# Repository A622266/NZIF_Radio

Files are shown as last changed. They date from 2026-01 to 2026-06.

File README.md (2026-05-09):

# NZIF Radio

Near-zero-IF radio architecture built around an 8-phase harmonic rejection polyphase mixer and audio-rate ADC/DAC signal processing.

This board is the NZIF core: it converts differential RF into low-frequency quadrature baseband, then digitizes and processes the result with audio-rate converters and a SigmaDSP. The RF front-end board handles the PA, T/R switch, a band-switched quasi-elliptic LPF bank shared between TX and RX, a directional coupler for SWR and power measurement at the antenna port, and two receive-path high-pass filters that together form a band-specific preselector. The receive and transmit mixer/baseband cores are on this board.

## Design goals

- Suppress the 3rd, 5th, and 7th LO harmonics with an 8-phase harmonic rejection mixer, reducing reliance on RF bandpass filters on this board.
- Use polyphase mixing and phase-domain harmonic suppression to minimize analog RF selectivity requirements.
- Avoid a conventional high-IF architecture: the design is near-zero-IF, using 192 kHz ADC/DAC sampling with a digital NCO offset to stay away from DC and 1/f noise.
- Keep the Rx and Tx front end compact and fully differential, while placing the PA and post-PA filters on a separate board.
- Preserve differential signal flow from the RF mixer through the driver amps and into the audio-rate converters.
- Share a quasi-elliptic post-PA LPF bank between TX and RX on the RF front-end board: on transmit it suppresses PA harmonics for regulatory compliance; on receive the same bank acts as a band-specific preselector with deep notch traps at adjacent-band interference sources.
- Place a directional coupler at the antenna interface (after the LPF bank) for accurate forward/reflected power and SWR measurement at the clean fundamental; use a calibration tap to inject a spectrally clean reference tone into the receive path for I/Q calibration.
- Apply strategically placed high-pass filters in the receive chain: a fixed ~1.6 MHz filter to block AM broadcast on all bands, and a switched ~9 MHz filter to suppress lower-band interference on 30m and above.

## Architecture overview

### Core concept

The NZIF board uses an 8-phase commutating mixer topology on receive and transmit. In the receive path, differential RF (`RF+`, `RF-`) is sampled by eight phase-shifted switch networks, producing eight baseband phase taps. Opposite phases are then recombined into four differential channels for ADC conversion:

- `BB_0` / `BB_180` → `P0_IN+` / `P0_IN-`
- `BB_45` / `BB_225` → `P45_IN+` / `P45_IN-`
- `BB_90` / `BB_270` → `P90_IN+` / `P90_IN-`
- `BB_135` / `BB_315` → `P135_IN+` / `P135_IN-`

The eight-phase approach provides phase-domain cancellation of odd-order LO harmonics (3rd, 5th, 7th) and reduces the need for RF bandpass filtering on this board.

### Near-zero-IF operation

This is not a classic zero-IF design:

- ADC and DAC converters run at 192 kHz.
- The ADAU1467 DSP uses a digital NCO to shift the effective center frequency away from DC.
- That offset avoids LO leakage and 1/f noise while preserving complex I/Q demodulation.

Because the converters are audio-rate, the RF conversion chain moves entirely into the phase-domain mixer and the digital domain — there is no IF filter bank.

## How the receive signal flows

```
Antenna → Directional coupler (~0.2 dB through) → ZWAS LPF bank (band-switched preselector)
    → T/R switch → HP-1 (~1.6 MHz, fixed) → HP-2 (~9 MHz, switched 30m+)
    → SMA (J101) → 1:1 balun → RF+ / RF-
    → SN74CBT3125C quad switch arrays (×4)
        controlled by phase_0, phase_45, … phase_315
        ├─ BB_0    → ADA4625-2 unity-gain buffer
        ├─ BB_45   → ADA4625-2 unity-gain buffer
        ├─ BB_90   → ADA4625-2 unity-gain buffer
        ├─ BB_135  → ADA4625-2 unity-gain buffer
        ├─ BB_180  → ADA4625-2 unity-gain buffer
        ├─ BB_225  → ADA4625-2 unity-gain buffer
        ├─ BB_270  → ADA4625-2 unity-gain buffer
        └─ BB_315  → ADA4625-2 unity-gain buffer
    → top sheet pairs opposite phases into differential channels:
        BB_0/BB_180   → P0_IN+/P0_IN-
        BB_45/BB_225  → P45_IN+/P45_IN-
        BB_90/BB_270  → P90_IN+/P90_IN-
        BB_135/BB_315 → P135_IN+/P135_IN-
    → ADA4945-1 fully differential amplifiers (×4)
        → P0_FDA+/P0_FDA-, P45_FDA+/P45_FDA-,
          P90_FDA+/P90_FDA-, P135_FDA+/P135_FDA-
    → ADAU1979 4-channel 24-bit ADC (192 kHz)
    → ADAU1467 SigmaDSP: I/Q correction, NCO offset, filter, demodulate
    → ADAU1361 audio codec → headphone/speaker
```

## How the transmit signal flows

```
Mic → ADAU1361 ADC → ADAU1467 DSP (Weaver SSB / CW shaping)
    → ADAU1962A 12-ch DAC (I/Q baseband, 192 kHz)
    → SN74CBTLV3125 switch arrays
        driven by same phase_0 … phase_315 clock lines
    → 8-phase RF reconstruction → RF output
    → RF front-end board: pre-driver → PA → T/R switch
    → ZWAS quasi-elliptic LPF bank (7 filters, harmonic rejection)
    → Directional coupler → antenna
        ├─ Fwd port → detector → Pi Pico ADC (forward power / SWR)
        ├─ Rev port → detector → Pi Pico ADC (reflected power / SWR)
        └─ Tap → HMC1118 → RX path (I/Q calibration reference)
```

## What is on this board

### `nzif/rx_mixer.kicad_sch`

Implements the receive 8-phase polyphase mixer.

- Four **SN74CBT3125CPW** quad bus-switch ICs commutate the differential RF input (`RF+`/`RF-`) onto eight phase-tagged baseband nodes. Two switch ICs handle the `RF+` half of the differential signal; two handle `RF-`. The eight phase-control lines (`phase_0`, `phase_45`, … `phase_315`) are driven from the clock tree.
- Each baseband node is buffered by one section of an **ADA4625-2** unity-gain op-amp. The ADA4625-2 is a dual JFET-input op-amp (3.3 nV/√Hz input noise, rail-to-rail output) that isolates the high-impedance switch nodes from the downstream differential signal chain and prevents charge injection from disturbing adjacent phase taps.

### `nzif/rx_driver_amps.kicad_sch`

Converts the eight single-ended phase outputs into four differential channels for the ADC.

- Four **ADA4945-1** fully differential amplifiers condition the signals. Each ADA4945-1 takes a pair of opposite-phase single-ended inputs and produces a differential output directly suitable for the ADAU1979 differential input. Gain is set by the Rf/Rg resistor network on each channel.
- Outputs: `P0_FDA+/P0_FDA-`, `P45_FDA+/P45_FDA-`, `P90_FDA+/P90_FDA-`, `P135_FDA+/P135_FDA-`.

### `nzif/adcs.kicad_sch`

- Contains the **ADAU1979** 4-channel 24-bit audio ADC.
- Digitizes the four differential baseband pairs at 192 kHz.
- The ADAU1979 is chosen for its 4.5 Vrms differential input range, which provides headroom against strong-signal transients before any AGC correction occurs.

### `nzif/dacs.kicad_sch`

- Contains the **ADAU1962A** 12-channel 24-bit audio DAC.
- Generates the analog transmit I/Q channels for the TX mixer at 192 kHz.
- The 12-channel output provides multiple differential pairs for the TX baseband; the same I2S/TDM protocol used by the ADAU1979 connects directly to the ADAU1467.

### `nzif/tx_mixer.kicad_sch`

- Implements the transmit 8-phase RF reconstruction mixer.
- Uses **SN74CBTLV3125** bus-switch arrays (the 3.3 V-rated LV variant, matched to DAC output levels) to commutate the I/Q baseband onto the 8-phase RF reconstruction network.
- Uses the same `phase_0` … `phase_315` control lines as the receive mixer.

### `nzif/dsp.kicad_sch`

- Contains the **ADAU1467** SigmaDSP (dual-core, 294 MHz).
- Programmed via SigmaStudio (graphical block-diagram, no traditional firmware).
- Receive functions: I/Q DC offset correction, gain and phase trim, NCO fine-tuning (±96 kHz), digital FIR/IIR selectivity filtering, AGC, SSB/CW/AM demodulation (Weaver method).
- Transmit functions: Weaver SSB encoding, CW keying-envelope shaping, TX I/Q baseband generation.
- The Pi Pico writes calibration coefficients and NCO frequency words to ADAU1467 parameter RAM over I2C.

### `nzif/clock_tree.kicad_sch`

Generates the LO and the eight phase-control signals for both the Rx and Tx mixers.

- **AD9523-1** clock generator provides both the RF LO and the system audio MCLK from a single on-chip VCO. The VCO-path outputs drive the phase distribution logic; a separate reference-path output provides a stable fixed MCLK to all audio ICs, completely independent of LO tuning.
- **CTS_535_TCXO** provides the precision reference clock for the AD9523-1 PLL.
- **SN74AUC16374** (16-bit D flip-flop, 2.5V supply) is wired as two independent 8-stage ring counters — one for Rx and one for Tx, using the IC's two independent 8-bit banks. Each counter is a shift-register loop: D2=Q1, D3=Q2, …, D8=Q7, with Q8 (8-phase) or Q4 (4-phase) fed back to D1. A single '1' circulating through the active stages produces the non-overlapping phase pulses that drive the mixer switches.
- **SN74AUC08** quad AND gates (one IC per counter, 2.5V supply) gate the D5–D8 shift connections. When `PHASE_SEL_8` is high, all 8 stages circulate normally (8-phase mode). When `PHASE_SEL_8` is low, D5–D8 are forced to zero, quenching stages 5–8 so only a 4-stage ring (Q1–Q4) remains active (4-phase mode).
- **SN74CBTLV3253** dual 4:1 analog mux (2.5V supply, U705=Rx, U706=Tx) selects both the D1 data input and the counter clock on each band change and during initialisation. The Pico drives S0/S1 (`RX_UC_ADDR0/1`, `TX_UC_ADDR0/1`) to choose one of four modes:

  | S1:S0 | D1 source | Clock source | Purpose |
  |-------|-----------|--------------|---------|
  | 0,0 | GND | `init_clock` (Pico GPIO) | Clear — flush 0s through all stages |
  | 0,1 | 2.5V | `init_clock` | Seed — inject one '1' into D1 |
  | 1,0 | Q4 (`counter_feedback_4`) | `high_speed_clock` (AD9523-1) | 4-phase run (6m band) |
  | 1,1 | Q8 (`counter_feedback_8`) | `high_speed_clock` | 8-phase run (160m–10m) |

- **SN74LVC8T245** dual-supply level translators (U704=Rx, U707=Tx, VCC_A=2.5V, VCC_B=3.3V) convert the 2.5V ring counter Q outputs to the 3.3V levels required by the mixer bus switches, producing `rx_phase_0`…`rx_phase_315` and `tx_phase_0`…`tx_phase_315`.
- **`PHASE_SEL_8`** (Pico GPIO at 3.3V) is divided to ~2.5V by R1226 (10 kΩ series) and R1227 (33 kΩ to GND) before reaching the AUC08 AND gate inputs, keeping the signal within the AUC08 absolute-maximum input of VCC+0.5V = 3.0V at its 2.5V supply.

### `nzif/microcontroller.kicad_sch`

- Contains a **Raspberry Pi Pico** (RP2040, dual-core Arm Cortex-M0+, 133 MHz, 264 kB SRAM, 2 MB flash).
- Controls frequency tuning (programs the AD9523-1 via SPI), manages band changes, runs the I/Q calibration routine, handles front-panel input (rotary encoder, buttons, display), and presents a Hamlib-compatible UART CAT port for logging software.

### `nzif/audio_subsystem.kicad_sch`

- Contains the **ADAU1361** stereo audio codec.
- On receive: DAC output drives headphone/speaker with demodulated audio from the ADAU1467.
- On transmit: ADC input digitizes the microphone and feeds the ADAU1467 DSP.

### `nzif/power_ldos.kicad_sch`

- **LT3045** ultra-low-noise positive LDO (2 μVrms) for precision analog and RF rails.
- **LT3094** ultra-low-noise negative LDO for the bipolar op-amp supply rails.
- LDO choice is driven by the ADC noise floor and LO phase noise — both track supply noise on the precision analog rails.

### `nzif/power_switching_reg.kicad_sch`

- **LT8330** boost converter and **ADP2302/ADP2303** switching regulators for digital rails.

## RF front-end board

The RF front-end board sits between the antenna and the NZIF core and contains all antenna-interface, preselector, PA, and power-measurement functions. It implements the same front-end architecture used in a companion HF superheterodyne transceiver — both designs share this topology at the antenna interface.

### T/R switch

Fast RF switch routing the antenna between receive and transmit paths. Low insertion loss (< 0.3 dB); fast enough for break-in CW operation.

### HP-1 (~1.6 MHz, fixed, receive path only)

Always-in high-pass filter immediately after the T/R switch in the receive path. Blocks AM broadcast (0.535–1.705 MHz), which otherwise passes even through the widest ZWAS LPF (LPF-1 at 2.5 MHz cutoff). Not in the TX path.

### HP-2 (~9 MHz, switched, receive path only)

Pi Pico activates this filter on 30m and above. Rejects 40m (7–7.3 MHz), 80m, and 160m interference when operating on higher bands. At a 9 MHz cutoff, the 40m band edge (7.3 MHz = 0.81× the cutoff) sees 30–40 dB rejection from a 7-pole LC high-pass filter; the 30m band (10.1 MHz = 1.12× the cutoff) passes with < 0.3 dB insertion loss. Together with the ZWAS LP filter, HP-2 creates an effective two-sided passband window (9 MHz to the ZWAS LP cutoff) on 30m and above without requiring a switched bandpass filter bank. Not in the TX path.

### ZWAS quasi-elliptic LPF bank (dual-purpose, shared TX/RX)

Seven switched quasi-elliptic low-pass filters using the Tonne/Elsie ZWAS technique. Each filter is a Chebyshev LPF with one shunt LC trap at the 2nd harmonic of the band group's highest frequency. Pi Pico selects the correct filter by band; the same selection serves TX and RX.

**On transmit:** The trap provides deep notch rejection of the 2nd PA harmonic for regulatory compliance. The LP rolloff handles higher-order harmonics. Together they meet FCC Part 97 spurious emission requirements at 100 W output.

**On receive:** The same trap falls at exactly the next adjacent amateur band up — the most common strong-signal interference source — providing a deep notch preselector. The 80m LPF traps 40m; the 40m LPF traps 20m; and so on.

| Filter | Bands | LP cutoff | ZWAS trap | TX: 2nd harmonic rejected | RX: adjacent-band trap |
|---|---|---|---|---|---|
| LPF-1 | 160m | 2.5 MHz | 3.6 MHz | 2× 1.8 MHz = 3.6 MHz ✓ | 80m lower edge (near trap) |
| LPF-2 | 80m | 5.0 MHz | 7.0 MHz | 2× 3.5 MHz = 7.0 MHz ✓ | **40m — deep notch** |
| LPF-3 | 40m | 9.0 MHz | 14.0 MHz | 2× 7.0 MHz = 14.0 MHz ✓ | **20m — deep notch** |
| LPF-4 | 30m, 20m | 16 MHz | 28.0 MHz | 2× 14 MHz = 28 MHz ✓ | 10m |
| LPF-5 | 17m, 15m | 22 MHz | 36 MHz | 2× 18 MHz = 36 MHz ✓ | 12m/10m edge |
| LPF-6 | 12m, 10m | 32 MHz | 50 MHz | 2× 25 MHz = 50 MHz ✓ | 6m — deep notch |
| LPF-7 | 6m | 60 MHz | 108 MHz | 2× 54 MHz = 108 MHz ✓ | FM broadcast (88–108 MHz) |

### Directional coupler

Dual-transformer design positioned between the ZWAS LPF bank and the antenna, where the signal is a clean fundamental with harmonics already suppressed at a defined 50 Ω interface. Present in both TX and RX paths; through-path insertion loss ~0.2 dB on receive.

- **Forward port**: Coupled to a Schottky diode peak detector; DC output drives a Pi Pico ADC input for forward power measurement.
- **Reflected port**: Coupled to a second Schottky diode peak detector; DC output drives a Pi Pico ADC input for reflected power and SWR display. Fold-back protection is implemented in Pi Pico firmware.
- **Calibration tap**: A third coupled port samples the transmitted signal at low level. An HMC1118 switch routes this tap into the NZIF receive path for I/Q calibration — the tone has already passed through the ZWAS LPF, so it is spectrally clean and within the operating band.

### Effective receive preselector passband (HP-1 + HP-2 + ZWAS)

| Band | HP-2 | ZWAS filter | Effective window | Key rejections |
|---|---|---|---|---|
| 160m | Bypass | LPF-1: 2.5 MHz / trap 3.6 MHz | 1.6–2.5 MHz | 80m (near trap + rolloff), all above |
| 80m | Bypass | LPF-2: 5.0 MHz / trap 7.0 MHz | 1.6–5.0 MHz | **40m deep notch**, all above |
| 60m | Bypass | LPF-3: 9.0 MHz / trap 14.0 MHz | 1.6–9.0 MHz | 20m deep notch, 30m rolloff |
| 40m | Bypass | LPF-3: 9.0 MHz / trap 14.0 MHz | 1.6–9.0 MHz | **20m deep notch**, 30m rolloff |
| 30m | In (9 MHz) | LPF-4: 16 MHz / trap 28.0 MHz | **9–16 MHz** | 40m (30–40 dB), 80m/160m; 10m trap |
| 20m | In (9 MHz) | LPF-4: 16 MHz / trap 28.0 MHz | **9–16 MHz** | 40m (30–40 dB), 80m/160m; 10m trap |
| 17m | In (9 MHz) | LPF-5: 22 MHz / trap 36 MHz | **9–22 MHz** | 40m, SW broadcast, 80m/160m; 12m/10m trap |
| 15m | In (9 MHz) | LPF-5: 22 MHz / trap 36 MHz | **9–22 MHz** | Same as 17m |
| 12m | In (9 MHz) | LPF-6: 32 MHz / trap 50 MHz | **9–32 MHz** | 40m, SW, 20m; 6m trap |
| 10m | In (9 MHz) | LPF-6: 32 MHz / trap 50 MHz | **9–32 MHz** | Same as 12m |
| 6m | In (9 MHz) | LPF-7: 60 MHz / trap 108 MHz | **9–60 MHz** | 40m, SW broadcast, FM broadcast trap |

## LO chain

```
CTS_535_TCXO → AD9523-1 PLL → LO output   (VCO path → SN74AUC16374 ring counters (2.5V)
                                             → SN74AUC08 AND gates (phase-mode select)
                                             → SN74CBTLV3253 init/run mux
                                             → SN74LVC8T245 level shifters (2.5V → 3.3V)
                                             → phase_0 … phase_315 → mixer switch gates)
                            → MCLK output  (reference path, fixed ~12.288 MHz
                                             → ADAU1979, ADAU1467, ADAU1962A, ADAU1361)
```

The AD9523-1 VCO is tuned by the Pi Pico (via SPI) to the operating frequency. The reference-path MCLK output is completely decoupled from VCO tuning, so retuning the LO does not disturb the audio clock.

### Ring counter initialisation

The SN74AUC16374 ring counters can power up in any state. Before the mixers are enabled on every power-up and band change, the Pico runs the following sequence using the 3253 mux and a slow `init_clock` GPIO:

1. **Clear** (S=00, 9+ `init_clock` pulses): D1=GND; clocks 0s through all 8 stages, flushing any spurious bit patterns.
2. **Seed** (S=01, 1 `init_clock` pulse): D1=2.5V; loads a single '1' into Q1 with all other stages already 0.
3. **Set phase mode**: assert `PHASE_SEL_8` high (8-phase) or low (4-phase). The AND gates latch the D5–D8 gating before the high-speed clock starts.
4. **Run** (S=10 for 4-phase, S=11 for 8-phase): switches D1 to the Q4 or Q8 feedback net and the clock source to `high_speed_clock` from the AD9523-1. The single '1' circulates freely at LO rate.

The `init_clock` is a Pico GPIO toggled in firmware at a few kHz — well below any setup/hold concern. `PHASE_SEL_8` must be asserted before switching S to the run state so that stages 5–8 are quenched before Q4 feedback is engaged in 4-phase mode.

### 8-phase vs 4-phase mode

| Parameter | 8-phase (160m–10m) | 4-phase (6m) |
|---|---|---|
| AD9523-1 output divider | ÷8, clock = 8× RF | ÷4, clock = 4× RF |
| Active ring stages | 8 (Q1–Q8) | 4 (Q1–Q4) |
| `PHASE_SEL_8` / D5–D8 | High — pass Q4–Q7 | Low — forced 0 |
| Counter feedback to D1 | Q8 | Q4 |
| Phase pulse width | 45° (1/8 RF period) | 90° (1/4 RF period) |
| Maximum counter clock | ~240 MHz (at 30 MHz RF, 10m) | 216 MHz (at 54 MHz RF, 6m) |
| Odd harmonic cancellation | 3rd, 5th, and 7th cancelled by DSP combining | 3rd and 7th cancelled; 5th passes |

The SN74AUC16374 is rated to a maximum VCC of 2.7V, operated here at 2.5V. At 8× RF for 10m the counter clock reaches ~240 MHz; for 6m, 8-phase would require 400–432 MHz which exceeds the device rating. Switching to 4-phase keeps the clock at ≤216 MHz with margin.

In 8-phase mode the four differential ADC channels (each formed by pairing a phase tap with its 180°-opposite) have linearly independent response vectors for k=1, 3, 5, and 7 — they are distinct rows of the 8-point DFT matrix. The ADAU1467 DSP applies complex combining weights that simultaneously pass the fundamental while zeroing all three harmonic responses. The first unrejected harmonic is the 9th (response to signals at f_LO/9), which falls far outside any amateur band for HF frequencies.

In 4-phase mode (6m) the active taps are only at 0°, 90°, 180°, 270° (Q5–Q8 are quenched). Because the tap spacing is 90°, the 5th harmonic produces the same response vector as the fundamental [1, j, −1, −j], making them indistinguishable. The 3rd and 7th harmonics share the orthogonal vector [1, −j, −1, j] and are both cancelled together. The practical consequence on 6m is a spurious response to signals at f_LO/5 ≈ 10–10.8 MHz (30m band). The HP-2 filter (9 MHz cutoff, active on 6m) provides only modest attenuation at 10 MHz, so strong 30m signals can create interference on 6m in 4-phase mode.

## Why 8-phase harmonic rejection?

A conventional 2-phase (single-switch) commutating mixer has a square-wave LO that contains odd harmonics. The 3rd harmonic at −9.5 dBc (amplitude ratio 1/3) causes a mixing response to signals at f_RF/3 — an unwanted reception at 1/3 of the operating frequency, suppressed only by external bandpass filtering.

The 8-phase architecture cancels these harmonics by phase. Each of the eight switch taps samples the RF with a LO phase that is an integer multiple of 45°. When the eight outputs are recombined, the harmonic responses cancel as rotating phasor sums:

- **3rd harmonic:** each tap's 3rd-harmonic component is phase-shifted by 3 × 45° = 135° relative to adjacent taps. Summing eight equal phasors separated by 135° gives a vector sum of zero. Theoretical rejection: >60 dB.
- **5th harmonic:** 5 × 45° = 225° per step; vector sum ≈ 0. Theoretical rejection: >50 dB.
- **7th harmonic:** 7 × 45° = 315° per step; vector sum ≈ 0. Theoretical rejection: >45 dB.

In practice the rejection is limited by phase and amplitude matching across the SN74CBT3125 switch array, PCB trace symmetry, and timing accuracy of the phase clock distribution. Well-designed 8-phase boards typically achieve 40–55 dB rejection. The 9th harmonic (9 × 45° = 405° ≡ 45°) is not cancelled and passes through — its product at f_RF/9 is far from any amateur band for most HF frequencies.

## Why near-zero-IF?

- No high-frequency IF or fixed IF filter is required, which eliminates a switched crystal or SAW filter bank.
- The ADC and DAC are audio-rate (192 kHz), keeping component cost and complexity low compared to RF-sampling approaches that require multi-GSPS ADCs.
- A digital NCO in the ADAU1467 moves the effective receive center frequency away from DC, avoiding LO leakage and 1/f noise that degrade pure zero-IF designs.
- The ±96 kHz NCO range, combined with 100 kHz LO tuning steps, provides continuous coverage of all HF amateur bands without gaps.

## Architecture comparison

**Traditional superheterodyne with roofing filters** (Elecraft K3, Icom IC-7610): uses a fixed IF and crystal roofing filter to remove out-of-band power before the second mixer. The roofing filter physically limits IMD to strong in-band signals. System IIP3 is typically +15–25 dBm (limited by the active first mixer before the roofing filter). Crystal filters are expensive speciality parts. NZIF relies on phase-domain harmonic rejection and high switch linearity rather than analog selectivity, and achieves IMD performance through linearity rather than filtering.

**Tayloe/quadrature sampling detectors** (4-phase commutating switch at RF → DC): low component count, directly produce I/Q baseband. More sensitive to LO feedthrough and image issues than an 8-phase design. NZIF extends the commutating-switch concept to eight phases, providing stronger odd-harmonic rejection at the cost of a more complex clock distribution.

**NorCal NC2030 (Tayloe, N7VE):** The closest published benchmark — a 4-phase direct-conversion phasing receiver with a narrow-band audio preamp (1.5 kHz BW). Measured specs: MDS −135 dBm (→ system NF ≈ 12 dB at 500 Hz BW), system IIP3 ≈ +28.5 dBm (calculated from measured IP3 DR plateau of 109 dB), BDR 119–142 dB across 2–20 kHz spacing. Image rejection >45 dB. CW-only, two bands, ~11 mA at 12 V. The NC2030's narrow audio preamp inherently rejects far-off blockers before the compression point — a genuine direct-conversion advantage. NZIF targets comparable IIP3 with 8-phase harmonic rejection in place of the analog phasing network.

**Norcal 2030 / direct sampling:** samples HF at very high ADC rates and moves all selectivity into the digital domain. Maximum flexibility but requires multi-GSPS ADCs (high cost, high power, ~15–25 W). NZIF achieves a comparable digital-first philosophy with audio-rate converters by using a polyphase analog front end and NCO offset.

## Key component rationale

| Part | Role | Why this part |
|---|---|---|
| SN74CBT3125CPW | Rx polyphase mixer switches | Logic-level LO drive; four switches per IC; rated 5 V for Rx chain; low on-resistance CMOS bus switch |
| SN74CBTLV3125 | Tx polyphase mixer switches | Same topology as Rx, 3.3 V-rated LV variant to match DAC output levels |
| ADA4625-2 | Baseband node buffers (Rx mixer) | Dual JFET op-amp, 3.3 nV/√Hz, unity-gain stable; isolates high-impedance switch nodes from the differential driver chain without loading the switching node |
| ADA4945-1 | Rx differential driver amps | Fully differential amplifier; converts single-ended phase-buffer outputs to the differential signal required by ADAU1979; maintains fully balanced path from mixer to ADC |
| ADAU1979 | 4-channel 24-bit Rx ADC | 4.5 Vrms differential input range prevents ADC clipping during strong-signal transients; 192 kHz max sample rate; I2S/TDM connects directly to ADAU1467 |
| ADAU1962A | 12-channel 24-bit Tx DAC | Multi-channel differential DAC for Tx I/Q baseband; I2S/TDM from ADAU1467; same Analog Devices audio ecosystem ensures compatible clocking and protocol |
| ADAU1467 | SigmaDSP core | 294 MHz dual-core fixed-point DSP; SigmaStudio graphical programming; integrates NCO, FIR/IIR filter bank, AGC, I/Q calibration, and demodulation in one chip; direct I2C parameter RAM access for runtime calibration updates from the Pi Pico |
| AD9523-1 | Clock generator | 14 independent outputs; single VCO generates both the variable RF LO and a fixed audio MCLK via the reference-path output; −226 dBc/Hz FOM; eliminates a separate audio oscillator |
| CTS_535_TCXO | Frequency reference | < 2 ppm TCXO stability adequate for amateur digital modes (FT8 requires < 1 Hz accuracy at HF, ≈ 0.1 ppm at 10 MHz) without oven complexity |
| Raspberry Pi Pico (RP2040) | Radio controller | Dual-core Arm M0+, 133 MHz; SPI for AD9523-1 and peripherals; I2C for ADAU1467 parameter RAM; GPIO for band switching; USB for CAT; low cost, widely available |
| LT3045 / LT3094 | Precision LDOs | 2 μVrms output noise; required to keep LDO supply noise below the ADC noise floor and avoid degrading LO phase noise on precision analog rails |

## LO band plan and coverage

The NZIF radio covers all amateur HF bands (160m through 10m) plus 6m. The LO is tuned directly to the operating frequency in 100 kHz tiles; the ADAU1467 NCO provides ±96 kHz fine-tuning within each tile, ensuring continuous coverage without gaps.

8-phase mixing is used through 10m. On 6m (50–54 MHz), the clock tree switches to 4-phase operation because 8-phase would require the phase register to operate at 400 MHz, beyond the SN74AUC16374's rated speed.

| Band | Frequency range (MHz) | LO range (MHz) | Phase mode | NCO range (kHz) | Coverage |
|---|---|---|---|---|---|
| 160m | 1.800 – 2.000 | 1.800 – 2.000 | 8-phase | ±96 | Complete |
| 80m  | 3.500 – 4.000 | 3.500 – 4.000 | 8-phase | ±96 | CW and SSB |
| 60m  | 5.330 – 5.405 | 5.330 – 5.405 | 8-phase | ±96 | Channelized, full coverage |
| 40m  | 7.000 – 7.300 | 7.000 – 7.300 | 8-phase | ±96 | Complete |
| 30m  | 10.100 – 10.150 | 10.100 – 10.150 | 8-phase | ±96 | Complete |
| 20m  | 14.000 – 14.350 | 14.000 – 14.350 | 8-phase | ±96 | Complete |
| 17m  | 18.068 – 18.168 | 18.068 – 18.168 | 8-phase | ±96 | Complete |
| 15m  | 21.000 – 21.450 | 21.000 – 21.450 | 8-phase | ±96 | Complete |
| 12m  | 24.890 – 24.990 | 24.890 – 24.990 | 8-phase | ±96 | Complete |
| 10m  | 28.000 – 29.700 | 28.000 – 29.700 | 8-phase | ±96 | Complete |
| 6m | 50.000 – 54.000 | 50.000 – 54.000 | 4-phase | ±96 | Reduced to 4-phase (clock rate limit) |

## Performance characteristics

### Signal chain and noise figure

The NZIF receive chain has no dedicated on-board LNA between the antenna port and the polyphase mixer. Noise figure and linearity are set by the SN74CBT3125 switch conversion loss and the ADA4625-2 / ADA4945-1 input noise.

**Estimated figures (cascade analysis; bring-up measurement required):**

- **System NF:** ~6–9 dB. Polyphase mixer conversion loss approximately 6 dB (dominated by switch Rds(on) and signal distribution to eight phases); ADA4625-2 contributes ~2–3 dB NF at baseband. Any gain provided by the RF front-end board directly improves this figure.
- **System IIP3:** Estimated +25–35 dBm at the antenna port. The SN74CBT3125 is not characterized as an RF mixer component; IIP3 must be measured during bring-up. The differential topology and high switch bandwidth suggest competitive linearity.
- **Harmonic rejection:** Theoretical >60 dB (3rd), >50 dB (5th), >45 dB (7th) from ideal 8-phase phase-domain cancellation. Practical expectation for a well-built board: 40–55 dB, limited by phase-clock timing accuracy and switch Rds(on) matching across the four ICs.
- **ADC SNR:** 110–115 dB (ADAU1979 at 192 kHz, 24-bit).
- **DAC THD+N:** < 0.005% (ADAU1962A at 192 kHz, 12-channel differential output).

### Comparison to published benchmarks

The NC2030 (Tayloe, N7VE) is the closest published measured benchmark: a 4-phase direct-conversion phasing receiver with a narrow-band audio preamp. Its specs are bench-measured; NZIF figures are estimated from cascade analysis.

| Metric | NC2030 (measured) | NZIF (estimated) |
|---|---|---|
| System NF | ~12 dB (from MDS = −135 dBm at 500 Hz BW) | ~6–9 dB |
| System IIP3 | +28.5 dBm (from IP3 DR plateau = 109 dB) | +25–35 dBm (TBD) |
| Harmonic rejection | >45 dB (phasing network) | >40–55 dB (8-phase cancellation) |
| Instantaneous BW | ~1.5 kHz (audio preamp) | ±96 kHz (ADC + NCO) |
| Modes | CW only (2 bands) | All modes, all HF + 6m |
| Power | ~0.13 W | ~5–8 W |

**Why we should beat NC2030 on sensitivity:** No audio preamp compression bottleneck; the ADA4945-1 + ADAU1979 chain handles much wider bandwidth before limiting. The 8-phase architecture extends coverage to all HF bands.

**Where NC2030 has an inherent advantage:** The NC2030's narrow audio preamp (1.5 kHz BW, −39 dB rolloff at 20 kHz) acts as pre-compression selectivity — blockers 20 kHz away are attenuated 39 dB before the compression point. NZIF's wideband chain sees the full RF spectrum at the switch input; selectivity is applied only after the ADC.

**Caveat:** All NZIF figures are calculated estimates. NC2030's are bench-measured. Bring-up measurement is required to validate NZIF performance.

### Comparison to other HF receiver architectures

| Architecture | NF (dB) | IIP3 (dBm) | Harmonic rejection | Power (W) | Notes |
|---|---|---|---|---|---|
| NZIF (8-phase, est.) | 6–9 | +25–35 (est.) | 40–55 dB odd harmonics | 5–8 | No on-board LNA; measured values TBD |
| NC2030 (measured) | ~12 | +28.5 | >45 dB (phasing) | ~0.13 | CW only, 2 bands, narrow audio preamp |
| Traditional superhet | 8–12 | +15–25 | Good (with roofing filter) | 10–15 | Crystal roofing filter limits IMD |
| Direct sampling | 5–7 | +35+ | Excellent (digital) | 15–25 | High-speed ADCs required |
| Companion HF superhet (KISS, calc.) | ~6.2 | +33 / +42 (LNA bypassed) | ≥70 dB (IF architecture) | ~10–15 | Identical front-end board; bring-up measurements will benchmark NZIF |

## Software architecture

Three processors divide the control and signal-processing work with non-overlapping roles.

### Raspberry Pi Pico (RP2040) — radio control layer

Programs hardware registers: AD9523-1 LO frequency and phase dividers (via SPI), band switching, PE4312 or equivalent AGC attenuator, front-panel encoder and buttons, OLED/TFT display. Runs the I/Q calibration routine at power-up and on each band change. Presents a Hamlib-compatible UART CAT port to an optionally connected PC for logging software (N1MM+, WSJT-X, fldigi, etc.).

### ADAU1467 (SigmaDSP) — baseband DSP layer

Receives 24-bit I/Q samples from the ADAU1979 at 192 kHz. SigmaStudio blocks implement in sequence:

- **I/Q correction matrix**: DC offset subtraction, gain trim, and phase trim applied before any demodulation. Coefficients written by the Pi Pico via I2C parameter RAM.
- **NCO**: digital quadrature oscillator (±96 kHz range) providing fine frequency offset between AD9523-1 PLL steps. Frequency word written by the Pi Pico at each tuning step.
- **Weaver demodulator**: the 8-phase mixer hardware provides the first quadrature mixing stage. The ADAU1467 completes the Weaver second stage — a second NCO at the audio center frequency followed by matched lowpass filters. Summing the two paths selects USB; subtracting selects LSB. AM demodulation uses envelope detection on the corrected I/Q magnitude.
- **Selectivity filters**: the lowpass filters following the second Weaver mixing stage define channel bandwidth. Multiple width settings (2.4 kHz SSB, 500 Hz CW, 6 kHz AM) are selectable by the Pi Pico over I2C.
- **AGC**: operates after the narrowband filter where processing gain has already improved effective SNR. Level detector drives the attenuator control for fast AGC.

On transmit: the ADAU1467 accepts microphone audio from the ADAU1361, applies Weaver SSB encoding, generates CW keying envelopes, and outputs I/Q baseband to the ADAU1962A DAC.

### I/Q calibration (Pi Pico, runs at power-up and each band change)

The polyphase mixer introduces three imperfections that degrade SSB image rejection: DC offset from CMOS switch charge injection, I/Q gain imbalance from switch Rds(on) mismatch between channels, and I/Q phase imbalance from clock distribution skew. The ADAU1467 applies a 2×2 correction matrix:

```
I_corr = I_raw − DC_I
Q_corr = (I_raw − DC_I) × sin(ε) + (Q_raw − DC_Q) × cos(ε) × g
```

Two calibration methods run in sequence:

1. **Noise covariance (fast, no external stimulus)**: thermal noise has equal power on I and Q and zero cross-correlation. Non-zero cross-correlation or power imbalance directly indicates gain or phase error. The Pi Pico reads accumulated I/Q statistics from ADAU1467 readback cells (via I2C), computes the correction matrix algebraically, and writes the result to parameter RAM. Converges in < 1 s.

2. **Tone injection (confirms result)**: the Pi Pico temporarily programs a known NCO offset and injects a reference tone into the RX path. A real-valued tone on the RF input should produce a single-sideband ADAU1467 response; residual image power measured from ADAU1467 readback registers indicates remaining I/Q imbalance. The Pi Pico iterates correction coefficients until image rejection ≥ 50 dB.

## Open items

The schematic review (see [`nzif/docs/schematic_review_report.md`](nzif/docs/schematic_review_report.md)) identified critical issues that must be resolved before layout. Status: **HOLD — do not proceed to layout freeze until Critical items are resolved.**

Key critical issues:

1. **Power symbol IDs on custom rails**: wrong library IDs on custom rails in `rx_mixer` and `rx_driver_amps` (e.g., `power:+5V` used for `−3.5V_RX_OPAMPS`) — netlist cross-connections will short rails and destroy components.
2. **LT3045 feedback resistors**: missing "k" suffix causes values to read as 49.9 Ω instead of 49.9 kΩ — all affected LDO rails produce near-zero output voltage.
3. **LT8330 / ADP2303 feedback**: wrong resistor values produce incorrect output voltages on multiple switching regulator rails.
4. **AD9523-1 VCXO control (R701)**: 1 kΩ value gives 11 kΩ total load, below the 20 kΩ minimum — VCXO control voltage corrupted, PLL will not lock.
5. **U706 part/value mismatch**: symbol is SN74CBT3253 (5 V rated); value is SN74CBTLV3253 (3.6 V max) — wrong device assembled at 5 V will be destroyed.
6. **ADAU1962A AVDD supply label**: "2.5V" label on AVDD pins (minimum 3.0 V) — DAC operates out of spec or fails to power up.
7. **LT3045 / LT3094 output capacitors**: 4.7 µF fitted; 10 µF ceramic minimum for LDO stability — LDOs will oscillate on precision analog rails.
8. **TX mixer RF reconstruction filter absent**: no output filter shown in `tx_mixer.kicad_sch` — required before the PA interface to suppress harmonics.
9. **ADA4945-1 feedback capacitors**: all DNP in the current schematic — oscillation risk at the differential driver outputs.

## Links to the main schematic sheets

- `nzif/nzif.kicad_sch` — top-level board interconnects.
- `nzif/rx_mixer.kicad_sch` — 8-phase receive mixer.
- `nzif/tx_mixer.kicad_sch` — transmit mixer/modulator.
- `nzif/rx_driver_amps.kicad_sch` — baseband conditioning for the ADC.
- `nzif/adcs.kicad_sch` — ADAU1979 ADC interface.
- `nzif/dacs.kicad_sch` — ADAU1962A DAC interface.
- `nzif/dsp.kicad_sch` — ADAU1467 DSP and audio/serial signal flow.
- `nzif/clock_tree.kicad_sch` — phase clocking and timing.
- `nzif/microcontroller.kicad_sch` — Raspberry Pi Pico control logic.
- `nzif/audio_subsystem.kicad_sch` — ADAU1361 audio codec (mic/speaker interface).
- `nzif/power_ldos.kicad_sch` — LT3045/LT3094 LDO regulators.
- `nzif/power_switching_reg.kicad_sch` — LT8330/ADP2302/ADP2303 switching supplies.

## Files in this repo

- `README.md` — this file.
- `NOTES.md` — supplemental design notes and signal-flow derivations.
- `rxmixer.md` — detailed description of the receive 8-phase mixer.
- `nzif/...` — KiCad schematic source files.
- `nzif/docs/schematic_review_report.md` — schematic review findings (Critical items block layout freeze).
- `firmware/...` — Pico firmware and USB/CAT bring-up support.
- `.claude/...` — agent files used for review workflows.

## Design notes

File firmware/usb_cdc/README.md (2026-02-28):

# USB CDC CAT (Pico SDK)

Minimal USB CDC prototype for Kenwood-style CAT commands over a USB virtual serial port.

## Supported commands (initial)
- `FA` / `FB` (get/set VFO A/B frequency in Hz, 11 digits)
- `FR` / `FT` (select RX/TX VFO)
- `MD` (get/set mode)
- `TX` / `RX` (PTT)
- `ID` (returns Kenwood TS-2000 ID)
- `AI` (auto information off)
- `IF` (structured response)
- `AG` / `RG` (AF/RF gain)
- `SM` (S-meter)
- `GT` (AGC)
- `KS` / `KY` (keyer speed / CW text ack)

## What This Does (Non-Programmer Summary)
- The Pico appears as a USB serial device when plugged in normally.
- Software can send CAT commands like `FA;` or `IF;` over USB.
- The firmware replies with simple, valid Kenwood-style responses.

## Step-by-Step (Linux)
### 1) Install build tools and Pico SDK
```bash
sudo apt update
sudo apt install -y cmake ninja-build gcc-arm-none-eabi libnewlib-arm-none-eabi build-essential git

mkdir -p ~/pico
cd ~/pico
git clone https://github.com/raspberrypi/pico-sdk.git
cd pico-sdk
git submodule update --init
```

### 2) Build the firmware
```bash
cd ~/Documents/ham_radio/NZIF_Radio/firmware/usb_cdc
mkdir -p build
cd build
PICO_SDK_PATH=~/pico/pico-sdk cmake -G Ninja ..
cmake --build .
```

### 3) Flash the Pico (BOOTSEL mode)
1. Unplug the Pico.
2. Hold **BOOTSEL** and plug in USB.
3. You should see a drive named `RPI-RP2`.
4. Copy the UF2 file:
```bash
cp ~/Documents/ham_radio/NZIF_Radio/firmware/usb_cdc/build/nzif_usb_cdc.uf2 /media/$USER/RPI-RP2/
```
The Pico reboots after the copy.

### 4) Find the serial device
```bash
ls /dev/ttyACM*
```
Typical output: `/dev/ttyACM0`

### 5) Run the CAT test script
```bash
cd ~/Documents/ham_radio/NZIF_Radio
chmod +x scripts/cat_test.sh
./scripts/cat_test.sh /dev/ttyACM0
```

Expected output looks like:
```
> FA;
< FA00014070000;

> IF;
< IF00014070000000000000000000002000;
```

## Step-by-Step (Collaborator Checklist)
1. Install tools + Pico SDK (Step 1).
2. Build the firmware (Step 2).
3. Flash the Pico (Step 3).
4. Find the serial device (Step 4).
5. Run the test script (Step 5).

## Optional: Stable Device Names
Linux already provides stable names under `/dev/serial/by-id/`. You can use those in the test script instead of `/dev/ttyACM0`.

If you prefer a short custom name, add a udev rule (example):
```bash
echo 'SUBSYSTEM=="tty", ATTRS{idVendor}=="2e8a", ATTRS{idProduct}=="000a", SYMLINK+="pico-cat-%s{serial}", GROUP="dialout", MODE="0660"' | sudo tee /etc/udev/rules.d/99-pico-cat.rules
sudo udevadm control --reload-rules && sudo udevadm trigger
```
Then use `/dev/pico-cat-<serial>` in the test script.

## Troubleshooting
- **Pico does not show up in `lsusb`:** Try a different USB cable (many are charge-only) and a different port.
- **No `RPI-RP2` drive in BOOTSEL mode:** Hold **BOOTSEL** while plugging in, and keep it held for 2–3 seconds.
- **No `/dev/ttyACM0` after flashing:** Unplug and replug *without* BOOTSEL. The Pico should appear as a CDC device.
- **`screen` says permission denied:** Add your user to the `dialout` group: `sudo usermod -a -G dialout $USER`, then log out/in.
- **Test script shows no responses:** Make sure commands end with `;` and use the updated script: `./scripts/cat_test.sh /dev/ttyACM0`.

## Build (Windows)
1. Install Pico SDK and set `PICO_SDK_PATH`.
2. From a build directory:
   - Configure: `cmake -G "Ninja" ..`
   - Build: `cmake --build .`

## Quick CAT test (Windows)
Use the PowerShell script in [scripts/cat_test.ps1](scripts/cat_test.ps1):

- Example: `powershell -File .\scripts\cat_test.ps1 -Port COM5`

## Notes
This is a bring-up stub meant to confirm USB CDC and basic CAT parsing. The `IF` response is structured but still simplified and should be expanded for full compatibility.

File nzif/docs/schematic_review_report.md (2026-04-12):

# NZIF Radio RF Schematic Review — Consolidated Report

**Project:** NZIF Radio RF  
**Review Date:** 2026-04-11  
**Sheets Reviewed:** audio_subsystem, clock_tree, power_switching_reg, power_ldos, adcs, dacs, rx_mixer, tx_mixer, rx_driver_amps, nzif, dsp, microcontroller  
**Status: HOLD — Do not proceed to layout freeze until Critical items are resolved**

---

## 1. Executive Summary — Top 10 Must-Fix Items

The six domain reviews identified **9 Critical**, **20+ High**, and numerous Moderate findings. The items below represent existential risks to board functionality or component survival and must be resolved before any layout work proceeds.

| # | Area | Issue | Risk |
|---|---|---|---|
| 1 | **RF — Power Symbols** | Wrong lib_ids on all custom rails in rx_mixer and rx_driver_amps (power:+5V/+6V used for −3.5V, +3.3V, +6.5V nets) | Netlist cross-connects rails; −3.5V_RX_OPAMPS shorts to +5V global; ADG884 destruction guaranteed |
| 2 | **Power LDOs** | R903/R907/R908/R909 values missing "k" suffix (read as 49.9Ω not 49.9kΩ) → LT3045 SET pins receive 49.9Ω → V_OUT ≈ 5mV on all affected rails | All rails powered by these LDOs produce near-zero voltage; complete subsystem failure |
| 3 | **Power Switching** | R1101/R1102 (LT8330): feedback resistors produce −1.79V, not −5V. R1103/R1104 (ADP2303): 100k/100k produces 1.6V, not 4V. Six further resistors have empty Value fields | Multiple supply rails at wrong voltages; dependent circuits receive incorrect supply |
| 4 | **Clock Tree** | OSC_CTRL net: R701=1kΩ gives 11kΩ load at AD9523-1 pin 8, below 20kΩ minimum — VCXO control voltage corrupted; PLL will not lock | Radio is inoperable without a locked reference clock |
| 5 | **Clock Tree** | U706 part/value mismatch: symbol = SN74CBT3253 (5V), value = SN74CBTLV3253 (LV, 3.6V max) annotated "Rx switches are 5V" | Wrong device assembled; either functionality fails or 3.6V-max device is destroyed at 5V |
| 6 | **Precision/DACs** | ADAU1962A (U601/U602): "2.5V" local label may drive AVDD pins — AVDD minimum is 3.0V | DAC operates out of spec or fails to power up; no audio output |
| 7 | **Power LDOs** | LT3045 output capacitors at 4.7µF (multiple instances) and LT3094 C931=4.7µF — both below 10µF ceramic minimum for LDO stability | LDO oscillation; noisy or unregulated output on precision analog rails |
| 8 | **Audio** | Net label "DVDOUT" should be "DVDDOUT" — potential CM/DVDDOUT net merger causes codec common-mode to be shorted to digital supply | Codec ADAU1361 malfunction; possible device damage |
| 9 | **Precision/ADCs** | #PWR0406 uses lib_id power:+3.3V for "+3.3V_CONVERTER" net → AVDD joins global +3.3V net instead of isolated converter rail | ADC analog supply contaminated by digital noise; defeats supply isolation intent |
| 10 | **Clock Tree** | AD9523-1 PLL1 external loop filter cap (pin 7, LF1_EXT_CAP) not confirmed present — PLL1 cannot lock | Downstream clocks derived from PLL1 are absent or jitter-dominated |

**Additional urgent items not in the top 10:** RF reconstruction filter absent from tx_mixer sheet; ADA4945-1 feedback caps all DNP (oscillation risk); R910 produces 1.65V not 1.8V on +1.8V_CLOCKTREE rail.

---

## 2. Per-Sheet Findings

### 2.1 audio_subsystem.kicad_sch

| Priority | Ref | Net / Pin | Issue | Action |
|---|-----|---|---|---|
| CRITICAL | U1202 (SSM2211S) | 5V_LOUDSPEAKER / LOUTP | Speaker- wire at y=152.4/177.8 in proximity to 5V_LOUDSPEAKER at y=157.48 — possible shared node creating supply-to-output short | Verify no junction; inspect netlist for Speaker- node connection to 5V_LOUDSPEAKER |
| CRITICAL | ADAU1361 | DVDDOUT / CM | Net label reads "DVDOUT" — missing second D; may merge CM and DVDDOUT nets | Rename label to "DVDDOUT"; run ERC to confirm nets are distinct |
| HIGH | U1202 (SSM2211S) | Pin 6 / 5V_LOUDSPEAKER | Only 0.1µF C1214 on 5V supply; peak current ≈400mA requires bulk bypass | Add 10–47µF bulk cap at pin 6 |
| HIGH | ADAU1361 | SDA / SCL / IOVDD | I2C pull-up resistors (2kΩ to IOVDD) not confirmed on SDA/SCL in this sheet or parent | Confirm pull-ups exist at exactly one point in hierarchy; add if absent |
| HIGH | C12xx, R12xx (all) | — | All passive footprints are blank | Assign footprints before layout freeze |
| MODERATE | ADAU1361 | LINP (pin 10) / CM | LINP tied to CM — confirm intentional single-ended input on LINN only | Document design intent; if differential not needed, mark with schematic note |
| MODERATE | ADAU1361 | RINP/RINN/RAUX (pins 12/13/14) | No-connect markers present; datasheet requires connection to CM | Connect all three to CM net or confirm datasheet revision permits NC |
| MODERATE | C1215, C1216 | Headphone output | 220µF polarized coupling caps — polarity unverified; fc≈22.6Hz into 32Ω load, marginal | Verify polarity; consider 470µF for fc≈11Hz margin |
| MODERATE | C1212 | SSM2211S BYPASS (pin 2) | 0.47µF fitted; datasheet recommends 1µF for PSRR | Change to 1µF |
| MODERATE | — | Audio inputs | No RF EMI filter caps on any audio input — board is in RF radio environment | Add RC or ferrite+C EMI filter on each audio input trace |
| MODERATE | U1202 / ADAU1361 | LOUTP / LOUTN | Shared between headphone output and SSM2211S input — noise coupling path | Review routing; add isolation if simultaneous use intended |
| MINOR | ADAU1361 | JACKDET/MICIN (pin 4) | No-connect on digital input pin — undefined logic level | Add pull resistor to defined level (IOVDD or GND) |
| MINOR | ADAU1361 | ADDR0 / ADDR1 | Both tied GND → I2C address 0x38 | Confirm firmware initialises to address 0x38 |
| MINOR | R1201 | MIC_IN | 49.9kΩ shunt shifts DC bias on MIC_IN — verify operating point is within codec input range | Simulate or calculate DC bias with mic capsule source impedance |

---

### 2.2 clock_tree.kicad_sch

| Priority | Ref | Net / Pin | Issue | Action |
|---|-----|---|---|---|
| CRITICAL | R701 / U702 (AD9523-1) | OSC_CTRL / Pin 8 | R701=1kΩ → total load 11kΩ, below 20kΩ minimum per AD9523-1 Table 5 — VCXO VC voltage corrupted | Increase R701 to ≥10kΩ (recommended ≥20kΩ) |
| CRITICAL | U706 (SN74CBT/LV3253) | VCC / 5V | Symbol lib_id = SN74CBT3253 (5V rated), value = SN74CBTLV3253 (LV, 3.6V max); sheet note says "5V" | Resolve to SN74CBT3253 (5V) on Rx side; update symbol, value, and BOM |
| HIGH | U702 (AD9523-1) | LF1_EXT_CAP (pin 7) | PLL1 external loop filter capacitor not confirmed present — PLL1 cannot lock | Add loop filter cap per AD9523-1 datasheet Table; confirm net connects to capacitor to GND |
| HIGH | X701 (CTS 535 TCXO) | EOH / Vc | EOH enable pin connection and Vc control voltage not confirmed; undriven EOH disables oscillator | Confirm EOH driven to enable state; confirm Vc connected to OSC_CTRL or pulled appropriately |
| HIGH | U702 (AD9523-1) | ZD_IN / ZD_IN_b (pins 70/71) | Zero-delay input pins not confirmed driven or terminated | Drive ZD_IN/ZD_IN_b with reference or terminate per datasheet zero-delay bypass mode |
| HIGH | X701, U704, U707 | — | Footprints missing on CTS 535 TCXO (X701), both SN74LVC8T245 (U704, U707) | Assign footprints; confirm package selection |
| MODERATE | C730, C732, C734 | LDO_PLL1 / LDO_VCO / LDO_DIV_M1 | Three 0.47µF bypass caps — verify each individually covers its designated LDO output pin | Confirm one cap per LDO; add if shared or absent |
| MODERATE | U703 (SN74AUC16374) | OE / 1.8V | OE pull-up to 1.8V not confirmed — undefined state during power-up/down | Add explicit pull-up to 1.8V supply on OE pin |
| MODERATE | TR701 (ADT1-1) | SMA reference input | No 50Ω primary termination on SMA reference input | Add 50Ω termination at SMA; confirm transformer primary sees 50Ω source |
| MODERATE | U702 (AD9523-1) | OSC_IN_b (pin 10) | Complementary AC-grounding not confirmed for single-ended clock input mode | Connect OSC_IN_b to AC ground (100nF to GND) per datasheet single-ended input configuration |
| MODERATE | — | Entire sheet | No frequency plan annotation — no way to verify divider settings by inspection | Add schematic note: reference freq, PLL1/PLL2 VCO freq, all output divider settings, final output frequencies |
| MODERATE | U705, U706 | Mux outputs | Outputs may float when OE_b is high | Add weak pull-down or bus-hold on all mux outputs; confirm OE_b sequencing |

---

### 2.3 power_switching_reg.kicad_sch

| Priority | Ref | Net / Pin | Issue | Action |
|---|-----|---|---|---|
| CRITICAL | R1101, R1102 | LT8330 (U1101) feedback | 1MΩ/806kΩ → V_OUT=−1.79V, not −5V. For −5V with R_lower=806kΩ: R_upper must be ≈4.23MΩ | Replace R1101 with 4.23MΩ (nearest E96: 4.22MΩ); verify formula with selected values |
| CRITICAL | R1103, R1104 | ADP2303 (U1102) feedback | 100kΩ/100kΩ → V_OUT=1.6V via V_OUT=0.8×(1+R_TOP/R_BOT), not 4V. For 4V: R_TOP/R_BOT=4; use 400kΩ/100kΩ | Replace R1103 with 400kΩ; recalculate all ADP2303 feedback pairs from first principles |
| CRITICAL | R1108–R1113 | Multiple rails | Six resistors have empty Value fields — output voltages for multiple rails undefined | Calculate and fill all six values before any further review |
| HIGH | U1102, U1103, U1104 (ADP2303) | PGOOD pins | PGOOD pins have no pull-up resistors and no no-connect markers — power-good function unresolved | Add 100kΩ pull-up to appropriate rail on each PGOOD; or place no-connect and document reason |
| HIGH | R1108, R1109 | LT8330 (U1101) EN/UVLO | Values empty → UVLO threshold undefined | Calculate EN resistor divider for correct UVLO; populate values |
| HIGH | L1102, L1103, L1104 | ADP2303 | 3.3µH inductors fitted; datasheet recommends 4.7µH — higher ripple current, potential saturation | Change to 4.7µH with adequate saturation current rating; verify DCR |
| MODERATE | D1104 (PMEG6010CEJ) | — | 1A rated device — confirm not placed as catch diode in a 3A path | Verify peak inductor current; uprate diode if needed |
| MODERATE | Title block | — | Rev field reads "0.-" — typographic error | Correct to proper revision string |
| MODERATE | Title block | — | Callsign inconsistent with other sheets | Standardise callsign/project name across all title blocks |

---

### 2.4 power_ldos.kicad_sch

| Priority | Ref | Net / Pin | Issue | Action |
|---|-----|---|---|---|
| CRITICAL | R903, R907, R908, R909 | LT3045 SET pins | Value "49.9" missing "k" suffix → parsed as 49.9Ω → V_OUT≈5mV on all affected rails | Change all four values to "49.9k"; recalculate which resistor sets which rail voltage |
| CRITICAL | Multiple LT3045 instances | LDO output | Multiple output caps at 4.7µF — LT3045 minimum for stability is 10µF ceramic | Replace with 10µF X5R/X7R 0805 on each LT3045 output; verify MLCC voltage derating |
| HIGH | R910 | +1.8V_CLOCKTREE SET | 16.5kΩ → V_OUT=1.65V, not 1.8V. For 1.8V: R_SET=18.0kΩ | Replace R910 with 18.0kΩ (E96: 18.0kΩ) |
| HIGH | U9xx (LT3045) | +3.3V_CONVERTERS IN | 4V input, 3.3V output: only 700mV headroom — marginal at full load and temperature | Review input source; target ≥4.5V input to LT3045 feeding +3.3V_CONVERTERS |
| HIGH | U904 (LT3094) | Output / C931 | C931=4.7µF below 10µF minimum for LT3094 stability | Replace C931 with 10µF |
| HIGH | All LT3045 instances | SET bypass cap | 0.47µF SET bypass cap must be present on each LT3045 SET pin — verify all instances | Check each LT3045 in sheet; confirm bypass cap populates at SET pin |
| HIGH | C913, C917, C922 | SET bypass / LT3045 | Value "04.7u" (leading zero) — if intended as 0.47µF (470nF) confirm; if 4.7µF, 10× error on SET bypass function | Clarify intended value; correct notation to "470n" or "0.47u"; re-evaluate PSRR impact |
| HIGH | All rails | — | No power sequencing: PGOOD not connected to LDO enables; all rails rise simultaneously | Define sequencing requirement; connect PGOOD outputs to downstream LDO EN pins or add sequencer |
| MODERATE | All LT3045 instances | EN/UV pins | EN/UV left no-connected — no remote shutdown or sequencing capability | If sequencing required, connect EN; otherwise document deliberate NC with rationale |
| MODERATE | U904 (LT3094) | VIOC (pin 7) | VIOC pin disposition unconfirmed — must not be accidentally driven | Verify pin 7 is explicitly no-connected or properly terminated per datasheet |
| MODERATE | R911, R912 | 20mΩ ballast resistors | Implemented as discrete 0603 — datasheet recommends PCB trace for thermal tracking | Consider replacing with PCB trace resistance; if discrete must be used, ensure thermal coupling |
| MODERATE | — | ADP2303 → LT3045 | No ferrite bead between ADP2303 8V output and LT3045 IN pins — switcher noise degrades LDO PSRR at 700kHz | Add ferrite bead (e.g., 600Ω @ 100MHz) + 10µF cap between converter output and LDO input |

---

### 2.5 adcs.kicad_sch

| Priority | Ref | Net / Pin | Issue | Action |
|---|-----|---|---|---|
| CRITICAL | #PWR0406 | +3.3V_CONVERTER / AVDD | lib_id = power:+3.3V → net joins global +3.3V, not isolated converter rail; AVDD contaminated | Create dedicated power symbol for +3.3V_CONVERTER; do not reuse global power symbol |
| HIGH | U401 (ADA4807-1) | DISABLE (pin 5) | DISABLE pin connection not confirmed; undriven pin may disable amplifier | Tie DISABLE to V+ (supply rail) to keep amplifier permanently enabled, or connect to control GPIO |
| HIGH | AIN pairs (all) | AIN+ / AIN− | No differential shunt capacitor across AIN pairs — only 10Ω series resistors; no anti-aliasing Cdiff | Add 100–470pF C0G across each AIN+/AIN− pair at ADC input pins |
| HIGH | U401, 37+ passives | — | Footprints missing on U401 (ADA4807-1) and 37+ other components | Complete footprint assignment for all components before layout |
| MODERATE | ADAU1979 | IOVDD (pin 12) bypass cap | Decoupling cap returns to AGND — should return to DGND | Reroute bypass cap return to DGND net |
| MODERATE | ADAU1979 | SA_MODE / ADDR0 / ADDR1 | Pins not confirmed driven — I2C address undefined; possible floating logic inputs | Tie SA_MODE/ADDR0/ADDR1 to defined levels; document resulting I2C address |
| MODERATE | R1214 | — | Non-sequential refdes — likely copy-paste from another sheet | Renumber R1214 to next available R4xx refdes in this sheet |
| MINOR | ADAU1979 | SDATAOUT2 (pin 14) | Not exported — TDM channel count unclear | Confirm whether TDM4 or TDM8 mode; export SDATAOUT2 if TDM8 is required |
| MINOR | ADAU1979 / ADAU1962A | MCLKIN / MCLK | Verify MCLKIN for ADC and MCLK for DAC are same domain and frequency | Cross-reference against clock tree output frequencies |

---

### 2.6 dacs.kicad_sch

| Priority | Ref | Net / Pin | Issue | Action |
|---|-----|---|---|---|
| CRITICAL | U601, U602 (ADAU1962A) | AVDD pins / "2.5V" | "2.5V" local label may connect to AVDD — ADAU1962A AVDD minimum is 3.0V | Trace "2.5V" net to all pins; confirm AVDD receives ≥3.0V supply; move 2.5V reference to correct pin |
| CRITICAL | C623, C624, C628 | Decoupling | Value = "0.iu" — typo for "0.1u" (100nF) | Correct all three to "100n" or "0.1u" |
| HIGH | — (majority of passives) | — | Majority of passive footprints missing | Assign all footprints before layout |
| MODERATE | R614 | IBIAS (3.32kΩ) | No tolerance annotation — 5% substitution would shift IBIAS by up to ±5% | Add "1%" tolerance annotation to R614 |
| MODERATE | Q601 (FZT951TA) | AVDD pass element | VBE drifts −2mV/°C — AVDD supply voltage will shift with temperature | Consider replacing Q601 with an LDO or adding feedback for stable AVDD |
| MODERATE | C629, C631, C635 | 10nF filter caps | Dielectric not specified — 10nF X7R will distort in signal path | Specify C0G/NP0 dielectric on all three |
| MINOR | ADAU1962A (U601, U602) | TDM slot assignments | DSP firmware must map DAC_P0+–DAC_P315± to correct TDM slots | Annotate TDM slot assignments on schematic; cross-reference to DSP firmware |

---

### 2.7 rx_mixer.kicad_sch

| Priority | Ref | Net / Pin | Issue | Action |
|---|-----|---|---|---|
| CRITICAL | All custom power symbols | −3.5V_RX_OPAMPS / +3.3V_RX_MIXER / +6.5V | Wrong lib_ids: power:+5V used for non-5V rails → −3.5V_RX_OPAMPS nets to global +5V in netlist | Replace every power symbol with correct dedicated symbol; regenerate netlist and verify |
| CRITICAL | SN74CBT3125C | +3.3V_RX_MIXER | 5V device on what is labelled as 3.3V rail — out of spec; sheet note says "Rx needs 5V" | If Rx mixer needs 5V, rename rail to +5V_RX_MIXER and supply 5V; update all connected nets |
| HIGH | HC_201–HC_208 | Hold caps / AIN+/AIN− | 100nF hold caps give BW≈12kHz with N=4 annotation; should be N=8 giving BW≈16kHz — annotation wrong and cap values may need adjustment | Correct N=8 in bandwidth annotation; recalculate hold cap value for target receive bandwidth; update cap values |
| MODERATE | ADA4625-2 | EP (pin 9) / V− | Exposed pad not confirmed connected to V− | Connect EP to V− (negative supply) as required by datasheet |
| MODERATE | 10µF caps | +6.5V rail | 0603 10µF — voltage rating is 6.3V; +6.5V exceeds rating | Replace with 16V-rated caps in 0805 or larger package |
| MINOR | "HC_" prefix | Capacitor refdes | Non-standard prefix — BOM tools may not parse correctly | Renumber to standard C_xxx refdes or confirm BOM tool handles custom prefixes |

---

### 2.8 tx_mixer.kicad_sch

| Priority | Ref | Net / Pin | Issue | Action |
|---|-----|---|---|---|
| HIGH | — | Post-mixer output | No reconstruction filter present despite sheet title "16 Phase Tx Harmonic Mixer and Reconstruction Filter" | Locate reconstruction filter in hierarchy or add filter components to this sheet before layout freeze |
| MODERATE | — | CLK_0/90/135 | Duplicate hierarchical label pins at identical coordinates — ERC may miss shorted labels | Clean up duplicate label placements; run ERC and confirm clean |
| MODERATE | — | phase_N (Rx) vs CLK_N (Tx) | Naming inconsistency for same clock tree outputs — confirm both refer to same physical signals | Standardise net naming across Rx and Tx sheets; annotate which clock tree output drives each |
| MODERATE | — | Tx DAC differential polarity | Differential polarity per arm not confirmed — incorrect polarity injects image/sideband | Verify LOUTP/LOUTN assignment per Tx arm; annotate polarity on schematic |
| MINOR | SN74CBTLV3125 | Symbol vs value | Value = CBTLV3125 on CBT3125C symbol — assembly will receive wrong device | Create dedicated symbol matching exact part; update BOM |
| MINOR | U801–U804 | Digikey part numbers | Empty — BOM incomplete | Add Digikey/Mouser part numbers for all four |

---

### 2.9 rx_driver_amps.kicad_sch

| Priority | Ref | Net / Pin | Issue | Action |
|---|-----|---|---|---|
| CRITICAL | All custom power symbols | −3.5V_RX_OPAMPS / +6V | All custom rails use power:+6V as base symbol → −3.5V_RX_OPAMPS shorts to global +6V | Fix all power symbol lib_ids; this is the same root cause as RX-1 — fix together |
| CRITICAL | ADG884 | VDD / "+6V" | ADG884 VDD connected to "+6V" due to DA-1 power symbol error — ADG884 abs max VDD=3.6V | After fixing power symbols, confirm ADG884 VDD connects to correct ≤3.3V rail |
| HIGH | C343, C322, C319, C320, C340, C341, C344 | ADA4945-1 feedback | All 180pF feedback caps DNP in Rev 0.0 — ADA4945-1 with 9.53kΩ Rf will likely oscillate | Either populate feedback caps (recommended) or redesign Rf to stable value without Cf; do not DNP on first prototype |
| HIGH | BB_0/180/90/270/45/225/135/315 | Px_IN+/− | Cross-sheet I/Q differential pairing not confirmed at top level — incorrect pairing destroys I/Q image rejection | Trace every BB_ net to its Px_IN± pin at top level; annotate mapping on nzif.kicad_sch |
| MODERATE | ADA4945-1 (all 4 instances) | Total supply / DISABLE | 10V total supply = rated limit; DISABLE pin disposition not confirmed | Verify supply rails sum to ≤10V under all conditions; confirm DISABLE tied to enable state |
| MODERATE | LT5400 | Resistor pairing / CMRR | Pin pair connectivity must be verified — misconnected pairs ruin CMRR | Verify LT5400 pin-out against KiCad symbol; confirm A1/B1 and A2/B2 pairing correct |
| MODERATE | ADA4945-1 feedback | 9.53kΩ Rf | Thermal noise ≈7.1nV/√Hz dominates amplifier noise floor | Evaluate reducing Rf to 2–4kΩ range; recalculate gain to compensate |

---

### 2.10 nzif.kicad_sch / dsp.kicad_sch / microcontroller.kicad_sch

| Priority | Ref | Net / Pin | Issue | Action |
|---|-----|---|---|---|
| HIGH | — | TX reconstruction filter | Absent from tx_mixer sheet — must be located or added to hierarchy | Confirm filter location in hierarchy; if missing, design and add before layout freeze |
| HIGH | HC_201–HC_208 | Rx hold caps | 100nF + N=8 + R=50Ω → BW≈16kHz — reconcile against target receive bandwidth | Determine target BW; adjust hold cap values; correct N annotation to 8 |
| MODERATE | SWIO_0–3 | — | Four SWIO signals leave Microcontroller sheet with no destination or description | Define SWIO destinations; add hierarchical labels or net ties; document purpose |
| MODERATE | Pico module | XIN | XIN hierarchical label — Pico uses internal crystal; label may create dangling net | Add explicit no-connect to XIN if unused; remove hierarchical label |
| MODERATE | Q501 | USB_RESET / SDP | Schematic note acknowledges Q501 USB_RESET circuit is incomplete | Complete Q501 circuit or remove and document alternative USB reset method before fabrication |
| MODERATE | CLK_0/90/135 labels | TX mixer | Duplicate hierarchical label pins at identical coordinates | Resolve duplicates; run ERC and confirm zero errors |
| MODERATE | MCP23017 | GPA7 / GPB7 | Errata: GPA7/GPB7 must be outputs only — confirm schematic and firmware enforce this | Verify no-connect or output-only assignment on GPA7/GPB7 in schematic; add firmware note |
| MINOR | SWIO_VLOGIC | — | Level-shifting reference for SWIO bus undocumented | Add net note defining SWIO_VLOGIC voltage and source |
| MINOR | ADAU1467 | DSP_CLK | Clock frequency not annotated — 12.288 or 24.576 MHz? | Add frequency annotation on DSP_CLK net; cross-reference to clock tree output |
| MINOR | ADAU1979 / ADAU1962A | TDM mode | TDM4 vs TDM8 mode for ADAU1979 not confirmed; two ADAU1962A TDM slot assignments not documented | Annotate TDM mode and slot assignments on schematic; verify against DSP firmware |

---

## 3. Prioritized Action List Before Layout Freeze

Actions are grouped by work stream. Items within each tier should be completed in the order listed, as later items may depend on earlier ones.

### Tier 1 — Block Layout: Must Fix First (week 1)

| # | Action | Owner | Sheets |
|---|---|---|---|
| 1 | **Fix all RF power symbol lib_ids** in rx_mixer and rx_driver_amps. Replace every power:+5V/+6V used for custom rails with correctly named dedicated symbols. Regenerate netlist and run ERC to confirm zero net cross-connections. | RF | rx_mixer, rx_driver_amps |
| 2 | **Correct all LT3045/LT3094 SET resistors**: Add "k" suffix to R903, R907, R908, R909 (49.9Ω → 49.9kΩ); recalculate which resistor value sets each rail; verify LT3094 R903 separately. | Power | power_ldos |
| 3 | **Recalculate all switching regulator feedback resistors**: R1101→4.23MΩ (LT8330 for −5V); R1103→400kΩ (ADP2303 for 4V); populate all six empty Value fields (R1108–R1113). | Power | power_switching_reg |
| 4 | **Fix OSC_CTRL load resistor**: Increase R701 from 1kΩ to ≥10kΩ to meet AD9523-1 20kΩ minimum load on pin 8. | Clock | clock_tree |
| 5 | **Resolve U706 part/value conflict**: Commit to SN74CBT3253 (5V) for Rx switches; update symbol lib_id, value, and BOM entry consistently. | Clock | clock_tree |
| 6 | **Fix ADAU1962A AVDD supply**: Trace "2.5V" label to all ADAU1962A pins; redirect AVDD to a ≥3.0V supply rail. | Precision | dacs |
| 7 | **Fix #PWR0406 in adcs.kicad_sch**: Replace power:+3.3V symbol with a dedicated +3.3V_CONVERTER power symbol to preserve rail isolation. | Precision | adcs |
| 8 | **Rename "DVDOUT" net label to "DVDDOUT"**: Run ERC to confirm CM and DVDDOUT nets are distinct. | Audio | audio_subsystem |

### Tier 2 — Fix Before PCB Stackup Decisions (week 2)

| # | Action | Owner | Sheets |
|---|---|---|---|
| 9 | **Confirm or add PLL1 loop filter cap** on AD9523-1 pin 7 (LF1_EXT_CAP); add per AD9523-1 datasheet if absent. | Clock | clock_tree |
| 10 | **Confirm X701 (CTS 535) EOH and Vc connections**: Drive EOH high to enable; connect Vc to OSC_CTRL net or document alternative. | Clock | clock_tree |
| 11 | **Populate LT3045/LT3094 output capacitors**: Replace all 4.7µF instances with ≥10µF ceramic (X5R/X7R, 0805, adequate voltage derating). | Power | power_ldos |
| 12 | **Correct R910 to 18.0kΩ** for +1.8V_CLOCKTREE; verify all other LT3045 SET resistor values against target output voltages. | Power | power_ldos |
| 13 | **Clarify C913/C917/C922 values** ("04.7u"): confirm intended value (470nF or 4.7µF); correct notation; verify SET pin bypass function. | Power | power_ldos |
| 14 | **Populate ADA4945-1 feedback caps** C343/C322/C319/C320/C340/C341/C344 (180pF): do not DNP on first prototype with 9.53kΩ Rf. | RF | rx_driver_amps |
| 15 | **Confirm or add Tx reconstruction filter** in hierarchy; if absent from tx_mixer.kicad_sch, design and place filter before layout. | RF/System | tx_mixer, nzif |
| 16 | **Correct SN74CBT3125C power rail**: If Rx mixer requires 5V, rename "+3.3V_RX_MIXER" to "+5V_RX_MIXER" and route 5V supply; update all connected power symbols. | RF | rx_mixer |
| 17 | **Add ADP2303 PGOOD pull-ups** (100kΩ) on U1102/U1103/U1104; define power sequencing and connect PGOOD to downstream LDO EN pins. | Power | power_switching_reg, power_ldos |

### Tier 3 — Complete Before Final ERC Sign-Off (week 3)

| # | Action | Owner | Sheets |
|---|---|---|---|
| 18 | **Assign all missing footprints**: U401 (ADA4807-1), X701 (CTS 535), U704/U707 (SN74LVC8T245), all 37+ passives in adcs, majority of passives in dacs, all C12xx/R12xx in audio. | All | all sheets |
| 19 | **Add anti-aliasing caps** (100–470pF C0G) across each AIN+/AIN− pair at ADAU1979 input. | Precision | adcs |
| 20 | **Confirm I/Q differential pairing** at top level: trace every BB_0/180/90/270/45/225/135/315 net to its Px_IN± destination; annotate mapping in nzif.kicad_sch. | RF/System | nzif, rx_driver_amps |
| 21 | **Add U1202 (SSM2211S) bulk bypass cap** (10–47µF) on 5V supply pin 6; add 1µF BYPASS cap C1212. | Audio | audio_subsystem |
| 22 | **Correct C623/C624/C628 typo** ("0.iu" → "100n") in dacs.kicad_sch. | Precision | dacs |
| 23 | **Verify AD9523-1 ZD_IN/ZD_IN_b** (pins 70/71) driven or terminated per datasheet zero-delay configuration. | Clock | clock_tree |
| 24 | **Tie ADA4807-1 DISABLE (pin 5)** to V+ to permanently enable; confirm for all instances. | Precision | adcs |
| 25 | **Connect ADA4625-2 EP (pin 9) to V−** in rx_mixer.kicad_sch. | RF | rx_mixer |
| 26 | **Replace 10µF 0603 caps on +6.5V rail** with 16V-rated 0805 parts in rx_mixer.kicad_sch. | RF | rx_mixer |
| 27 | **Complete Q501 USB_RESET circuit** or document replacement approach; remove incomplete schematic note. | uC | microcontroller |
| 28 | **Resolve SWIO_0–3 destinations**: add hierarchical labels, define SWIO_VLOGIC source voltage, and annotate purpose. | uC | microcontroller, nzif |
| 29 | **Add I2C pull-up resistors** (2kΩ to IOVDD) on SDA/SCL for ADAU1361 if not present in parent sheet; confirm pull-up at exactly one point in hierarchy. | Audio | audio_subsystem |
| 30 | **Add ferrite bead + 10µF cap** between ADP2303 8V output and LT3045 IN pins to restore LDO PSRR at 700kHz. | Power | power_ldos |
| 31 | **Add frequency plan annotation** to clock_tree.kicad_sch: reference frequency, PLL1/PLL2 VCO frequencies, all divider settings, output frequencies. | Clock | clock_tree |
| 32 | **Run full ERC** with zero errors/warnings as gate criterion for layout freeze; resolve all remaining ERC items not covered above. | All | all sheets |

---

**Sign-off criterion:** All Tier 1 actions verified closed, Tier 2 and Tier 3 actions tracked with assigned owners and target dates, before committing to PCB stackup and constraint setup.

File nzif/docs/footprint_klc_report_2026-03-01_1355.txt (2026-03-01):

Checking footprint 'ABLNO_ABR':
  Violating F5.1 - https://klc.kicad.org/footprint/f5/f5.1/
    Silkscreen layer requirements
    Some silkscreen lines have incorrect width: Allowed = [0.1, 0.12, 0.15] mm
  Violating F5.2 - https://klc.kicad.org/footprint/f5/f5.2/
    Fabrication layer requirements
    Some fabrication layer lines have a width outside allowed range of [0.1mm - 0.15mm]
  Violating F5.3 - https://klc.kicad.org/footprint/f5/f5.3/
    Courtyard layer requirements
    Courtyard width error (expected width = 0.05mm)
    Courtyard lines are not on 0.01mm grid
  Violating F9.1 - https://klc.kicad.org/footprint/f9/f9.1/
    Footprint meta-data is filled in as appropriate
    Description field is empty - add footprint description
  Violating F9.3 - https://klc.kicad.org/footprint/f9/f9.3/
    Footprint 3D model requirements
    Model path should start with '${KICAD8_3DMODEL_DIR}/'
    Model is incompatible format (must be WRL file)
Checking footprint 'CB-12-17_ADI':
  Violating F5.2 - https://klc.kicad.org/footprint/f5/f5.2/
    Fabrication layer requirements
    Some fabrication layer lines have a width outside allowed range of [0.1mm - 0.15mm]
  Violating F5.3 - https://klc.kicad.org/footprint/f5/f5.3/
    Courtyard layer requirements
    Courtyard width error (expected width = 0.05mm)
    Courtyard lines are not on 0.01mm grid
  Violating F9.1 - https://klc.kicad.org/footprint/f9/f9.1/
    Footprint meta-data is filled in as appropriate
    Description field is empty - add footprint description
  Violating F9.3 - https://klc.kicad.org/footprint/f9/f9.3/
    Footprint 3D model requirements
    Model path should start with '${KICAD8_3DMODEL_DIR}/'
    Model is incompatible format (must be WRL file)
Checking footprint 'CP-72-6_ADI':
  Violating EC01 - (extended check)
    Basic geometry checks
    Zero length lines
  Violating F5.1 - https://klc.kicad.org/footprint/f5/f5.1/
    Silkscreen layer requirements
    Some silkscreen lines have incorrect width: Allowed = [0.1, 0.12, 0.15] mm
  Violating F5.2 - https://klc.kicad.org/footprint/f5/f5.2/
    Fabrication layer requirements
    Some fabrication layer lines have a width outside allowed range of [0.1mm - 0.15mm]
  Violating F5.3 - https://klc.kicad.org/footprint/f5/f5.3/
    Courtyard layer requirements
    Courtyard width error (expected width = 0.05mm)
    Courtyard lines are not on 0.01mm grid
  Violating F5.4 - https://klc.kicad.org/footprint/f5/f5.4/
    Elements on the graphic layer should not overlap
    F.Fab graphic elements should not overlap.
  Violating F9.1 - https://klc.kicad.org/footprint/f9/f9.1/
    Footprint meta-data is filled in as appropriate
    Description field is empty - add footprint description
  Violating F9.3 - https://klc.kicad.org/footprint/f9/f9.3/
    Footprint 3D model requirements
    Model path should start with '${KICAD8_3DMODEL_DIR}/'
    Model is incompatible format (must be WRL file)
Checking footprint 'CP-72-7_ADI':
  Violating EC01 - (extended check)
    Basic geometry checks
    Zero length lines
  Violating F5.1 - https://klc.kicad.org/footprint/f5/f5.1/
    Silkscreen layer requirements
    Some silkscreen lines have incorrect width: Allowed = [0.1, 0.12, 0.15] mm
  Violating F5.2 - https://klc.kicad.org/footprint/f5/f5.2/
    Fabrication layer requirements
    Some fabrication layer lines have a width outside allowed range of [0.1mm - 0.15mm]
  Violating F5.3 - https://klc.kicad.org/footprint/f5/f5.3/
    Courtyard layer requirements
    Courtyard width error (expected width = 0.05mm)
    Courtyard lines are not on 0.01mm grid
  Violating F5.4 - https://klc.kicad.org/footprint/f5/f5.4/
    Elements on the graphic layer should not overlap
    F.Fab graphic elements should not overlap.
  Violating F9.1 - https://klc.kicad.org/footprint/f9/f9.1/
    Footprint meta-data is filled in as appropriate
    Description field is empty - add footprint description
  Violating F9.3 - https://klc.kicad.org/footprint/f9/f9.3/
    Footprint 3D model requirements
    Model path should start with '${KICAD8_3DMODEL_DIR}/'
    Model is incompatible format (must be WRL file)
Checking footprint 'CP_24_7_ADI':
  Violating F6.3 - https://klc.kicad.org/footprint/f6/f6.3/
    Pad requirements for SMD footprints
    Rectangular SMD pad
    Pad(s) potentially missing layers
  Violating F9.3 - https://klc.kicad.org/footprint/f9/f9.3/
    Footprint 3D model requirements
    Model path should start with '${KICAD8_3DMODEL_DIR}/'
    Model is incompatible format (must be WRL file)
Checking footprint 'CP_88_10_ADI':
  Violating EC01 - (extended check)
    Basic geometry checks
    Zero length lines
  Violating F5.1 - https://klc.kicad.org/footprint/f5/f5.1/
    Silkscreen layer requirements
    Some silkscreen lines have incorrect width: Allowed = [0.1, 0.12, 0.15] mm
  Violating F5.2 - https://klc.kicad.org/footprint/f5/f5.2/
    Fabrication layer requirements
    Some fabrication layer lines have a width outside allowed range of [0.1mm - 0.15mm]
  Violating F5.3 - https://klc.kicad.org/footprint/f5/f5.3/
    Courtyard layer requirements
    Courtyard width error (expected width = 0.05mm)
    Courtyard lines are not on 0.01mm grid
  Violating F5.4 - https://klc.kicad.org/footprint/f5/f5.4/
    Elements on the graphic layer should not overlap
    F.Fab graphic elements should not overlap.
  Violating F6.3 - https://klc.kicad.org/footprint/f6/f6.3/
    Pad requirements for SMD footprints
    Rectangular SMD pad
    Pad(s) potentially missing layers
  Violating F9.1 - https://klc.kicad.org/footprint/f9/f9.1/
    Footprint meta-data is filled in as appropriate
    Description field is empty - add footprint description
  Violating F9.3 - https://klc.kicad.org/footprint/f9/f9.3/
    Footprint 3D model requirements
    Model path should start with '${KICAD8_3DMODEL_DIR}/'
    Model is incompatible format (must be WRL file)
Checking footprint 'CTS_535_TCXO':
  Violating F5.1 - https://klc.kicad.org/footprint/f5/f5.1/
    Silkscreen layer requirements
    Reference label errors:
    Some silkscreen lines are not using the nominal width of 0.12 mm
    Some Silkscreen lines intersects with pads
  Violating F6.3 - https://klc.kicad.org/footprint/f6/f6.3/
    Pad requirements for SMD footprints
    Rectangular SMD pad
  Violating F9.1 - https://klc.kicad.org/footprint/f9/f9.1/
    Footprint meta-data is filled in as appropriate
    Description field does not contain a URL - add the URL to the datasheet
  Violating F9.3 - https://klc.kicad.org/footprint/f9/f9.3/
    Footprint 3D model requirements
    Model path should start with '${KICAD8_3DMODEL_DIR}/'
    Model is incompatible format (must be WRL file)
Checking footprint 'D16':
  Violating F5.1 - https://klc.kicad.org/footprint/f5/f5.1/
    Silkscreen layer requirements
    Some silkscreen lines have incorrect width: Allowed = [0.1, 0.12, 0.15] mm
  Violating F5.2 - https://klc.kicad.org/footprint/f5/f5.2/
    Fabrication layer requirements
    Some fabrication layer lines have a width outside allowed range of [0.1mm - 0.15mm]
  Violating F5.3 - https://klc.kicad.org/footprint/f5/f5.3/
    Courtyard layer requirements
    Courtyard width error (expected width = 0.05mm)
    Courtyard lines are not on 0.01mm grid
  Violating F5.4 - https://klc.kicad.org/footprint/f5/f5.4/
    Elements on the graphic layer should not overlap
    F.Fab graphic elements should not overlap.
  Violating F6.3 - https://klc.kicad.org/footprint/f6/f6.3/
    Pad requirements for SMD footprints
    Rectangular SMD pad
  Violating F9.1 - https://klc.kicad.org/footprint/f9/f9.1/
    Footprint meta-data is filled in as appropriate
    Description field is empty - add footprint description
  Violating F9.3 - https://klc.kicad.org/footprint/f9/f9.3/
    Footprint 3D model requirements
    Model path should start with '${KICAD8_3DMODEL_DIR}/'
    Model is incompatible format (must be WRL file)
Checking footprint 'DBV5':
  Violating F5.1 - https://klc.kicad.org/footprint/f5/f5.1/
    Silkscreen layer requirements
    Some Silkscreen lines intersects with pads
  Violating F9.1 - https://klc.kicad.org/footprint/f9/f9.1/
    Footprint meta-data is filled in as appropriate
    Description field does not contain a URL - add the URL to the datasheet
  Violating F9.3 - https://klc.kicad.org/footprint/f9/f9.3/
    Footprint 3D model requirements
    Model path should start with '${KICAD8_3DMODEL_DIR}/'
    Model is incompatible format (must be WRL file)
Checking footprint 'DCK5':
  Violating F5.1 - https://klc.kicad.org/footprint/f5/f5.1/
    Silkscreen layer requirements
    Some silkscreen lines have incorrect width: Allowed = [0.1, 0.12, 0.15] mm
  Violating F5.2 - https://klc.kicad.org/footprint/f5/f5.2/
    Fabrication layer requirements
    Some fabrication layer lines have a width outside allowed range of [0.1mm - 0.15mm]
  Violating F5.3 - https://klc.kicad.org/footprint/f5/f5.3/
    Courtyard layer requirements
    Courtyard width error (expected width = 0.05mm)
    Courtyard lines are not on 0.01mm grid
  Violating F5.4 - https://klc.kicad.org/footprint/f5/f5.4/
    Elements on the graphic layer should not overlap
    F.Fab graphic elements should not overlap.
  Violating F6.3 - https://klc.kicad.org/footprint/f6/f6.3/
    Pad requirements for SMD footprints
    Rectangular SMD pad
  Violating F9.1 - https://klc.kicad.org/footprint/f9/f9.1/
    Footprint meta-data is filled in as appropriate
    Description field is empty - add footprint description
  Violating F9.3 - https://klc.kicad.org/footprint/f9/f9.3/
    Footprint 3D model requirements
    3D model file path missing from the 3D model settings of the footprint
Checking footprint 'DD_05-08-1725_ADI':
  Violating F5.1 - https://klc.kicad.org/footprint/f5/f5.1/
    Silkscreen layer requirements
    Some silkscreen lines have incorrect width: Allowed = [0.1, 0.12, 0.15] mm
  Violating F5.2 - https://klc.kicad.org/footprint/f5/f5.2/
    Fabrication layer requirements
    Some fabrication layer lines have a width outside allowed range of [0.1mm - 0.15mm]
  Violating F5.3 - https://klc.kicad.org/footprint/f5/f5.3/
    Courtyard layer requirements
    Courtyard width error (expected width = 0.05mm)
    Courtyard lines are not on 0.01mm grid
  Violating F6.3 - https://klc.kicad.org/footprint/f6/f6.3/
    Pad requirements for SMD footprints
    Rectangular SMD pad
  Violating F9.1 - https://klc.kicad.org/footprint/f9/f9.1/
    Footprint meta-data is filled in as appropriate
    Description field is empty - add footprint description
    The 'description' field should not be set for a footprint: (have 'DFN-12, 3.0x3.0mm, 0.45mm pitch, thermal pad')
  Violating F9.3 - https://klc.kicad.org/footprint/f9/f9.3/
    Footprint 3D model requirements
    Model path should start with '${KICAD8_3DMODEL_DIR}/'
    Model is incompatible format (must be WRL file)
Checking footprint 'DFN-S8_6x5MC_MCH':
  Violating F5.1 - https://klc.kicad.org/footprint/f5/f5.1/
    Silkscreen layer requirements
    Some silkscreen lines have incorrect width: Allowed = [0.1, 0.12, 0.15] mm
  Violating F5.2 - https://klc.kicad.org/footprint/f5/f5.2/
    Fabrication layer requirements
    Some fabrication layer lines have a width outside allowed range of [0.1mm - 0.15mm]
  Violating F5.3 - https://klc.kicad.org/footprint/f5/f5.3/
    Courtyard layer requirements
    Courtyard width error (expected width = 0.05mm)
    Courtyard lines are not on 0.01mm grid
  Violating F6.3 - https://klc.kicad.org/footprint/f6/f6.3/
    Pad requirements for SMD footprints
    Rectangular SMD pad
  Violating F9.1 - https://klc.kicad.org/footprint/f9/f9.1/
    Footprint meta-data is filled in as appropriate
    Description field is empty - add footprint description
  Violating F9.3 - https://klc.kicad.org/footprint/f9/f9.3/
    Footprint 3D model requirements
    Model path should start with '${KICAD8_3DMODEL_DIR}/'
    Model is incompatible format (must be WRL file)
Checking footprint 'DGG48':
  Violating F5.1 - https://klc.kicad.org/footprint/f5/f5.1/
    Silkscreen layer requirements
    Some silkscreen lines have incorrect width: Allowed = [0.1, 0.12, 0.15] mm
  Violating F5.2 - https://klc.kicad.org/footprint/f5/f5.2/
    Fabrication layer requirements
    Some fabrication layer lines have a width outside allowed range of [0.1mm - 0.15mm]
  Violating F5.3 - https://klc.kicad.org/footprint/f5/f5.3/
    Courtyard layer requirements
    Courtyard width error (expected width = 0.05mm)
    Courtyard lines are not on 0.01mm grid
  Violating F5.4 - https://klc.kicad.org/footprint/f5/f5.4/
    Elements on the graphic layer should not overlap
    F.Fab graphic elements should not overlap.
  Violating F6.3 - https://klc.kicad.org/footprint/f6/f6.3/
    Pad requirements for SMD footprints
    Rectangular SMD pad
  Violating F9.1 - https://klc.kicad.org/footprint/f9/f9.1/
    Footprint meta-data is filled in as appropriate
    Description field is empty - add footprint description
  Violating F9.3 - https://klc.kicad.org/footprint/f9/f9.3/
    Footprint 3D model requirements
    Model path should start with '${KICAD8_3DMODEL_DIR}/'
    Model is incompatible format (must be WRL file)
Checking footprint 'DPAKTO-252_TYPEA_STM':
  Violating F5.1 - https://klc.kicad.org/footprint/f5/f5.1/
    Silkscreen layer requirements
    Some silkscreen lines have incorrect width: Allowed = [0.1, 0.12, 0.15] mm
  Violating F5.2 - https://klc.kicad.org/footprint/f5/f5.2/
    Fabrication layer requirements
    Some fabrication layer lines have a width outside allowed range of [0.1mm - 0.15mm]
  Violating F5.3 - https://klc.kicad.org/footprint/f5/f5.3/
    Courtyard layer requirements
    Courtyard width error (expected width = 0.05mm)
    Courtyard lines are not on 0.01mm grid
  Violating F5.4 - https://klc.kicad.org/footprint/f5/f5.4/
    Elements on the graphic layer should not overlap
    F.Fab graphic elements should not overlap.
  Violating F6.2 - https://klc.kicad.org/footprint/f6/f6.2/
    For surface-mount devices, footprint anchor is placed in the middle of the footprint
    Footprint anchor does not match calculated center of Pads or F.Fab
  Violating F6.3 - https://klc.kicad.org/footprint/f6/f6.3/
    Pad requirements for SMD footprints
    Rectangular SMD pad
  Violating F9.1 - https://klc.kicad.org/footprint/f9/f9.1/
    Footprint meta-data is filled in as appropriate
    Description field is empty - add footprint description
  Violating F9.3 - https://klc.kicad.org/footprint/f9/f9.3/
    Footprint 3D model requirements
    Model path should start with '${KICAD8_3DMODEL_DIR}/'
    Model is incompatible format (must be WRL file)
Checking footprint 'EPC2019_ECC':
  Violating F5.1 - https://klc.kicad.org/footprint/f5/f5.1/
    Silkscreen layer requirements
    Some silkscreen lines have incorrect width: Allowed = [0.1, 0.12, 0.15] mm
  Violating F5.2 - https://klc.kicad.org/footprint/f5/f5.2/
    Fabrication layer requirements
    Some fabrication layer lines have a width outside allowed range of [0.1mm - 0.15mm]
  Violating F5.3 - https://klc.kicad.org/footprint/f5/f5.3/
    Courtyard layer requirements
    Courtyard width error (expected width = 0.05mm)
    Courtyard lines are not on 0.01mm grid
  Violating F9.1 - https://klc.kicad.org/footprint/f9/f9.1/
    Footprint meta-data is filled in as appropriate
    Description field is empty - add footprint description
  Violating F9.3 - https://klc.kicad.org/footprint/f9/f9.3/
    Footprint 3D model requirements
    3D model file path missing from the 3D model settings of the footprint
Checking footprint 'KS_6_ADI':
  Violating F5.1 - https://klc.kicad.org/footprint/f5/f5.1/
    Silkscreen layer requirements
    Some silkscreen lines have incorrect width: Allowed = [0.1, 0.12, 0.15] mm
  Violating F5.2 - https://klc.kicad.org/footprint/f5/f5.2/
    Fabrication layer requirements
    Some fabrication layer lines have a width outside allowed range of [0.1mm - 0.15mm]
  Violating F5.3 - https://klc.kicad.org/footprint/f5/f5.3/
    Courtyard layer requirements
    Courtyard width error (expected width = 0.05mm)
    Courtyard lines are not on 0.01mm grid
  Violating F5.4 - https://klc.kicad.org/footprint/f5/f5.4/
    Elements on the graphic layer should not overlap
    F.Fab graphic elements should not overlap.
  Violating F6.3 - https://klc.kicad.org/footprint/f6/f6.3/
    Pad requirements for SMD footprints
    Rectangular SMD pad
  Violating F9.1 - https://klc.kicad.org/footprint/f9/f9.1/
    Footprint meta-data is filled in as appropriate
    Description field is empty - add footprint description
  Violating F9.3 - https://klc.kicad.org/footprint/f9/f9.3/
    Footprint 3D model requirements
    Model path should start with '${KICAD8_3DMODEL_DIR}/'
    Model is incompatible format (must be WRL file)
Checking footprint 'LFCSP16_ADA4945-1ACPZ-R2_ADI':
  Violating EC01 - (extended check)
    Basic geometry checks
    Zero length lines
  Violating F5.1 - https://klc.kicad.org/footprint/f5/f5.1/
    Silkscreen layer requirements
    Some silkscreen lines have incorrect width: Allowed = [0.1, 0.12, 0.15] mm
  Violating F5.2 - https://klc.kicad.org/footprint/f5/f5.2/
    Fabrication layer requirements
    Some fabrication layer lines have a width outside allowed range of [0.1mm - 0.15mm]
  Violating F5.3 - https://klc.kicad.org/footprint/f5/f5.3/
    Courtyard layer requirements
    Courtyard width error (expected width = 0.05mm)
    Courtyard lines are not on 0.01mm grid
  Violating F5.4 - https://klc.kicad.org/footprint/f5/f5.4/
    Elements on the graphic layer should not overlap
    F.Fab graphic elements should not overlap.
  Violating F9.1 - https://klc.kicad.org/footprint/f9/f9.1/
    Footprint meta-data is filled in as appropriate
    Description field is empty - add footprint description
  Violating F9.3 - https://klc.kicad.org/footprint/f9/f9.3/
    Footprint 3D model requirements
    Model path should start with '${KICAD8_3DMODEL_DIR}/'
    Model is incompatible format (must be WRL file)
Checking footprint 'MSOP-8_MS_LIT':
  Violating F5.1 - https://klc.kicad.org/footprint/f5/f5.1/
    Silkscreen layer requirements
    Some silkscreen lines have incorrect width: Allowed = [0.1, 0.12, 0.15] mm
  Violating F5.2 - https://klc.kicad.org/footprint/f5/f5.2/
    Fabrication layer requirements
    Some fabrication layer lines have a width outside allowed range of [0.1mm - 0.15mm]
  Violating F5.3 - https://klc.kicad.org/footprint/f5/f5.3/
    Courtyard layer requirements
    Courtyard width error (expected width = 0.05mm)
    Courtyard lines are not on 0.01mm grid
  Violating F5.4 - https://klc.kicad.org/footprint/f5/f5.4/
    Elements on the graphic layer should not overlap
    F.Fab graphic elements should not overlap.
  Violating F9.1 - https://klc.kicad.org/footprint/f9/f9.1/
    Footprint meta-data is filled in as appropriate
    Description field is empty - add footprint description
    The 'description' field should not be set for a footprint: (have 'MSOP-8, 3.0x3.0mm, 0.65mm pitch')
  Violating F9.3 - https://klc.kicad.org/footprint/f9/f9.3/
    Footprint 3D model requirements
    Model path should start with '${KICAD8_3DMODEL_DIR}/'
    Model is incompatible format (must be WRL file)
Checking footprint 'PW0016A_L':
  Violating F5.1 - https://klc.kicad.org/footprint/f5/f5.1/
    Silkscreen layer requirements
    Some silkscreen lines have incorrect width: Allowed = [0.1, 0.12, 0.15] mm
  Violating F5.2 - https://klc.kicad.org/footprint/f5/f5.2/
    Fabrication layer requirements
    Some fabrication layer lines are not using the nominal width of 0.1 mm
  Violating F5.3 - https://klc.kicad.org/footprint/f5/f5.3/
    Courtyard layer requirements
    Courtyard width error (expected width = 0.05mm)
    Courtyard lines are not on 0.01mm grid
    Courtyard must be closed.
  Violating F5.4 - https://klc.kicad.org/footprint/f5/f5.4/
    Elements on the graphic layer should not overlap
    F.Fab graphic elements should not overlap.
  Violating F9.1 - https://klc.kicad.org/footprint/f9/f9.1/
    Footprint meta-data is filled in as appropriate
    Description field is empty - add footprint description
    The 'description' field should not be set for a footprint: (have 'TSSOP-16, 4.4x5mm, 0.65mm pitch')
  Violating F9.3 - https://klc.kicad.org/footprint/f9/f9.3/
    Footprint 3D model requirements
    Model path should start with '${KICAD8_3DMODEL_DIR}/'
    Model is incompatible format (must be WRL file)
Checking footprint 'PW14':
  Violating F5.1 - https://klc.kicad.org/footprint/f5/f5.1/
    Silkscreen layer requirements
    Some silkscreen lines have incorrect width: Allowed = [0.1, 0.12, 0.15] mm
  Violating F5.2 - https://klc.kicad.org/footprint/f5/f5.2/
    Fabrication layer requirements
    Some fabrication layer lines have a width outside allowed range of [0.1mm - 0.15mm]
  Violating F5.3 - https://klc.kicad.org/footprint/f5/f5.3/
    Courtyard layer requirements
    Courtyard width error (expected width = 0.05mm)
    Courtyard lines are not on 0.01mm grid
  Violating F5.4 - https://klc.kicad.org/footprint/f5/f5.4/
    Elements on the graphic layer should not overlap
    F.Fab graphic elements should not overlap.
  Violating F9.1 - https://klc.kicad.org/footprint/f9/f9.1/
    Footprint meta-data is filled in as appropriate
    Description field is empty - add footprint description
    The 'description' field should not be set for a footprint: (have 'TSSOP-14, 4.4x5.0mm, 0.65mm pitch')
  Violating F9.3 - https://klc.kicad.org/footprint/f9/f9.3/
    Footprint 3D model requirements
    Model path should start with '${KICAD8_3DMODEL_DIR}/'
    Model is incompatible format (must be WRL file)
Checking footprint 'QFN20_4X4_PSM':
  Violating EC01 - (extended check)
    Basic geometry checks
    Zero length lines
  Violating F5.1 - https://klc.kicad.org/footprint/f5/f5.1/
    Silkscreen layer requirements
    Some silkscreen lines have incorrect width: Allowed = [0.1, 0.12, 0.15] mm
  Violating F5.2 - https://klc.kicad.org/footprint/f5/f5.2/
    Fabrication layer requirements
    Some fabrication layer lines have a width outside allowed range of [0.1mm - 0.15mm]
  Violating F5.3 - https://klc.kicad.org/footprint/f5/f5.3/
    Courtyard layer requirements
    Courtyard width error (expected width = 0.05mm)
    Courtyard lines are not on 0.01mm grid
  Violating F5.4 - https://klc.kicad.org/footprint/f5/f5.4/
    Elements on the graphic layer should not overlap
    F.Fab graphic elements should not overlap.
  Violating F6.3 - https://klc.kicad.org/footprint/f6/f6.3/
    Pad requirements for SMD footprints
    Rectangular SMD pad
  Violating F9.1 - https://klc.kicad.org/footprint/f9/f9.1/
    Footprint meta-data is filled in as appropriate
    Description field is empty - add footprint description
  Violating F9.3 - https://klc.kicad.org/footprint/f9/f9.3/
    Footprint 3D model requirements
    Model path should start with '${KICAD8_3DMODEL_DIR}/'
    Model is incompatible format (must be WRL file)
Checking footprint 'R-8_ADI':
  Violating F5.1 - https://klc.kicad.org/footprint/f5/f5.1/
    Silkscreen layer requirements
    Some silkscreen lines have incorrect width: Allowed = [0.1, 0.12, 0.15] mm
  Violating F5.2 - https://klc.kicad.org/footprint/f5/f5.2/
    Fabrication layer requirements
    Some fabrication layer lines have a width outside allowed range of [0.1mm - 0.15mm]
  Violating F5.3 - https://klc.kicad.org/footprint/f5/f5.3/
    Courtyard layer requirements
    Courtyard width error (expected width = 0.05mm)
    Courtyard lines are not on 0.01mm grid
  Violating F5.4 - https://klc.kicad.org/footprint/f5/f5.4/
    Elements on the graphic layer should not overlap
    F.Fab graphic elements should not overlap.
  Violating F6.3 - https://klc.kicad.org/footprint/f6/f6.3/
    Pad requirements for SMD footprints
    Rectangular SMD pad
  Violating F9.1 - https://klc.kicad.org/footprint/f9/f9.1/
    Footprint meta-data is filled in as appropriate
    Description field is empty - add footprint description
  Violating F9.3 - https://klc.kicad.org/footprint/f9/f9.3/
    Footprint 3D model requirements
    Model path should start with '${KICAD8_3DMODEL_DIR}/'
    Model is incompatible format (must be WRL file)
Checking footprint 'RA_4_ADI':
  Violating F5.1 - https://klc.kicad.org/footprint/f5/f5.1/
    Silkscreen layer requirements
    Some silkscreen lines have incorrect width: Allowed = [0.1, 0.12, 0.15] mm
  Violating F5.2 - https://klc.kicad.org/footprint/f5/f5.2/
    Fabrication layer requirements
    Some fabrication layer lines have a width outside allowed range of [0.1mm - 0.15mm]
  Violating F5.3 - https://klc.kicad.org/footprint/f5/f5.3/
    Courtyard layer requirements
    Courtyard width error (expected width = 0.05mm)
    Courtyard lines are not on 0.01mm grid
  Violating F5.4 - https://klc.kicad.org/footprint/f5/f5.4/
    Elements on the graphic layer should not overlap
    F.Fab graphic elements should not overlap.
  Violating F6.3 - https://klc.kicad.org/footprint/f6/f6.3/
    Pad requirements for SMD footprints
    Rectangular SMD pad
  Violating F9.1 - https://klc.kicad.org/footprint/f9/f9.1/
    Footprint meta-data is filled in as appropriate
    Description field is empty - add footprint description
  Violating F9.3 - https://klc.kicad.org/footprint/f9/f9.3/
    Footprint 3D model requirements
    Model path should start with '${KICAD8_3DMODEL_DIR}/'
    Model is incompatible format (must be WRL file)
Checking footprint 'RD_8_1_ADI':
  Violating F5.1 - https://klc.kicad.org/footprint/f5/f5.1/
    Silkscreen layer requirements
    Some silkscreen lines have incorrect width: Allowed = [0.1, 0.12, 0.15] mm
  Violating F5.2 - https://klc.kicad.org/footprint/f5/f5.2/
    Fabrication layer requirements
    Some fabrication layer lines have a width outside allowed range of [0.1mm - 0.15mm]
  Violating F5.3 - https://klc.kicad.org/footprint/f5/f5.3/
    Courtyard layer requirements
    Courtyard width error (expected width = 0.05mm)
    Courtyard lines are not on 0.01mm grid
  Violating F5.4 - https://klc.kicad.org/footprint/f5/f5.4/
    Elements on the graphic layer should not overlap
    F.Fab graphic elements should not overlap.
  Violating F6.3 - https://klc.kicad.org/footprint/f6/f6.3/
    Pad requirements for SMD footprints
    Rectangular SMD pad
  Violating F9.1 - https://klc.kicad.org/footprint/f9/f9.1/
    Footprint meta-data is filled in as appropriate
    Description field is empty - add footprint description
  Violating F9.3 - https://klc.kicad.org/footprint/f9/f9.3/
    Footprint 3D model requirements
    Model path should start with '${KICAD8_3DMODEL_DIR}/'
    Model is incompatible format (must be WRL file)
Checking footprint 'RJ_5_ADI':
  Violating F5.1 - https://klc.kicad.org/footprint/f5/f5.1/
    Silkscreen layer requirements
    Some silkscreen lines have incorrect width: Allowed = [0.1, 0.12, 0.15] mm
  Violating F5.2 - https://klc.kicad.org/footprint/f5/f5.2/
    Fabrication layer requirements
    Some fabrication layer lines have a width outside allowed range of [0.1mm - 0.15mm]
  Violating F5.3 - https://klc.kicad.org/footprint/f5/f5.3/
    Courtyard layer requirements
    Courtyard width error (expected width = 0.05mm)
    Courtyard lines are not on 0.01mm grid
  Violating F5.4 - https://klc.kicad.org/footprint/f5/f5.4/
    Elements on the graphic layer should not overlap
    F.Fab graphic elements should not overlap.
  Violating F6.3 - https://klc.kicad.org/footprint/f6/f6.3/
    Pad requirements for SMD footprints
    Rectangular SMD pad
  Violating F9.1 - https://klc.kicad.org/footprint/f9/f9.1/
    Footprint meta-data is filled in as appropriate
    Description field is empty - add footprint description
  Violating F9.3 - https://klc.kicad.org/footprint/f9/f9.3/
    Footprint 3D model requirements
    Model path should start with '${KICAD8_3DMODEL_DIR}/'
    Model is incompatible format (must be WRL file)
Checking footprint 'RM_8_ADI':
  Violating F6.3 - https://klc.kicad.org/footprint/f6/f6.3/
    Pad requirements for SMD footprints
    Rectangular SMD pad
  Violating F9.3 - https://klc.kicad.org/footprint/f9/f9.3/
    Footprint 3D model requirements
    3D model file path missing from the 3D model settings of the footprint
Checking footprint 'R_8_ADI':
  Violating F5.1 - https://klc.kicad.org/footprint/f5/f5.1/
    Silkscreen layer requirements
    Some silkscreen lines have incorrect width: Allowed = [0.1, 0.12, 0.15] mm
  Violating F5.2 - https://klc.kicad.org/footprint/f5/f5.2/
    Fabrication layer requirements
    Some fabrication layer lines have a width outside allowed range of [0.1mm - 0.15mm]
  Violating F5.3 - https://klc.kicad.org/footprint/f5/f5.3/
    Courtyard layer requirements
    Courtyard width error (expected width = 0.05mm)
    Courtyard lines are not on 0.01mm grid
  Violating F5.4 - https://klc.kicad.org/footprint/f5/f5.4/
    Elements on the graphic layer should not overlap
    F.Fab graphic elements should not overlap.
  Violating F6.3 - https://klc.kicad.org/footprint/f6/f6.3/
    Pad requirements for SMD footprints
    Rectangular SMD pad
  Violating F9.1 - https://klc.kicad.org/footprint/f9/f9.1/
    Footprint meta-data is filled in as appropriate
    Description field is empty - add footprint description
  Violating F9.3 - https://klc.kicad.org/footprint/f9/f9.3/
    Footprint 3D model requirements
    Model path should start with '${KICAD8_3DMODEL_DIR}/'
    Model is incompatible format (must be WRL file)
Checking footprint 'SOIC-16_ONS':
  Violating F5.1 - https://klc.kicad.org/footprint/f5/f5.1/
    Silkscreen layer requirements
    Some silkscreen lines have incorrect width: Allowed = [0.1, 0.12, 0.15] mm
  Violating F5.2 - https://klc.kicad.org/footprint/f5/f5.2/
    Fabrication layer requirements
    Some fabrication layer lines have a width outside allowed range of [0.1mm - 0.15mm]
  Violating F5.3 - https://klc.kicad.org/footprint/f5/f5.3/
    Courtyard layer requirements
    Courtyard width error (expected width = 0.05mm)
    Courtyard lines are not on 0.01mm grid
  Violating F5.4 - https://klc.kicad.org/footprint/f5/f5.4/
    Elements on the graphic layer should not overlap
    F.Fab graphic elements should not overlap.
  Violating F6.3 - https://klc.kicad.org/footprint/f6/f6.3/
    Pad requirements for SMD footprints
    Rectangular SMD pad
  Violating F9.1 - https://klc.kicad.org/footprint/f9/f9.1/
    Footprint meta-data is filled in as appropriate
    Description field is empty - add footprint description
  Violating F9.3 - https://klc.kicad.org/footprint/f9/f9.3/
    Footprint 3D model requirements
    Model path should start with '${KICAD8_3DMODEL_DIR}/'
    Model is incompatible format (must be WRL file)
Checking footprint 'SOT-23_S6_LIT':
  Violating F5.1 - https://klc.kicad.org/footprint/f5/f5.1/
    Silkscreen layer requirements
    Some silkscreen lines have incorrect width: Allowed = [0.1, 0.12, 0.15] mm
  Violating F5.2 - https://klc.kicad.org/footprint/f5/f5.2/
    Fabrication layer requirements
    Some fabrication layer lines have a width outside allowed range of [0.1mm - 0.15mm]
  Violating F5.3 - https://klc.kicad.org/footprint/f5/f5.3/
    Courtyard layer requirements
    Courtyard width error (expected width = 0.05mm)
    Courtyard lines are not on 0.01mm grid
  Violating F5.4 - https://klc.kicad.org/footprint/f5/f5.4/
    Elements on the graphic layer should not overlap
    F.Fab graphic elements should not overlap.
  Violating F9.1 - https://klc.kicad.org/footprint/f9/f9.1/
    Footprint meta-data is filled in as appropriate
    Description field is empty - add footprint description
    The 'description' field should not be set for a footprint: (have 'SOT-23-6, 2.9x1.6mm, 0.95mm pitch')
  Violating F9.3 - https://klc.kicad.org/footprint/f9/f9.3/
    Footprint 3D model requirements
    Model path should start with '${KICAD8_3DMODEL_DIR}/'
    Model is incompatible format (must be WRL file)
Checking footprint 'SOT223-FZT690B-DN_DIO':
  Violating F5.1 - https://klc.kicad.org/footprint/f5/f5.1/
    Silkscreen layer requirements
    Some silkscreen lines have incorrect width: Allowed = [0.1, 0.12, 0.15] mm
  Violating F5.2 - https://klc.kicad.org/footprint/f5/f5.2/
    Fabrication layer requirements
    Some fabrication layer lines have a width outside allowed range of [0.1mm - 0.15mm]
  Violating F5.3 - https://klc.kicad.org/footprint/f5/f5.3/
    Courtyard layer requirements
    Courtyard width error (expected width = 0.05mm)
    Courtyard lines are not on 0.01mm grid
  Violating F5.4 - https://klc.kicad.org/footprint/f5/f5.4/
    Elements on the graphic layer should not overlap
    F.Fab graphic elements should not overlap.
  Violating F9.1 - https://klc.kicad.org/footprint/f9/f9.1/
    Footprint meta-data is filled in as appropriate
    Description field is empty - add footprint description
  Violating F9.3 - https://klc.kicad.org/footprint/f9/f9.3/
    Footprint 3D model requirements
    Model path should start with '${KICAD8_3DMODEL_DIR}/'
    Model is incompatible format (must be WRL file)
Checking footprint 'ST_80_2_ADI':
  Violating EC01 - (extended check)
    Basic geometry checks
    Zero length lines
  Violating F5.1 - https://klc.kicad.org/footprint/f5/f5.1/
    Silkscreen layer requirements
    Some silkscreen lines have incorrect width: Allowed = [0.1, 0.12, 0.15] mm
  Violating F5.2 - https://klc.kicad.org/footprint/f5/f5.2/
    Fabrication layer requirements
    Some fabrication layer lines have a width outside allowed range of [0.1mm - 0.15mm]
  Violating F5.3 - https://klc.kicad.org/footprint/f5/f5.3/
    Courtyard layer requirements
    Courtyard lines are not on 0.01mm grid
  Violating F5.4 - https://klc.kicad.org/footprint/f5/f5.4/
    Elements on the graphic layer should not overlap
    F.Fab graphic elements should not overlap.
  Violating F9.1 - https://klc.kicad.org/footprint/f9/f9.1/
    Footprint meta-data is filled in as appropriate
    Description field is empty - add footprint description
    The 'description' field should not be set for a footprint: (have '80-pin TQFP package, 14x14mm body, 0.65mm pitch, ST-80-2')
  Violating F9.3 - https://klc.kicad.org/footprint/f9/f9.3/
    Footprint 3D model requirements
    Model path should start with '${KICAD8_3DMODEL_DIR}/'
    Model is incompatible format (must be WRL file)
Checking footprint 'YFF0006AEAE':
  Violating F5.2 - https://klc.kicad.org/footprint/f5/f5.2/
    Fabrication layer requirements
    Some fabrication layer lines have a width outside allowed range of [0.1mm - 0.15mm]
  Violating F5.3 - https://klc.kicad.org/footprint/f5/f5.3/
    Courtyard layer requirements
    No courtyard found!
  Violating F6.1 - https://klc.kicad.org/footprint/f6/f6.1/
    For surface-mount devices, placement type must be set to "Surface Mount"
    SMD footprint type is set, but no soldered SMD pads found
  Violating F6.3 - https://klc.kicad.org/footprint/f6/f6.3/
    Pad requirements for SMD footprints
    Pad(s) potentially missing layers
  Violating F9.1 - https://klc.kicad.org/footprint/f9/f9.1/
    Footprint meta-data is filled in as appropriate
    Description field is empty - add footprint description
  Violating F9.3 - https://klc.kicad.org/footprint/f9/f9.3/
    Footprint 3D model requirements
    3D model file path missing from the 3D model settings of the footprint

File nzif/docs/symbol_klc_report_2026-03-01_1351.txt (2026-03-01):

Checking symbol 'nzif_radio_symbol_library:74CBT1G125DBVRE4':
  Violating S3.6 - https://klc.kicad.org/symbol/s3/s3.6/
    Pin name position offset
    Pin offset outside allowed range
  Violating S5.1 - https://klc.kicad.org/symbol/s5/s5.1/
    Symbols with a default footprint link to a valid footprint file
    Footprint filter 'DBV5-M' does not match the footprint 'nzif_footprints:DBV5' set for this symbol.
    Footprint filter 'DBV5-L' does not match the footprint 'nzif_footprints:DBV5' set for this symbol.
    Symbol has a footprint defined in the footprint field, but several (3) footprint filters set. If the symbol is for a single default footprint, remove the surplus filters. If the symbol is meant for multiple different footprints, empty the footprint field.
  Violating S5.2 - https://klc.kicad.org/symbol/s5/s5.2/
    Footprint filters should match all appropriate footprints
    Footprint filter 'DBV5' not correctly formatted
    Footprint filter 'DBV5-M' not correctly formatted
    Minuses and underscores in footprint filter 'DBV5-M' should be escaped with '?' or '*'.
    Footprint filter 'DBV5-L' not correctly formatted
    Minuses and underscores in footprint filter 'DBV5-L' should be escaped with '?' or '*'.
Checking symbol 'nzif_radio_symbol_library:ABLNO-V-VCXO':
  Violating S3.2 - https://klc.kicad.org/symbol/s3/s3.2/
    Text fields should use a common text size of 50mils
     - Field Reference at posx 0 posy 0 size 60
     - Field Value at posx -100 posy 0 size 60
  Violating S3.3 - https://klc.kicad.org/symbol/s3/s3.3/
    Symbol outline and fill requirements
    Component outline is thickness 0mil, recommended is 10mil for standard symbol
  Violating S3.6 - https://klc.kicad.org/symbol/s3/s3.6/
    Pin name position offset
    Pin offset outside allowed range
  Violating S4.2 - https://klc.kicad.org/symbol/s4/s4.2/
    Pins should be grouped by function
    For a power converter symbol, positive power pins should be placed at left of symbol
    Power output pins should be placed at right of symbol
  Violating S4.4 - https://klc.kicad.org/symbol/s4/s4.4/
    Pin electrical type should match pin function
    Power pins should be of type POWER INPUT
  Violating S5.1 - https://klc.kicad.org/symbol/s5/s5.1/
    Symbols with a default footprint link to a valid footprint file
    Footprint filter 'ABLNO_ABR-M' does not match the footprint 'nzif_footprints:ABLNO_ABR' set for this symbol.
    Footprint filter 'ABLNO_ABR-L' does not match the footprint 'nzif_footprints:ABLNO_ABR' set for this symbol.
    Symbol has a footprint defined in the footprint field, but several (3) footprint filters set. If the symbol is for a single default footprint, remove the surplus filters. If the symbol is meant for multiple different footprints, empty the footprint field.
  Violating S5.2 - https://klc.kicad.org/symbol/s5/s5.2/
    Footprint filters should match all appropriate footprints
    Footprint filter 'ABLNO_ABR' not correctly formatted
    Minuses and underscores in footprint filter 'ABLNO_ABR' should be escaped with '?' or '*'.
    Footprint filter 'ABLNO_ABR-M' not correctly formatted
    Minuses and underscores in footprint filter 'ABLNO_ABR-M' should be escaped with '?' or '*'.
    Footprint filter 'ABLNO_ABR-L' not correctly formatted
    Minuses and underscores in footprint filter 'ABLNO_ABR-L' should be escaped with '?' or '*'.
  Violating S6.2 - https://klc.kicad.org/symbol/s6/s6.2/
    Symbol fields and metadata filled out as required
    Value ABLNO-VCXO does not match component name.
Checking symbol 'nzif_radio_symbol_library:AD8397ARZ':
  Violating S3.2 - https://klc.kicad.org/symbol/s3/s3.2/
    Text fields should use a common text size of 50mils
     - Field Reference at posx 0 posy 700 size 60
     - Field Value at posx 0 posy 600 size 60
  Violating S3.3 - https://klc.kicad.org/symbol/s3/s3.3/
    Symbol outline and fill requirements
    Component outline is thickness 0mil, recommended is 10mil
  Violating S3.6 - https://klc.kicad.org/symbol/s3/s3.6/
    Pin name position offset
    Pin offset outside allowed range
  Violating S5.1 - https://klc.kicad.org/symbol/s5/s5.1/
    Symbols with a default footprint link to a valid footprint file
    Footprint filter 'R_8_ADI-M' does not match the footprint 'nzif_footprints:R_8_ADI' set for this symbol.
    Footprint filter 'R_8_ADI-L' does not match the footprint 'nzif_footprints:R_8_ADI' set for this symbol.
    Symbol has a footprint defined in the footprint field, but several (3) footprint filters set. If the symbol is for a single default footprint, remove the surplus filters. If the symbol is meant for multiple different footprints, empty the footprint field.
  Violating S5.2 - https://klc.kicad.org/symbol/s5/s5.2/
    Footprint filters should match all appropriate footprints
    Footprint filter 'R_8_ADI' not correctly formatted
    Minuses and underscores in footprint filter 'R_8_ADI' should be escaped with '?' or '*'.
    Footprint filter 'R_8_ADI-M' not correctly formatted
    Minuses and underscores in footprint filter 'R_8_ADI-M' should be escaped with '?' or '*'.
    Footprint filter 'R_8_ADI-L' not correctly formatted
    Minuses and underscores in footprint filter 'R_8_ADI-L' should be escaped with '?' or '*'.
Checking symbol 'nzif_radio_symbol_library:AD8476ARMZ':
  Violating S3.6 - https://klc.kicad.org/symbol/s3/s3.6/
    Pin name position offset
    Pin offset not preferred value
  Violating S5.2 - https://klc.kicad.org/symbol/s5/s5.2/
    Footprint filters should match all appropriate footprints
    Minuses and underscores in footprint filter 'RM_8_ADI*' should be escaped with '?' or '*'.
  Violating S6.2 - https://klc.kicad.org/symbol/s6/s6.2/
    Symbol fields and metadata filled out as required
    S6.2.7: Symbol keywords contain duplicate keywords: {'differential'}
    S6.2.7: Symbol keywords contain tokens which already appear in description: {'driver', 'fully', 'adc'}
Checking symbol 'nzif_radio_symbol_library:AD9508BCPZ':
  Violating S3.6 - https://klc.kicad.org/symbol/s3/s3.6/
    Pin name position offset
    Pin offset not preferred value
  Violating S4.1 - https://klc.kicad.org/symbol/s4/s4.1/
    General pin requirements
    Pins not located on 100mil (=2.54mm) grid:
     - Pin ~{CS}/S2 (1) @ (-700,550) 
     - Pin SDIO/SDA/S1 (24) @ (-700,450) 
     - Pin SCLK/SCL/S0 (19) @ (-700,350) 
     - Pin ~{RESET} (18) @ (-700,250) 
     - Pin CLK (21) @ (-700,50) 
     - Pin ~{CLK} (22) @ (-700,-50) 
     - Pin IN_SEL (23) @ (-700,-150) 
     - Pin S4 (9) @ (-700,-250) 
     - Pin S5 (10) @ (-700,-350) 
  Violating S5.1 - https://klc.kicad.org/symbol/s5/s5.1/
    Symbols with a default footprint link to a valid footprint file
    Footprint field 'CP_24_7_ADI' must be of the format '<Library>:<Footprint>'
  Violating S5.2 - https://klc.kicad.org/symbol/s5/s5.2/
    Footprint filters should match all appropriate footprints
    Minuses and underscores in footprint filter 'CP_24_7_ADI*' should be escaped with '?' or '*'.
  Violating S6.2 - https://klc.kicad.org/symbol/s6/s6.2/
    Symbol fields and metadata filled out as required
    S6.2.7: Symbol keywords contain tokens which already appear in description: {'buffer', 'clock', 'fanout'}
Checking symbol 'nzif_radio_symbol_library:AD9523-1BCPZ':
  Violating S3.2 - https://klc.kicad.org/symbol/s3/s3.2/
    Text fields should use a common text size of 50mils
     - Field Reference at posx -2000 posy 2700 size 60
     - Field Value at posx -2000 posy 2600 size 60
  Violating S3.3 - https://klc.kicad.org/symbol/s3/s3.3/
    Symbol outline and fill requirements
    Component outline is thickness 0mil, recommended is 10mil
  Violating S3.6 - https://klc.kicad.org/symbol/s3/s3.6/
    Pin name position offset
    Pin offset outside allowed range
  Violating S5.2 - https://klc.kicad.org/symbol/s5/s5.2/
    Footprint filters should match all appropriate footprints
    Footprint filter 'CP-72-7_ADI' not correctly formatted
    Minuses and underscores in footprint filter 'CP-72-7_ADI' should be escaped with '?' or '*'.
Checking symbol 'nzif_radio_symbol_library:AD9528':
  Violating S3.3 - https://klc.kicad.org/symbol/s3/s3.3/
    Symbol outline and fill requirements
    Component outline is thickness 0mil, recommended is 10mil
  Violating S4.2 - https://klc.kicad.org/symbol/s4/s4.2/
    Pins should be grouped by function
    For a power converter symbol, positive power pins should be placed at left of symbol
    Power output pins should be placed at right of symbol
  Violating S4.4 - https://klc.kicad.org/symbol/s4/s4.4/
    Pin electrical type should match pin function
    Power pins should be of type POWER INPUT
  Violating S5.1 - https://klc.kicad.org/symbol/s5/s5.1/
    Symbols with a default footprint link to a valid footprint file
    Footprint filter 'CP-72-6_ADI-M' does not match the footprint 'nzif_footprints:CP-72-6_ADI' set for this symbol.
    Footprint filter 'CP-72-6_ADI-L' does not match the footprint 'nzif_footprints:CP-72-6_ADI' set for this symbol.
    Symbol has a footprint defined in the footprint field, but several (3) footprint filters set. If the symbol is for a single default footprint, remove the surplus filters. If the symbol is meant for multiple different footprints, empty the footprint field.
  Violating S5.2 - https://klc.kicad.org/symbol/s5/s5.2/
    Footprint filters should match all appropriate footprints
    Footprint filter 'CP-72-6_ADI' not correctly formatted
    Minuses and underscores in footprint filter 'CP-72-6_ADI' should be escaped with '?' or '*'.
    Footprint filter 'CP-72-6_ADI-M' not correctly formatted
    Minuses and underscores in footprint filter 'CP-72-6_ADI-M' should be escaped with '?' or '*'.
    Footprint filter 'CP-72-6_ADI-L' not correctly formatted
    Minuses and underscores in footprint filter 'CP-72-6_ADI-L' should be escaped with '?' or '*'.
  Violating S6.2 - https://klc.kicad.org/symbol/s6/s6.2/
    Symbol fields and metadata filled out as required
    S6.2.7: Symbol keywords contain tokens which already appear in description: {'generator', 'clock', 'attenuator', 'jitter'}
Checking symbol 'nzif_radio_symbol_library:ADA4620-2ARZ':
  Violating S3.2 - https://klc.kicad.org/symbol/s3/s3.2/
    Text fields should use a common text size of 50mils
     - Field Reference at posx 800 posy 400 size 60
     - Field Value at posx 800 posy 300 size 60
  Violating S3.6 - https://klc.kicad.org/symbol/s3/s3.6/
    Pin name position offset
    Pin offset outside allowed range
  Violating S4.1 - https://klc.kicad.org/symbol/s4/s4.1/
    General pin requirements
    Pins not located on 100mil (=2.54mm) grid:
     - Pin + (3) @ (-450,150) 
     - Pin - (2) @ (-450,-150) 
     - Pin ~ (1) @ (450,0) 
     - Pin + (5) @ (-450,150) 
     - Pin - (6) @ (-450,-150) 
     - Pin ~ (7) @ (450,0) 
  Violating S5.1 - https://klc.kicad.org/symbol/s5/s5.1/
    Symbols with a default footprint link to a valid footprint file
    Footprint filter 'R-8_ADI-M' does not match the footprint 'nzif_footprints:R-8_ADI' set for this symbol.
    Footprint filter 'R-8_ADI-L' does not match the footprint 'nzif_footprints:R-8_ADI' set for this symbol.
    Symbol has a footprint defined in the footprint field, but several (3) footprint filters set. If the symbol is for a single default footprint, remove the surplus filters. If the symbol is meant for multiple different footprints, empty the footprint field.
  Violating S5.2 - https://klc.kicad.org/symbol/s5/s5.2/
    Footprint filters should match all appropriate footprints
    Footprint filter 'R-8_ADI' not correctly formatted
    Minuses and underscores in footprint filter 'R-8_ADI' should be escaped with '?' or '*'.
    Footprint filter 'R-8_ADI-M' not correctly formatted
    Minuses and underscores in footprint filter 'R-8_ADI-M' should be escaped with '?' or '*'.
    Footprint filter 'R-8_ADI-L' not correctly formatted
    Minuses and underscores in footprint filter 'R-8_ADI-L' should be escaped with '?' or '*'.
Checking symbol 'nzif_radio_symbol_library:ADA4899-1YRDZ-R7':
  Violating S3.1 - https://klc.kicad.org/symbol/s3/s3.1/
    Origin is centered on the middle of the symbol
    Symbol unit 1 not centered on origin
  Violating S3.2 - https://klc.kicad.org/symbol/s3/s3.2/
    Text fields should use a common text size of 50mils
     - Field Reference at posx 1000 posy 400 size 60
     - Field Value at posx 1000 posy 300 size 60
  Violating S3.6 - https://klc.kicad.org/symbol/s3/s3.6/
    Pin name position offset
    Pin offset outside allowed range
  Violating S4.1 - https://klc.kicad.org/symbol/s4/s4.1/
    General pin requirements
    Pins not located on 100mil (=2.54mm) grid:
     - Pin FB (1) @ (-450,200) 
     - Pin + (3) @ (-450,100) 
     - Pin - (2) @ (-450,-50) 
     - Pin ~{DIS} (8) @ (-450,-200) 
     - Pin V+ (7) @ (0,450) 
     - Pin V- (5) @ (0,-350) 
     - Pin ~ (6) @ (450,0) 
    Pin V+ (7) @ (0,450) length (225mils) is not a multiple of 50mils
  Violating S5.2 - https://klc.kicad.org/symbol/s5/s5.2/
    Footprint filters should match all appropriate footprints
    Footprint filter 'RD_8_1_ADI' not correctly formatted
    Minuses and underscores in footprint filter 'RD_8_1_ADI' should be escaped with '?' or '*'.
Checking symbol 'nzif_radio_symbol_library:ADA4945-1':
  Violating S3.3 - https://klc.kicad.org/symbol/s3/s3.3/
    Symbol outline and fill requirements
    Component outline is thickness 0mil, recommended is 10mil
  Violating S5.1 - https://klc.kicad.org/symbol/s5/s5.1/
    Symbols with a default footprint link to a valid footprint file
    Footprint filter 'LFCSP16_ADA4945-1ACPZ-R2_ADI-M' does not match the footprint 'nzif_footprints:LFCSP16_ADA4945-1ACPZ-R2_ADI' set for this symbol.
    Footprint filter 'LFCSP16_ADA4945-1ACPZ-R2_ADI-L' does not match the footprint 'nzif_footprints:LFCSP16_ADA4945-1ACPZ-R2_ADI' set for this symbol.
    Symbol has a footprint defined in the footprint field, but several (3) footprint filters set. If the symbol is for a single default footprint, remove the surplus filters. If the symbol is meant for multiple different footprints, empty the footprint field.
  Violating S5.2 - https://klc.kicad.org/symbol/s5/s5.2/
    Footprint filters should match all appropriate footprints
    Footprint filter 'LFCSP16_ADA4945-1ACPZ-R2_ADI' not correctly formatted
    Minuses and underscores in footprint filter 'LFCSP16_ADA4945-1ACPZ-R2_ADI' should be escaped with '?' or '*'.
    Footprint filter 'LFCSP16_ADA4945-1ACPZ-R2_ADI-M' not correctly formatted
    Minuses and underscores in footprint filter 'LFCSP16_ADA4945-1ACPZ-R2_ADI-M' should be escaped with '?' or '*'.
    Footprint filter 'LFCSP16_ADA4945-1ACPZ-R2_ADI-L' not correctly formatted
    Minuses and underscores in footprint filter 'LFCSP16_ADA4945-1ACPZ-R2_ADI-L' should be escaped with '?' or '*'.
  Violating S6.2 - https://klc.kicad.org/symbol/s6/s6.2/
    Symbol fields and metadata filled out as required
    S6.2.7: Symbol keywords contain duplicate sub-tokens (= dash-separated tokens): {'low'}
    S6.2.7: Symbol keywords contain tokens which already appear in description: {'distortion', 'noise', 'differential', 'adc', 'driver'}
Checking symbol 'nzif_radio_symbol_library:ADAU1467WBCPZ300':
  Violating S3.1 - https://klc.kicad.org/symbol/s3/s3.1/
    Origin is centered on the middle of the symbol
    Symbol unit 1 slightly off-center
    Symbol unit 2 slightly off-center
  Violating S3.6 - https://klc.kicad.org/symbol/s3/s3.6/
    Pin name position offset
    Pin offset outside allowed range
  Violating S4.4 - https://klc.kicad.org/symbol/s4/s4.4/
    Pin electrical type should match pin function
    Invisible powerpins in stacks should be of type PASSIVE
    Invisible powerpins in stacks should be of type PASSIVE
    Invisible powerpins in stacks should be of type PASSIVE
    Invisible powerpins in stacks should be of type PASSIVE
    Invisible powerpins in stacks should be of type PASSIVE
    Invisible powerpins in stacks should be of type PASSIVE
    Invisible powerpins in stacks should be of type PASSIVE
    Invisible powerpins in stacks should be of type PASSIVE
    Invisible powerpins in stacks should be of type PASSIVE
  Violating S4.6 - https://klc.kicad.org/symbol/s4/s4.6/
    Hidden pins
    Power input pins must not be invisible unless used in power symbols.
  Violating S5.2 - https://klc.kicad.org/symbol/s5/s5.2/
    Footprint filters should match all appropriate footprints
    Footprint filter 'CP_88_10_ADI' not correctly formatted
    Minuses and underscores in footprint filter 'CP_88_10_ADI' should be escaped with '?' or '*'.
  Violating S6.2 - https://klc.kicad.org/symbol/s6/s6.2/
    Symbol fields and metadata filled out as required
    S6.2.7: Symbol keywords contain tokens which already appear in description: {'dac', 'audio', 'processor', 'adc', 'sigmadsp'}
Checking symbol 'nzif_radio_symbol_library:ADAU1962AWBSTZ-RL':
  Violating S3.3 - https://klc.kicad.org/symbol/s3/s3.3/
    Symbol outline and fill requirements
    Component outline is thickness 0mil, recommended is 10mil
  Violating S3.6 - https://klc.kicad.org/symbol/s3/s3.6/
    Pin name position offset
    Pin offset outside allowed range
  Violating S4.3 - https://klc.kicad.org/symbol/s4/s4.3/
    Rules for pin stacking
    NC Pin NC (10) @ (-900,-100) (x=-22.86, y=-2.54) is stacked on other pins
    NC Pin NC (11) @ (-900,-100) (x=-22.86, y=-2.54) is stacked on other pins
    NC Pin NC (4) @ (-900,-100) (x=-22.86, y=-2.54) is stacked on other pins
    NC Pin NC (5) @ (-900,-100) (x=-22.86, y=-2.54) is stacked on other pins
    NC Pin NC (6) @ (-900,-100) (x=-22.86, y=-2.54) is stacked on other pins
    NC Pin NC (7) @ (-900,-100) (x=-22.86, y=-2.54) is stacked on other pins
    NC Pin NC (8) @ (-900,-100) (x=-22.86, y=-2.54) is stacked on other pins
    NC Pin NC (9) @ (-900,-100) (x=-22.86, y=-2.54) is stacked on other pins
  Violating S5.2 - https://klc.kicad.org/symbol/s5/s5.2/
    Footprint filters should match all appropriate footprints
    Footprint filter 'ST_80_2_ADI' not correctly formatted
    Minuses and underscores in footprint filter 'ST_80_2_ADI' should be escaped with '?' or '*'.
Checking symbol 'nzif_radio_symbol_library:ADAU1978xBCP':
  Violating S4.1 - https://klc.kicad.org/symbol/s4/s4.1/
    General pin requirements
    Pins not located on 100mil (=2.54mm) grid:
     - Pin AIN1P (33) @ (-850,600) 
     - Pin AIN1N (32) @ (-850,500) 
     - Pin AIN2P (35) @ (-850,300) 
     - Pin AIN2N (34) @ (-850,200) 
     - Pin AIN3P (37) @ (-850,0) 
     - Pin AIN3N (36) @ (-850,-100) 
     - Pin AIN4P (39) @ (-850,-300) 
     - Pin AIN4N (38) @ (-850,-400) 
     - Pin VREF (2) @ (-850,-600) 
     - Pin PLL_FILT (3) @ (-850,-700) 
     - Pin EP (41) @ (-350,-900) 
     - Pin AGND (1) @ (-250,-900) 
     - Pin AGND (5) @ (-150,-900) 
     - Pin AGND (21) @ (-50,-900) 
     - Pin AGND (22) @ (50,-900) 
     - Pin AGND (28) @ (150,-900) 
     - Pin AGND (29) @ (250,-900) 
     - Pin DGND (11) @ (350,-900) 
     - Pin MCLKIN (7) @ (850,600) 
     - Pin LRCLK (15) @ (850,500) 
     - Pin BCLK (16) @ (850,400) 
     - Pin SDATAOUT1 (13) @ (850,300) 
     - Pin SDATAOUT2 (14) @ (850,200) 
     - Pin SDA (17) @ (850,0) 
     - Pin SCL (18) @ (850,-100) 
     - Pin ADDR0 (19) @ (850,-200) 
     - Pin ADDR1 (20) @ (850,-300) 
     - Pin SA_MODE (9) @ (850,-500) 
     - Pin ~{PD}/~{RST} (6) @ (850,-600) 
     - Pin DVDD (10) @ (850,-700) 
  Violating S4.2 - https://klc.kicad.org/symbol/s4/s4.2/
    Pins should be grouped by function
    For a power converter symbol, positive power pins should be placed at left of symbol
  Violating S4.3 - https://klc.kicad.org/symbol/s4/s4.3/
    Rules for pin stacking
    NC Pin NC (23) @ (500,-800) (x=12.7, y=-20.32) is stacked on other pins
    NC Pin NC (24) @ (500,-800) (x=12.7, y=-20.32) is stacked on other pins
    NC Pin NC (25) @ (500,-800) (x=12.7, y=-20.32) is stacked on other pins
    NC Pin NC (26) @ (500,-800) (x=12.7, y=-20.32) is stacked on other pins
    NC Pin NC (27) @ (500,-800) (x=12.7, y=-20.32) is stacked on other pins
    NC Pin NC (30) @ (500,-800) (x=12.7, y=-20.32) is stacked on other pins
    NC Pin NC (8) @ (500,-800) (x=12.7, y=-20.32) is stacked on other pins
  Violating S4.4 - https://klc.kicad.org/symbol/s4/s4.4/
    Pin electrical type should match pin function
    Power pins should be of type POWER INPUT
    Pin types should match pin function
  Violating S5.1 - https://klc.kicad.org/symbol/s5/s5.1/
    Symbols with a default footprint link to a valid footprint file
    Specified footprint library does not exist
Checking symbol 'nzif_radio_symbol_library:ADCMP600BRJZ-R2':
  Violating S3.2 - https://klc.kicad.org/symbol/s3/s3.2/
    Text fields should use a common text size of 50mils
     - Field Reference at posx 200 posy 700 size 60
     - Field Value at posx 200 posy 600 size 60
  Violating S3.6 - https://klc.kicad.org/symbol/s3/s3.6/
    Pin name position offset
    Pin offset outside allowed range
  Violating S5.1 - https://klc.kicad.org/symbol/s5/s5.1/
    Symbols with a default footprint link to a valid footprint file
    Footprint filter 'RJ_5_ADI-M' does not match the footprint 'nzif_footprints:RJ_5_ADI' set for this symbol.
    Footprint filter 'RJ_5_ADI-L' does not match the footprint 'nzif_footprints:RJ_5_ADI' set for this symbol.
    Symbol has a footprint defined in the footprint field, but several (3) footprint filters set. If the symbol is for a single default footprint, remove the surplus filters. If the symbol is meant for multiple different footprints, empty the footprint field.
  Violating S5.2 - https://klc.kicad.org/symbol/s5/s5.2/
    Footprint filters should match all appropriate footprints
    Footprint filter 'RJ_5_ADI' not correctly formatted
    Minuses and underscores in footprint filter 'RJ_5_ADI' should be escaped with '?' or '*'.
    Footprint filter 'RJ_5_ADI-M' not correctly formatted
    Minuses and underscores in footprint filter 'RJ_5_ADI-M' should be escaped with '?' or '*'.
    Footprint filter 'RJ_5_ADI-L' not correctly formatted
    Minuses and underscores in footprint filter 'RJ_5_ADI-L' should be escaped with '?' or '*'.
Checking symbol 'nzif_radio_symbol_library:ADCMP604BKSZ-REEL7':
  Violating S3.2 - https://klc.kicad.org/symbol/s3/s3.2/
    Text fields should use a common text size of 50mils
     - Field Reference at posx 400 posy -300 size 60
     - Field Value at posx 400 posy -400 size 60
  Violating S3.6 - https://klc.kicad.org/symbol/s3/s3.6/
    Pin name position offset
    Pin offset outside allowed range
  Violating S4.1 - https://klc.kicad.org/symbol/s4/s4.1/
    General pin requirements
    Pin Q (1) @ (400,0) length (175mils) is not a multiple of 50mils
  Violating S5.1 - https://klc.kicad.org/symbol/s5/s5.1/
    Symbols with a default footprint link to a valid footprint file
    Footprint filter 'KS_6_ADI-M' does not match the footprint 'nzif_footprints:KS_6_ADI' set for this symbol.
    Footprint filter 'KS_6_ADI-L' does not match the footprint 'nzif_footprints:KS_6_ADI' set for this symbol.
    Symbol has a footprint defined in the footprint field, but several (3) footprint filters set. If the symbol is for a single default footprint, remove the surplus filters. If the symbol is meant for multiple different footprints, empty the footprint field.
  Violating S5.2 - https://klc.kicad.org/symbol/s5/s5.2/
    Footprint filters should match all appropriate footprints
    Footprint filter 'KS_6_ADI' not correctly formatted
    Minuses and underscores in footprint filter 'KS_6_ADI' should be escaped with '?' or '*'.
    Footprint filter 'KS_6_ADI-M' not correctly formatted
    Minuses and underscores in footprint filter 'KS_6_ADI-M' should be escaped with '?' or '*'.
    Footprint filter 'KS_6_ADI-L' not correctly formatted
    Minuses and underscores in footprint filter 'KS_6_ADI-L' should be escaped with '?' or '*'.
Checking symbol 'nzif_radio_symbol_library:DSLVDS1048PWT':
  Violating S3.3 - https://klc.kicad.org/symbol/s3/s3.3/
    Symbol outline and fill requirements
    Component outline is thickness 0mil, recommended is 10mil
  Violating S3.6 - https://klc.kicad.org/symbol/s3/s3.6/
    Pin name position offset
    Pin offset outside allowed range
Checking symbol 'nzif_radio_symbol_library:EPC2019':
  Violating S3.2 - https://klc.kicad.org/symbol/s3/s3.2/
    Text fields should use a common text size of 50mils
     - Field Reference at posx 0 posy 500 size 60
     - Field Value at posx 0 posy 400 size 60
  Violating S3.3 - https://klc.kicad.org/symbol/s3/s3.3/
    Symbol outline and fill requirements
    Component outline is thickness 0mil, recommended is 10mil
  Violating S3.6 - https://klc.kicad.org/symbol/s3/s3.6/
    Pin name position offset
    Pin offset outside allowed range
  Violating S5.2 - https://klc.kicad.org/symbol/s5/s5.2/
    Footprint filters should match all appropriate footprints
    Footprint filter 'EPC2019_ECC' not correctly formatted
    Minuses and underscores in footprint filter 'EPC2019_ECC' should be escaped with '?' or '*'.
Checking symbol 'nzif_radio_symbol_library:FZT951TA':
  Violating S3.2 - https://klc.kicad.org/symbol/s3/s3.2/
    Text fields should use a common text size of 50mils
     - Field Reference at posx 400 posy 100 size 60
     - Field Value at posx 400 posy -100 size 60
  Violating S3.6 - https://klc.kicad.org/symbol/s3/s3.6/
    Pin name position offset
    Pin offset outside allowed range
  Violating S5.2 - https://klc.kicad.org/symbol/s5/s5.2/
    Footprint filters should match all appropriate footprints
    Footprint filter 'SOT223-FZT690B-DN_DIO' not correctly formatted
    Minuses and underscores in footprint filter 'SOT223-FZT690B-DN_DIO' should be escaped with '?' or '*'.
  Violating S6.2 - https://klc.kicad.org/symbol/s6/s6.2/
    Symbol fields and metadata filled out as required
    Datasheet entry 'FZT951TA' does not look like a URL
Checking symbol 'nzif_radio_symbol_library:LMG1020YFFT':
  Violating S3.2 - https://klc.kicad.org/symbol/s3/s3.2/
    Text fields should use a common text size of 50mils
     - Field Reference at posx 0 posy 100 size 60
     - Field Value at posx 0 posy 0 size 60
  Violating S3.3 - https://klc.kicad.org/symbol/s3/s3.3/
    Symbol outline and fill requirements
    Component outline is thickness 0mil, recommended is 10mil
  Violating S3.6 - https://klc.kicad.org/symbol/s3/s3.6/
    Pin name position offset
    Pin offset outside allowed range
  Violating S5.2 - https://klc.kicad.org/symbol/s5/s5.2/
    Footprint filters should match all appropriate footprints
    Footprint filter 'YFF0006AEAE' not correctly formatted
Checking symbol 'nzif_radio_symbol_library:LT3094EDD-PBF':
  Violating S3.3 - https://klc.kicad.org/symbol/s3/s3.3/
    Symbol outline and fill requirements
    Component outline is thickness 0mil, recommended is 10mil
  Violating S3.6 - https://klc.kicad.org/symbol/s3/s3.6/
    Pin name position offset
    Pin offset outside allowed range
  Violating S4.2 - https://klc.kicad.org/symbol/s4/s4.2/
    Pins should be grouped by function
    For a power converter symbol, positive power pins should be placed at left of symbol
    Power output pins should be placed at right of symbol
  Violating S4.4 - https://klc.kicad.org/symbol/s4/s4.4/
    Pin electrical type should match pin function
    Power pins should be of type POWER INPUT
  Violating S5.1 - https://klc.kicad.org/symbol/s5/s5.1/
    Symbols with a default footprint link to a valid footprint file
    Footprint filter 'DD_05-08-1725_ADI-M' does not match the footprint 'nzif_footprints:DD_05-08-1725_ADI' set for this symbol.
    Footprint filter 'DD_05-08-1725_ADI-L' does not match the footprint 'nzif_footprints:DD_05-08-1725_ADI' set for this symbol.
    Symbol has a footprint defined in the footprint field, but several (3) footprint filters set. If the symbol is for a single default footprint, remove the surplus filters. If the symbol is meant for multiple different footprints, empty the footprint field.
  Violating S5.2 - https://klc.kicad.org/symbol/s5/s5.2/
    Footprint filters should match all appropriate footprints
    Footprint filter 'DD_05-08-1725_ADI' not correctly formatted
    Minuses and underscores in footprint filter 'DD_05-08-1725_ADI' should be escaped with '?' or '*'.
    Footprint filter 'DD_05-08-1725_ADI-M' not correctly formatted
    Minuses and underscores in footprint filter 'DD_05-08-1725_ADI-M' should be escaped with '?' or '*'.
    Footprint filter 'DD_05-08-1725_ADI-L' not correctly formatted
    Minuses and underscores in footprint filter 'DD_05-08-1725_ADI-L' should be escaped with '?' or '*'.
Checking symbol 'nzif_radio_symbol_library:LT5400ACMS8E-4-PBF':
  Violating S3.3 - https://klc.kicad.org/symbol/s3/s3.3/
    Symbol outline and fill requirements
    Component outline is thickness 0mil, recommended is 10mil
  Violating S3.6 - https://klc.kicad.org/symbol/s3/s3.6/
    Pin name position offset
    Pin offset outside allowed range
  Violating S5.2 - https://klc.kicad.org/symbol/s5/s5.2/
    Footprint filters should match all appropriate footprints
    Footprint filter 'MSOP-8_MS_LIT' not correctly formatted
    Footprint filter 'MSOP-8_MS_LIT' seems to contain pin-number, but should not!
    Minuses and underscores in footprint filter 'MSOP-8_MS_LIT' should be escaped with '?' or '*'.
Checking symbol 'nzif_radio_symbol_library:LT5400BCMS8E-7-PBF':
  Violating S3.3 - https://klc.kicad.org/symbol/s3/s3.3/
    Symbol outline and fill requirements
    Component outline is thickness 0mil, recommended is 10mil
  Violating S3.6 - https://klc.kicad.org/symbol/s3/s3.6/
    Pin name position offset
    Pin offset outside allowed range
  Violating S5.2 - https://klc.kicad.org/symbol/s5/s5.2/
    Footprint filters should match all appropriate footprints
    Footprint filter 'MSOP-8_MS_LIT' not correctly formatted
    Footprint filter 'MSOP-8_MS_LIT' seems to contain pin-number, but should not!
    Minuses and underscores in footprint filter 'MSOP-8_MS_LIT' should be escaped with '?' or '*'.
Checking symbol 'nzif_radio_symbol_library:LT5400BCMS8E-8-TRPBF':
  Violating S3.3 - https://klc.kicad.org/symbol/s3/s3.3/
    Symbol outline and fill requirements
    Component outline is thickness 0mil, recommended is 10mil
  Violating S3.6 - https://klc.kicad.org/symbol/s3/s3.6/
    Pin name position offset
    Pin offset outside allowed range
  Violating S5.1 - https://klc.kicad.org/symbol/s5/s5.1/
    Symbols with a default footprint link to a valid footprint file
    Footprint filter 'MSOP-8_MS_LIT-M' does not match the footprint 'nzif_footprints:MSOP-8_MS_LIT' set for this symbol.
    Footprint filter 'MSOP-8_MS_LIT-L' does not match the footprint 'nzif_footprints:MSOP-8_MS_LIT' set for this symbol.
    Symbol has a footprint defined in the footprint field, but several (3) footprint filters set. If the symbol is for a single default footprint, remove the surplus filters. If the symbol is meant for multiple different footprints, empty the footprint field.
  Violating S5.2 - https://klc.kicad.org/symbol/s5/s5.2/
    Footprint filters should match all appropriate footprints
    Footprint filter 'MSOP-8_MS_LIT' not correctly formatted
    Footprint filter 'MSOP-8_MS_LIT' seems to contain pin-number, but should not!
    Minuses and underscores in footprint filter 'MSOP-8_MS_LIT' should be escaped with '?' or '*'.
    Footprint filter 'MSOP-8_MS_LIT-M' not correctly formatted
    Footprint filter 'MSOP-8_MS_LIT-M' seems to contain pin-number, but should not!
    Minuses and underscores in footprint filter 'MSOP-8_MS_LIT-M' should be escaped with '?' or '*'.
    Footprint filter 'MSOP-8_MS_LIT-L' not correctly formatted
    Footprint filter 'MSOP-8_MS_LIT-L' seems to contain pin-number, but should not!
    Minuses and underscores in footprint filter 'MSOP-8_MS_LIT-L' should be escaped with '?' or '*'.
Checking symbol 'nzif_radio_symbol_library:LT8418ACBZ-R7':
  Violating S3.2 - https://klc.kicad.org/symbol/s3/s3.2/
    Text fields should use a common text size of 50mils
     - Field Reference at posx 0 posy 1200 size 60
     - Field Value at posx 0 posy 1100 size 60
  Violating S3.3 - https://klc.kicad.org/symbol/s3/s3.3/
    Symbol outline and fill requirements
    Component outline is thickness 0mil, recommended is 10mil
  Violating S3.6 - https://klc.kicad.org/symbol/s3/s3.6/
    Pin name position offset
    Pin offset outside allowed range
  Violating S4.2 - https://klc.kicad.org/symbol/s4/s4.2/
    Pins should be grouped by function
    For a power converter symbol, positive power pins should be placed at left of symbol
    Power output pins should be placed at right of symbol
  Violating S4.4 - https://klc.kicad.org/symbol/s4/s4.4/
    Pin electrical type should match pin function
    Power pins should be of type POWER INPUT
  Violating S5.2 - https://klc.kicad.org/symbol/s5/s5.2/
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

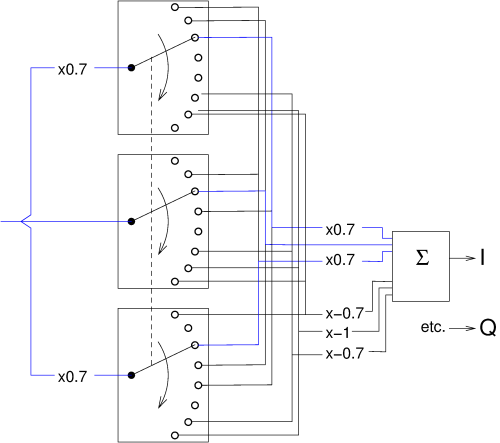
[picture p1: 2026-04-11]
nzif/docs/articles/The polyphase mixer_files/tn17fig4.png

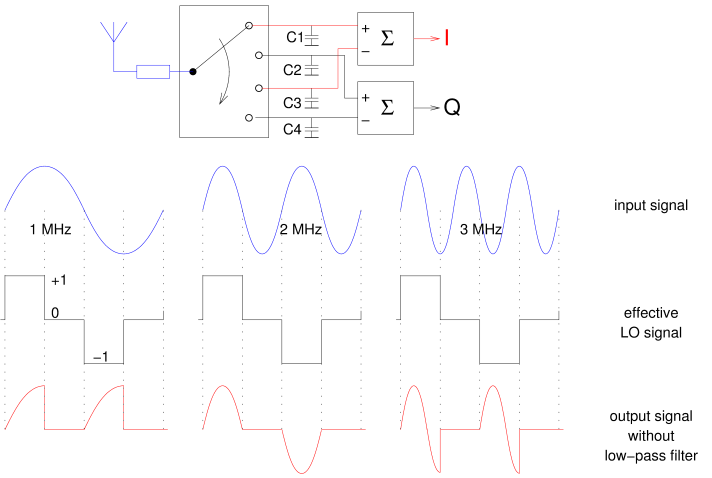
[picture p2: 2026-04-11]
nzif/docs/articles/The polyphase mixer_files/tn17fig3a.png

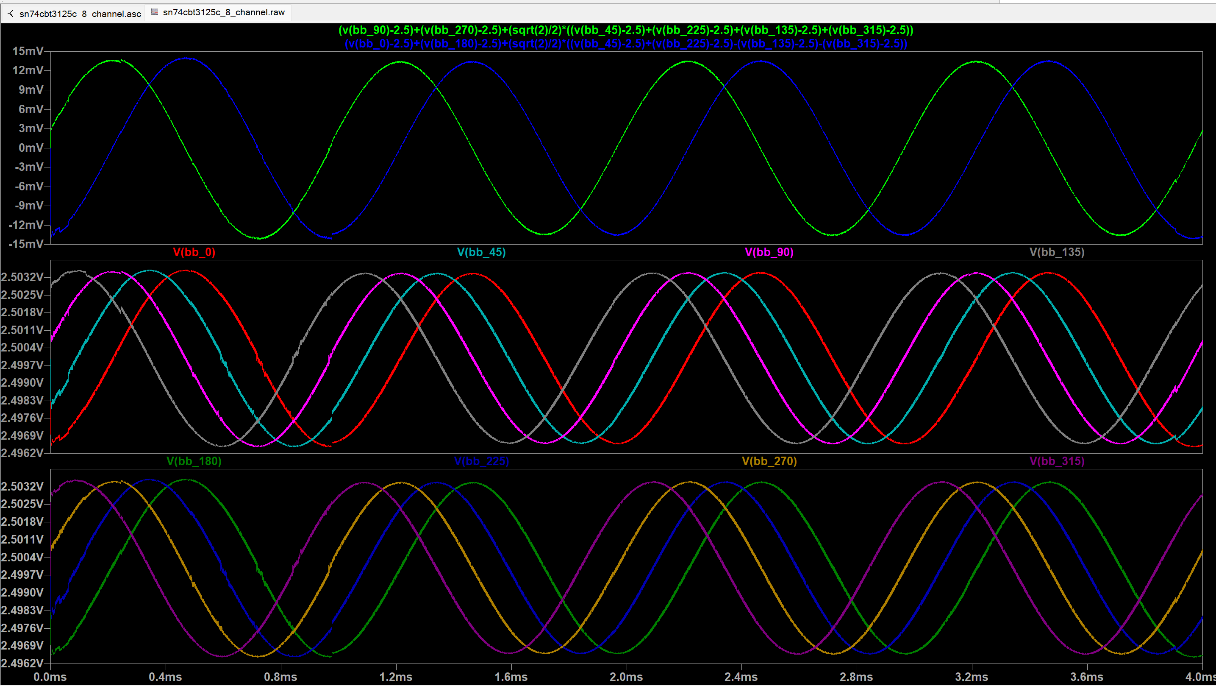
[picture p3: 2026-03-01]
nzif/docs/images/rx_mixer_sim_output.png

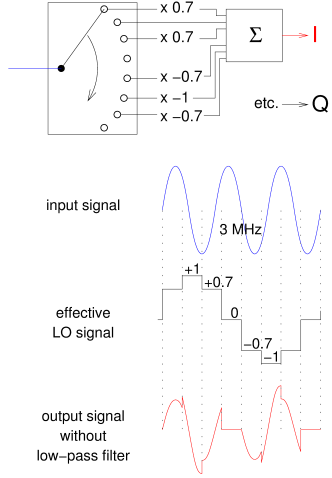
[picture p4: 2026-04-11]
nzif/docs/articles/The polyphase mixer_files/tn17fig3b.png

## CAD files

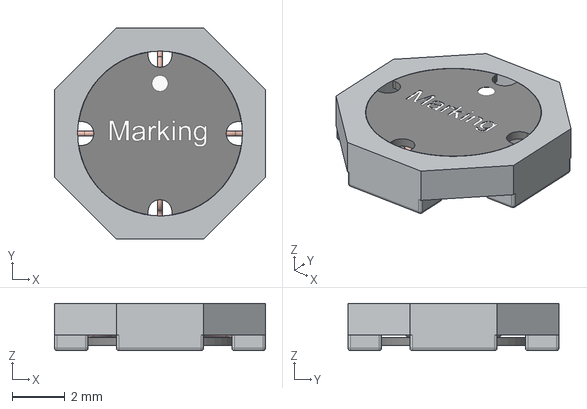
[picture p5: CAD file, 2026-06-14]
nzif/nzif_3D_models/L_Wurth_WE-TDC-8018.step
8.00 x 8.00 x 1.80 mm

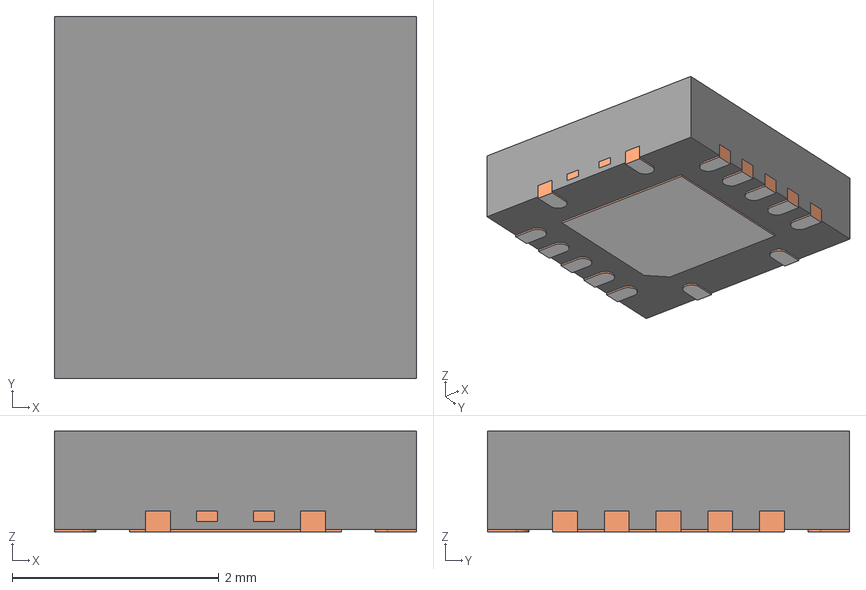
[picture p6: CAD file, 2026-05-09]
nzif/nzif_3D_models/RGY0014A.stp
3.50 x 3.50 x 0.975 mm
BODY-QFN
FRAME-RWA0014A
PIN1-ID

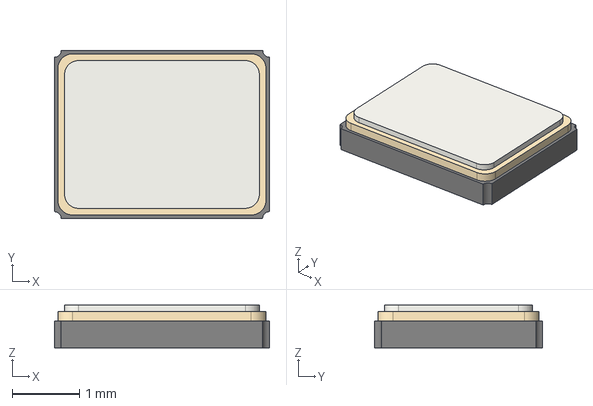
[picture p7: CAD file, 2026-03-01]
nzif/nzif_3D_models/CTS_535_TCXO.step
3.20 x 2.50 x 0.64 mm

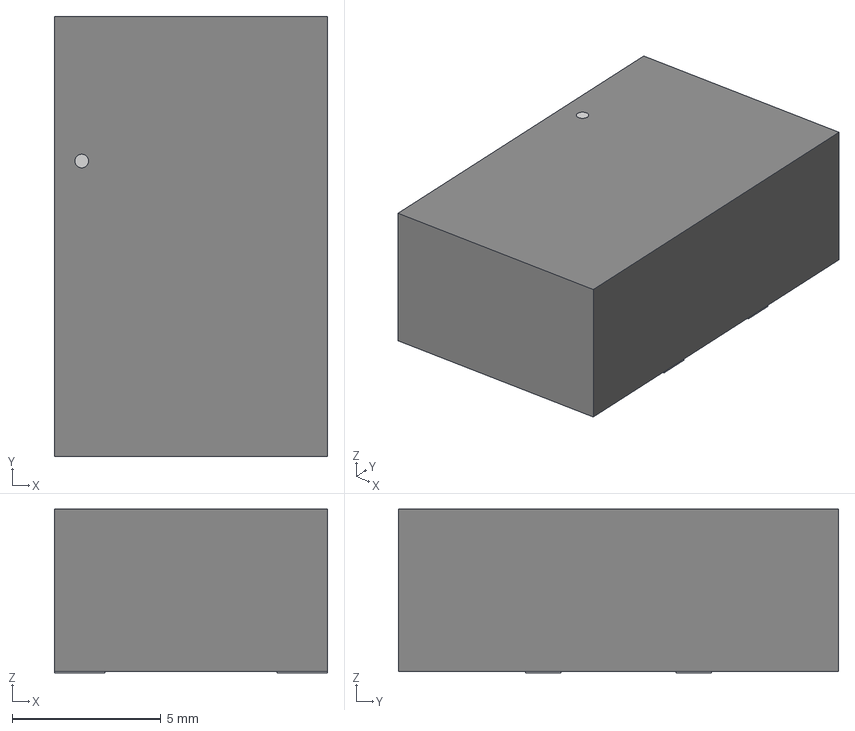
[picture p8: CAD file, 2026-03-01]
nzif/nzif_3D_models/ABLNO_ABR.step
9.19 x 14.8 x 5.51 mm

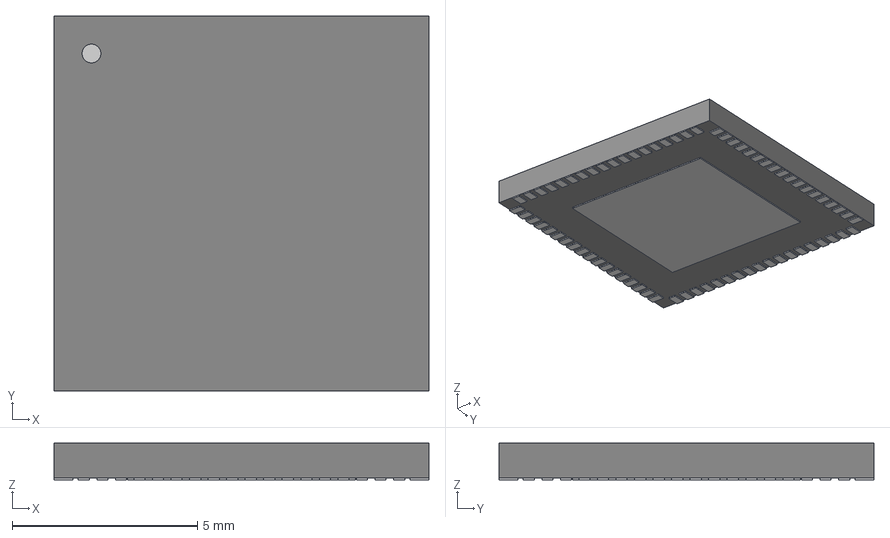
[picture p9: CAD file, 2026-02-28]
nzif/nzif_3D_models/CP-72-7_ADI.step
10.1 x 10.1 x 0.993 mm

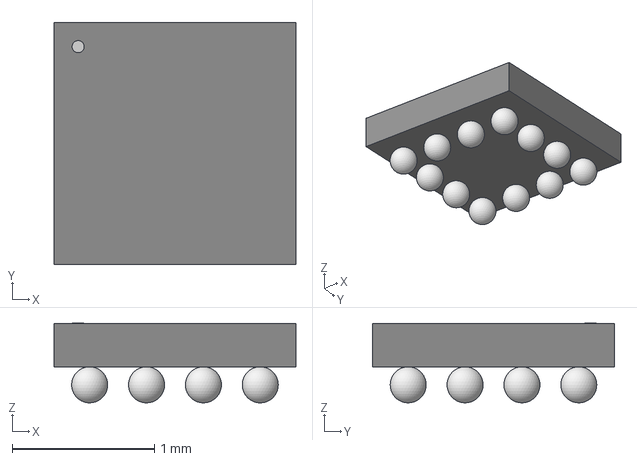
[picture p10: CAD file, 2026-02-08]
nzif/nzif_3D_models/CB-12-17_ADI.step
1.70 x 1.70 x 0.561 mm

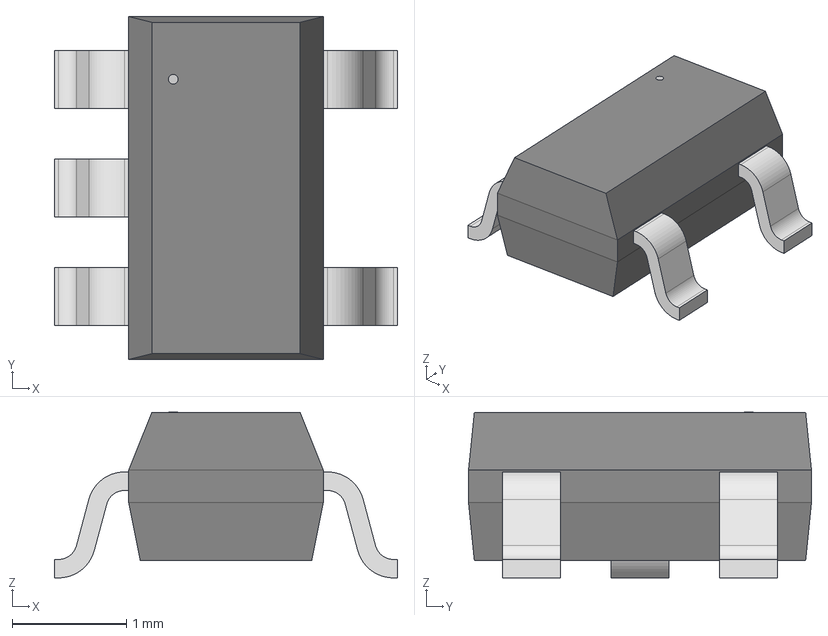
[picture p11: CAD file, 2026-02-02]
nzif/nzif_3D_models/RJ_5_ADI.step
3.00 x 3.00 x 1.45 mm

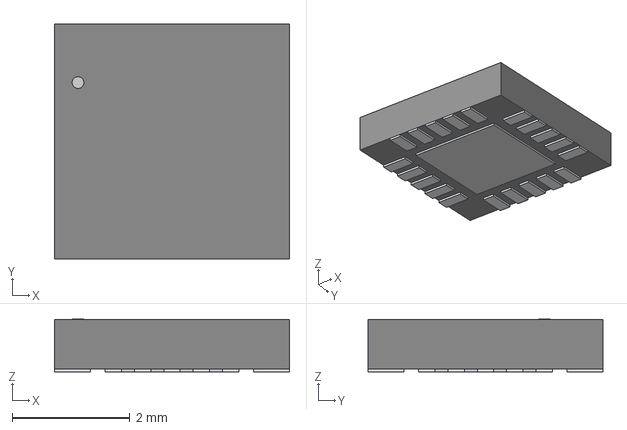
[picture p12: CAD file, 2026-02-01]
nzif/nzif_3D_models/QFN20_4X4_PSM.step
3.99 x 3.99 x 0.892 mm

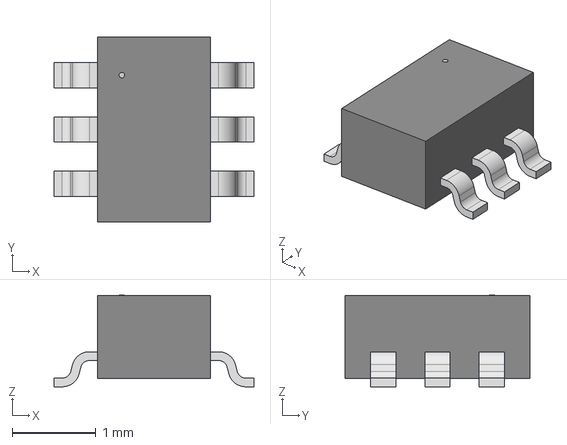
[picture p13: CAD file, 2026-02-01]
nzif/nzif_3D_models/KS_6_ADI.step
2.39 x 2.21 x 1.09 mm

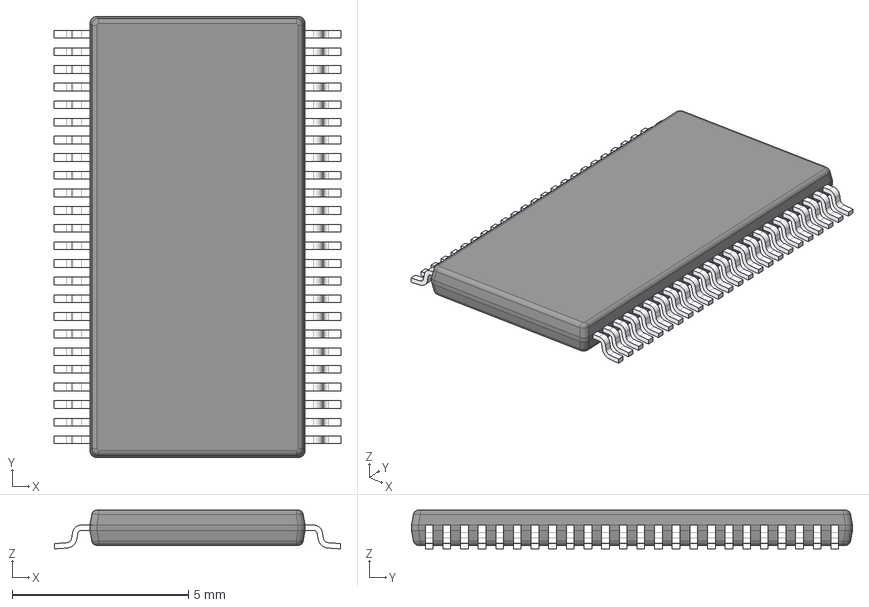
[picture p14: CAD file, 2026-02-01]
nzif/nzif_3D_models/DGG0048A.stp
8.12 x 12.5 x 1.10 mm
BODY-SO
LEAD-SO x 48
PIN1-ID

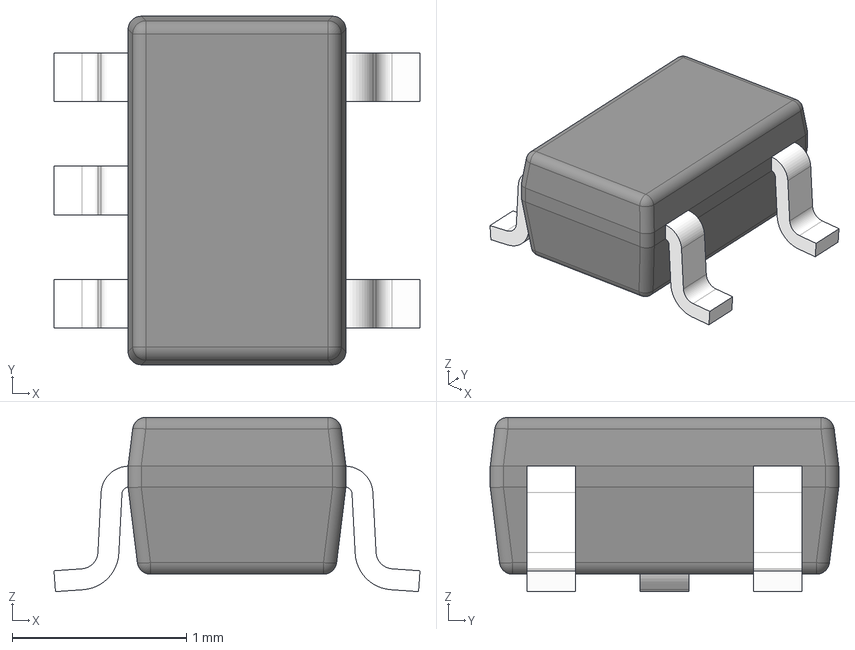
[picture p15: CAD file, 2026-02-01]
nzif/nzif_3D_models/DCK0005A.stp
2.10 x 2.00 x 1.00 mm
BODY-SOT
LEAD-SOT x 5
PIN1-ID

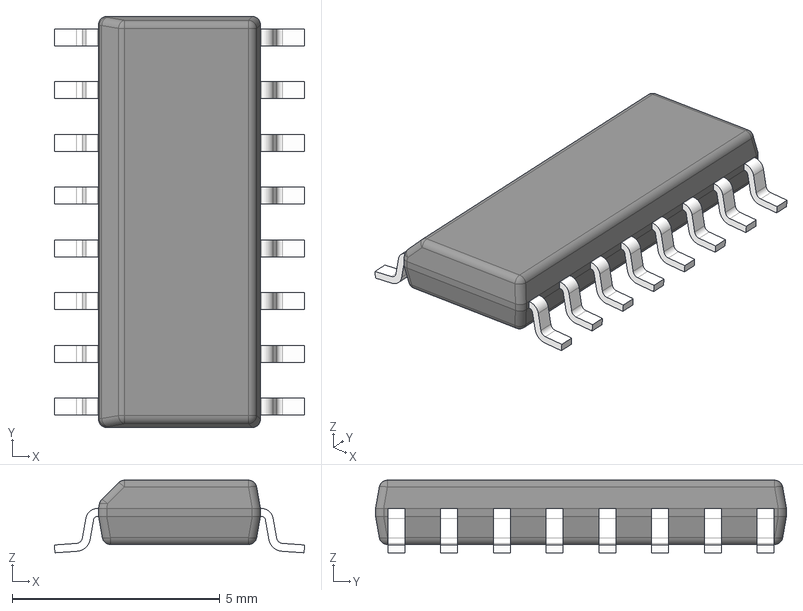
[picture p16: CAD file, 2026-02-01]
nzif/nzif_3D_models/D0016A.stp
6.03 x 9.90 x 1.75 mm
BODY-SO
LEAD-SO x 16
PIN1-ID

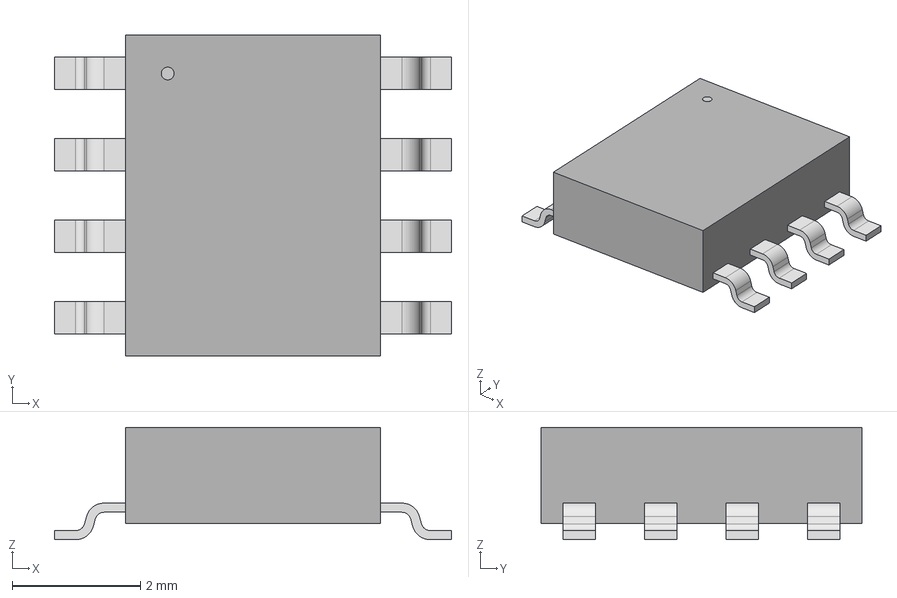
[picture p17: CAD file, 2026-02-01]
nzif/nzif_3D_models/R_8_ADI.step
6.20 x 5.00 x 1.75 mm

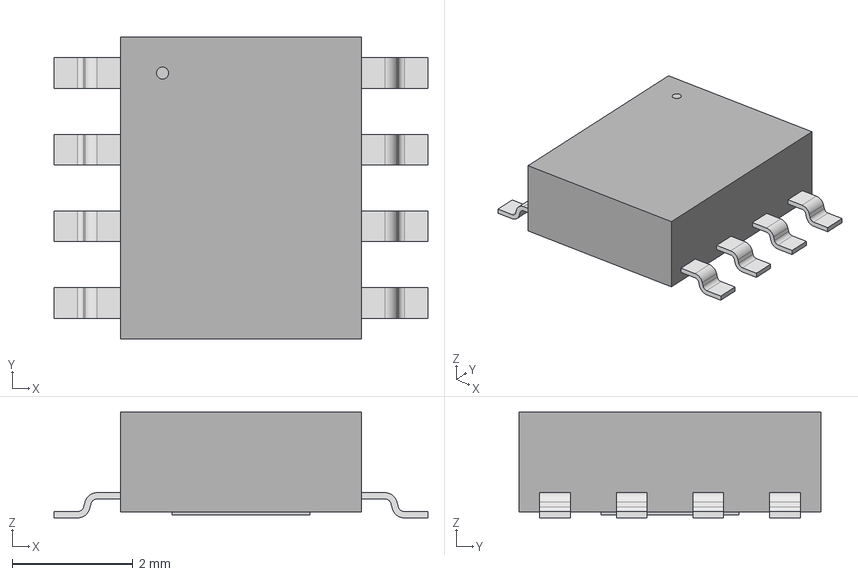
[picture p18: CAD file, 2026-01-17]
nzif/nzif_3D_models/RD_8_1_ADI.step
6.20 x 5.00 x 1.75 mm

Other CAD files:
nzif/nzif_3D_models/SOIC-16_ONS.step
nzif/nzif_3D_models/SOT223-FZT690B-DN_DIO.step
nzif/nzif_3D_models/PW0016A.stp
nzif/nzif_3D_models/DD_05-08-1725_ADI.step
nzif/nzif_3D_models/CP-32-4_ADI.step
nzif/nzif_3D_models/CP-72-6_ADI.step
nzif/nzif_3D_models/CP_24_7_ADI.step
nzif/nzif_3D_models/CP_88_8_ADI.step
nzif/nzif_3D_models/DBV0005A.stp
nzif/nzif_3D_models/DFN-S8_6x5MC_MCH.step
nzif/nzif_3D_models/DPAK_TO-252__TYPEA_STM.step
nzif/nzif_3D_models/LFCSP16_ADA4945-1ACPZ-R2_ADI.step
nzif/nzif_3D_models/MSOP-8_MS_LIT.step
nzif/nzif_3D_models/PW0014A.stp
nzif/nzif_3D_models/R-8_ADI.step
nzif/nzif_3D_models/RA_4_ADI.step
nzif/nzif_3D_models/RM_8_ADI.step
nzif/nzif_3D_models/SOT-23_S6_LIT.step
nzif/nzif_3D_models/ST_80_2_ADI.step

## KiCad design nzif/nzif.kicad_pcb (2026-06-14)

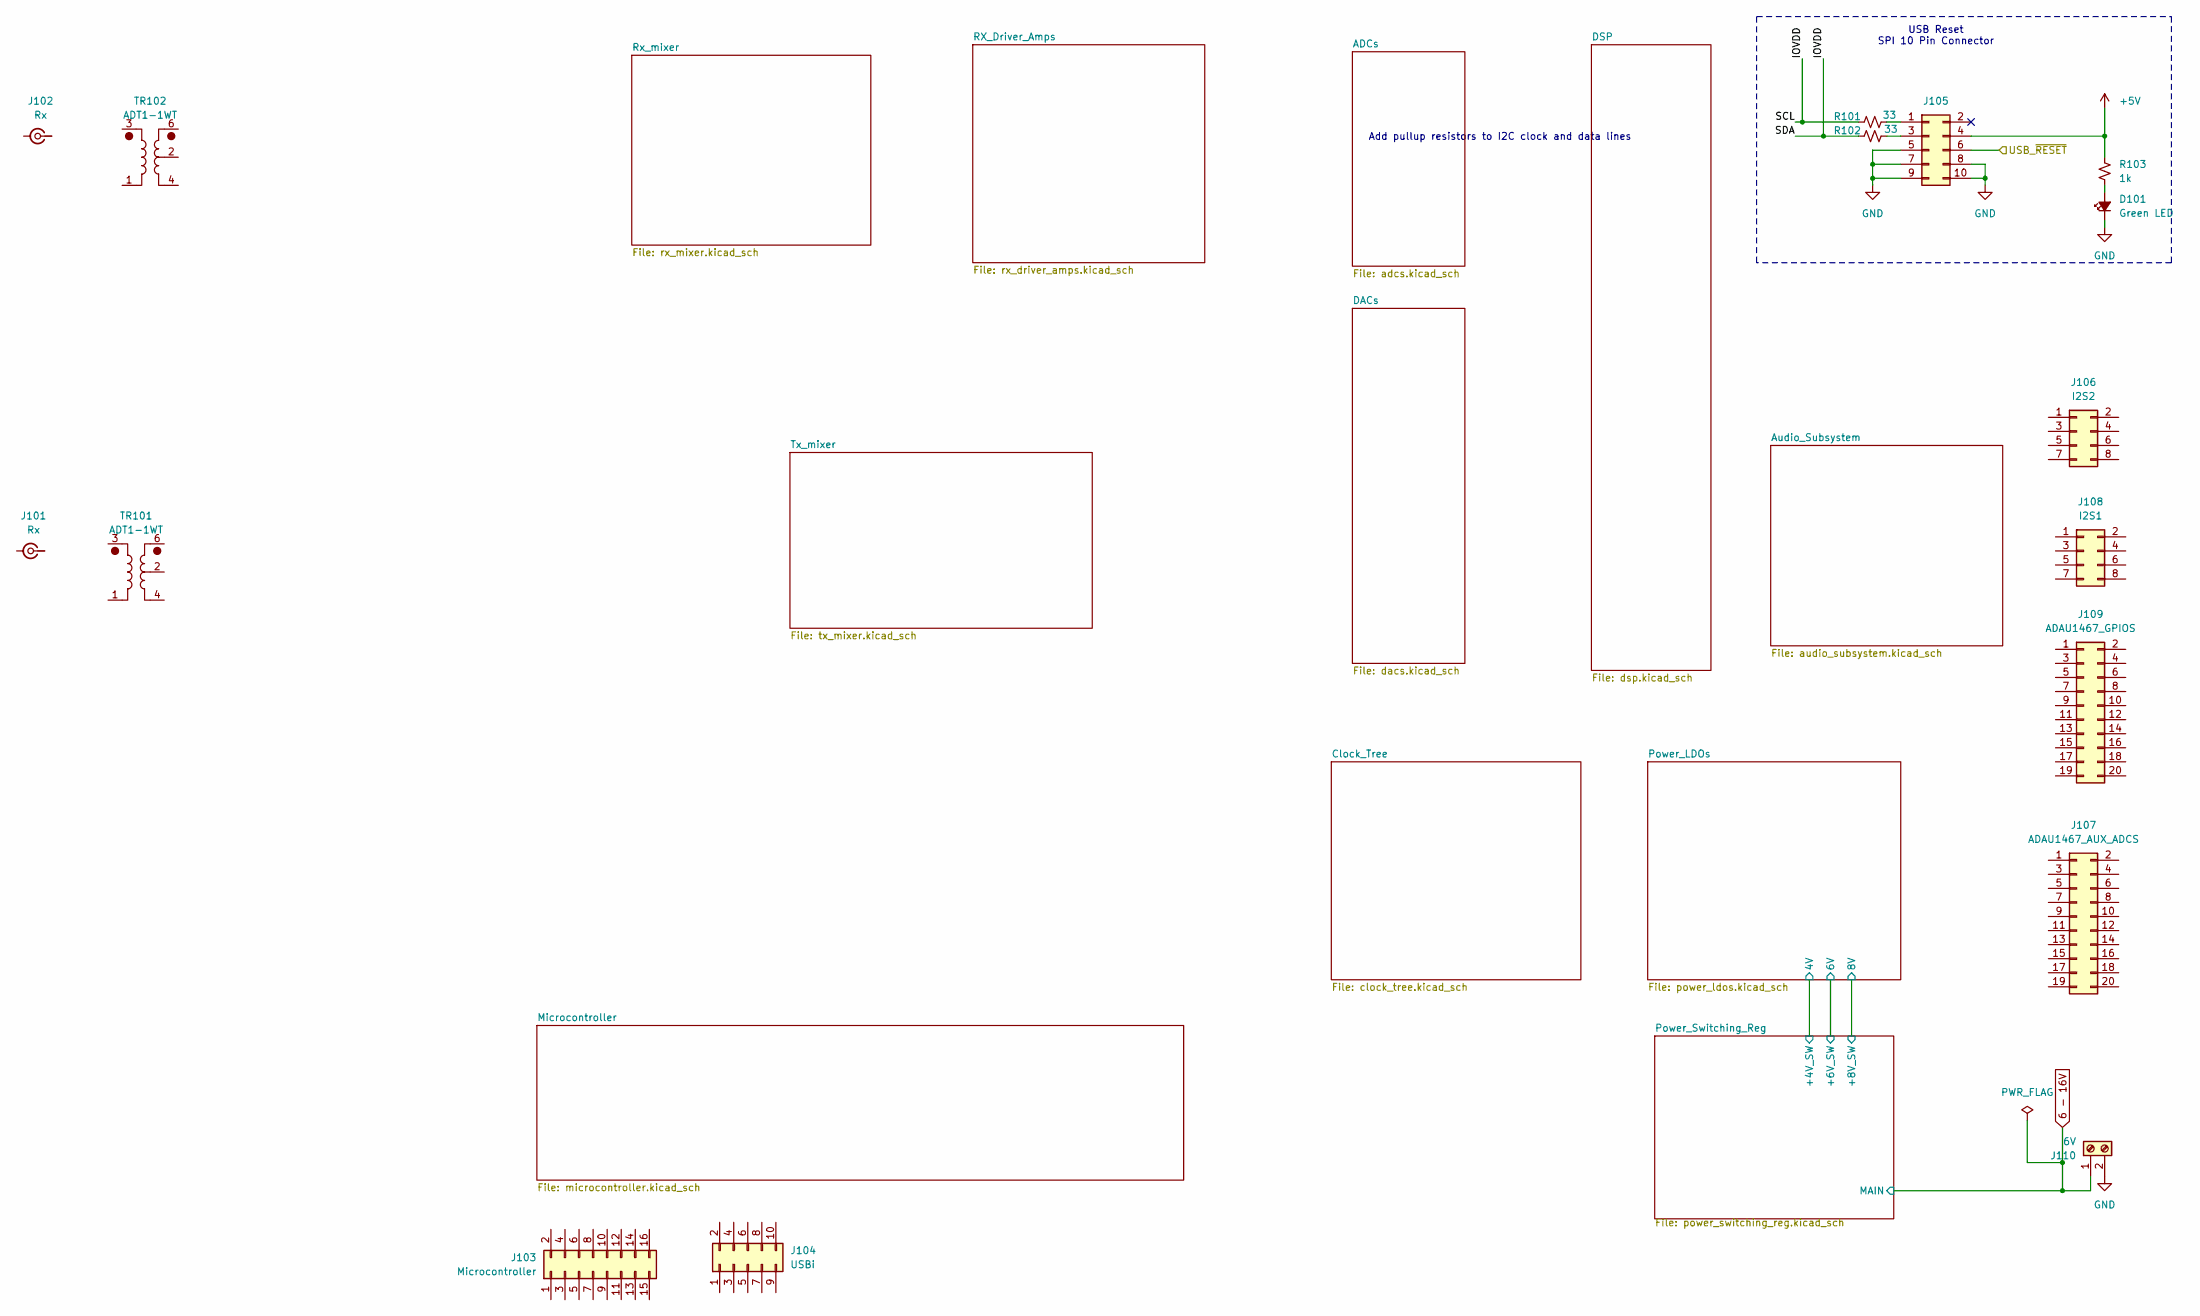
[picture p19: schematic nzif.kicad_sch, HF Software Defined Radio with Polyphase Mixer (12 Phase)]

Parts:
D101: Green LED
J101, J102: Rx
J103: Microcontroller
J104: USBi
J105: Conn_02x05_Odd_Even
J106: I2S2
J107: ADAU1467_AUX_ADCS
J108: I2S1
J109: ADAU1467_GPIOS
J110: 6V
R101, R102: 33
R103: 1k
TR101, TR102: ADT1-1WT; Mini-Circuits_CD542_H2.84mm

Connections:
/6_-_16V: J110.1; also elsewhere on the board
/DAC_CM_1.5V: TR102.2; also elsewhere on the board
/RF-In: J101.1 (In), TR101.3
/Rx_mixer/RF+: TR101.6; also elsewhere on the board
/Rx_mixer/RF-: TR101.4; also elsewhere on the board
/TX-out: J102.1 (In), TR102.3
/Tx_mixer/TX_RF+: TR102.6; also elsewhere on the board
/Tx_mixer/TX_RF-: TR102.4; also elsewhere on the board
unnamed 283: J101.2 (Ext); also elsewhere on the board
unnamed 284: J102.2 (Ext); also elsewhere on the board
unnamed 310: D101.2 (A), R103.2; also elsewhere on the board
unnamed: J105.4, R103.1

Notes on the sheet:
Add pullup resistors to I2C clock and data lines
USB Reset SPI 10 Pin Connector

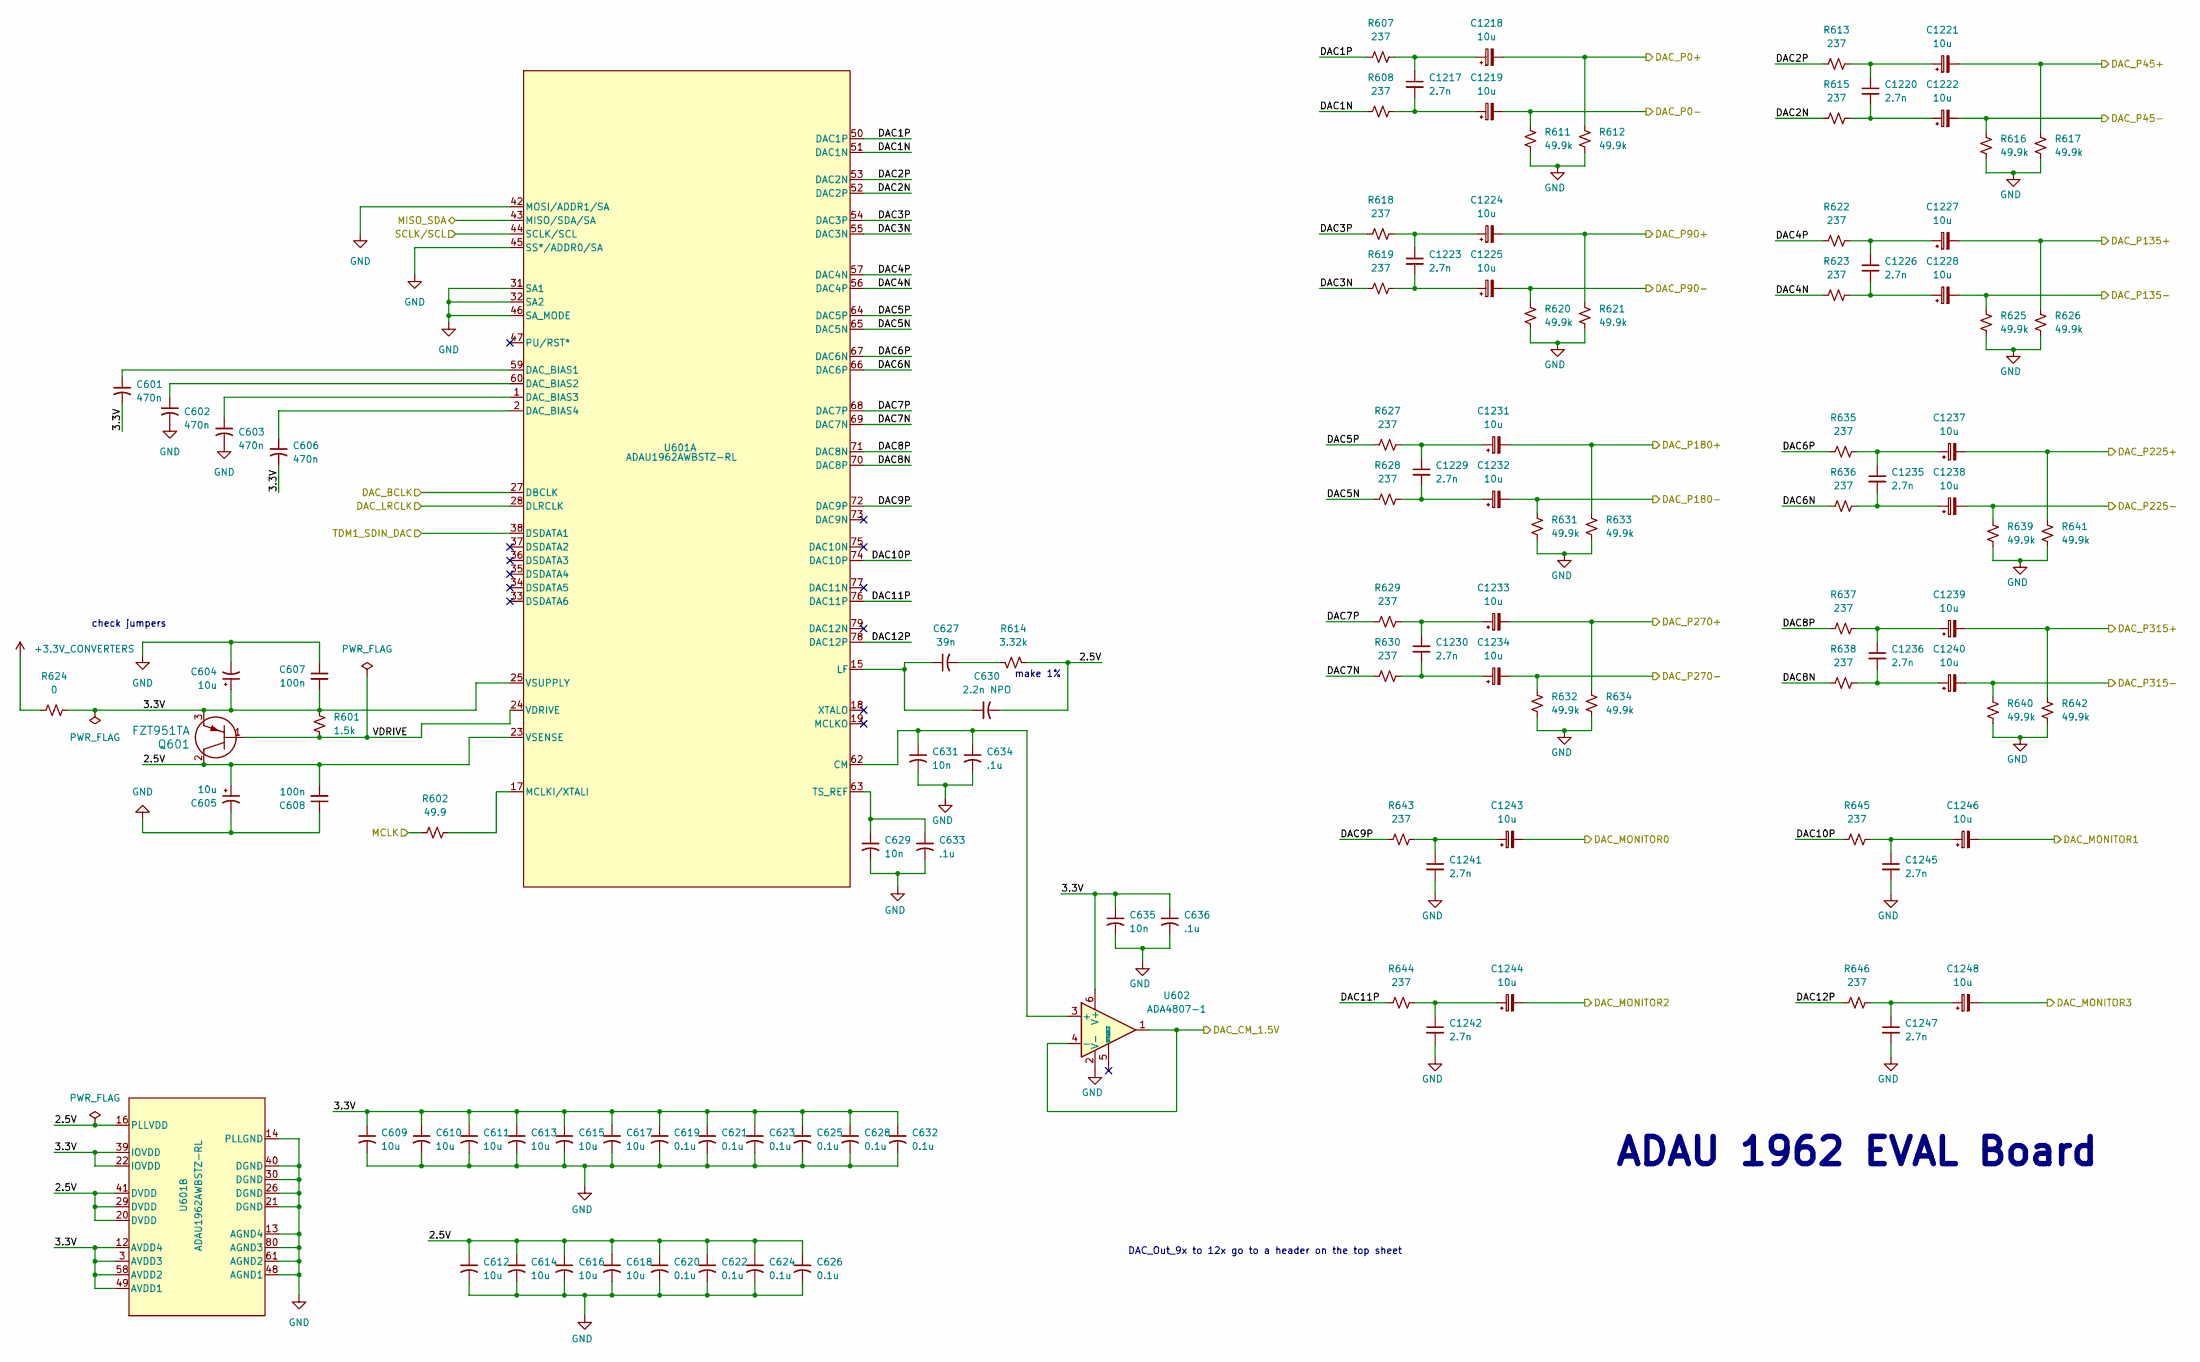
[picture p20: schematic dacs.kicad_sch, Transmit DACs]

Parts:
C601, C602, C603, C606: 470n; C_0402_1005Metric_Pad0.74x0.62mm_HandSolder
C604, C605, C609, C610, C611, C612, C613, C614, C615, C616, C617, C618: 10u; C_0402_1005Metric_Pad0.74x0.62mm_HandSolder
C607, C608: 100n; C_0402_1005Metric_Pad0.74x0.62mm_HandSolder
C619, C620, C621, C622, C623, C624, C625, C626, C628, C632: 0.1u; C_0402_1005Metric_Pad0.74x0.62mm_HandSolder
C627: 39n; C_0402_1005Metric_Pad0.74x0.62mm_HandSolder
C629, C631, C635: 10n; C_0402_1005Metric_Pad0.74x0.62mm_HandSolder
C630: 2.2n NPO; C_0402_1005Metric_Pad0.74x0.62mm_HandSolder
C633, C634, C636: .1u; C_0402_1005Metric_Pad0.74x0.62mm_HandSolder
C1217, C1220, C1223, C1226, C1229, C1230, C1241, C1242, C1245, C1247: 2.7n; C_0402_1005Metric_Pad0.74x0.62mm_HandSolder
C1218, C1219, C1221, C1222, C1224, C1225, C1227, C1228, C1231, C1232, C1233, C1234, C1237, C1238, C1239, C1240, C1243, C1244, C1246, C1248: 10u; CP_Elec_4x4.5
C1235, C1236: 2.7n; CP_Elec_4x4.5
Q601: FZT951TA; SOT223-FZT690B-DN_DIO
R601: 1.5k; R_0402_1005Metric_Pad0.72x0.64mm_HandSolder
R602: 49.9; R_0402_1005Metric_Pad0.72x0.64mm_HandSolder
R607, R608, R613, R615, R618, R619, R622, R623, R627, R628, R629, R630, R635, R636, R637, R638, R643, R644, R645, R646: 237; R_0402_1005Metric_Pad0.72x0.64mm_HandSolder
R611, R612, R616, R617, R620, R621, R625, R626, R631, R632, R633, R634, R639, R640, R641, R642: 49.9k; R_0402_1005Metric_Pad0.72x0.64mm_HandSolder
R614: 3.32k; R_0402_1005Metric_Pad0.72x0.64mm_HandSolder
R624: 0; R_0402_1005Metric_Pad0.72x0.64mm_HandSolder
U601: ADAU1962AWBSTZ-RL; ST_80_2_ADI
U602: ADA4807-1; SOT-23-6

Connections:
+3.3V_CONVERTERS: R624.1; also elsewhere on the board
/DAC_CLK: R602.1; also elsewhere on the board
/DAC_CM_1.5V: U602.1, U602.4 (-); also elsewhere on the board
/DACs/2.5V: C605.1, C608.2, C612.1, C614.1, C616.1, C618.1, C620.1, C622.1, C624.1, C626.1, C630.2, Q601.2, R614.2, U601.16 (PLLVDD), U601.20 (DVDD), U601.23 (VSENSE), U601.29 (DVDD), U601.41 (DVDD)
/DACs/3.3V: C601.2, C604.1, C606.2, C607.2, C609.1, C610.1, C611.1, C613.1, C615.1, C617.1, C619.1, C621.1, C623.1, C625.1, C628.1, C632.1, C635.1, C636.1, Q601.3, R601.1, R624.2, U601.3 (AVDD3), U601.12 (AVDD4), U601.22 (IOVDD), U601.25 (VSUPPLY), U601.39 (IOVDD), U601.49 (AVDD1), U601.58 (AVDD2), U602.6 (V+)
/DACs/DAC1N: R608.1, U601.51 (DAC1N)
/DACs/DAC1P: R607.1, U601.50 (DAC1P)
/DACs/DAC2N: R615.1, U601.52 (DAC2P)
/DACs/DAC2P: R613.1, U601.53 (DAC2N)
/DACs/DAC3N: R619.1, U601.55 (DAC3N)
/DACs/DAC3P: R618.1, U601.54 (DAC3P)
/DACs/DAC4N: R623.1, U601.56 (DAC4P)
/DACs/DAC4P: R622.1, U601.57 (DAC4N)
/DACs/DAC5N: R628.1, U601.65 (DAC5N)
/DACs/DAC5P: R627.1, U601.64 (DAC5P)
/DACs/DAC6N: R636.1, U601.66 (DAC6P)
/DACs/DAC6P: R635.1, U601.67 (DAC6N)
/DACs/DAC7N: R630.1, U601.69 (DAC7N)
/DACs/DAC7P: R629.1, U601.68 (DAC7P)
/DACs/DAC8N: R638.1, U601.70 (DAC8P)
/DACs/DAC8P: R637.1, U601.71 (DAC8N)
/DACs/DAC9P: R643.1, U601.72 (DAC9P)
/DACs/DAC10P: R645.1, U601.74 (DAC10P)
/DACs/DAC11P: R644.1, U601.76 (DAC11P)
/DACs/DAC12P: R646.1, U601.78 (DAC12P)
/DACs/DAC_BCLK: U601.27 (DBCLK); also elsewhere on the board
/DACs/DAC_LRCLK: U601.28 (DLRCLK); also elsewhere on the board
/DACs/DAC_MONITOR0: C1243.2; also elsewhere on the board
/DACs/DAC_MONITOR1: C1246.2; also elsewhere on the board
/DACs/DAC_MONITOR2: C1244.2; also elsewhere on the board
/DACs/DAC_MONITOR3: C1248.2; also elsewhere on the board
/DACs/DAC_P0+: C1218.2, C1219.2, R611.2, R612.2; also elsewhere on the board
/DACs/DAC_P45+: C1221.2, R617.2; also elsewhere on the board
/DACs/DAC_P45-: C1222.2, R616.2; also elsewhere on the board
/DACs/DAC_P90+: C1224.2, C1225.2, R620.2, R621.2; also elsewhere on the board
/DACs/DAC_P135+: C1227.2, R626.2; also elsewhere on the board
/DACs/DAC_P135-: C1228.2, R625.2; also elsewhere on the board
/DACs/DAC_P180+: C1231.2, C1232.2, R631.2, R633.2; also elsewhere on the board
/DACs/DAC_P225+: C1237.2, R641.2; also elsewhere on the board
/DACs/DAC_P225-: C1238.2, R639.2; also elsewhere on the board
/DACs/DAC_P270+: C1233.2, C1234.2, R632.2, R634.2; also elsewhere on the board
/DACs/DAC_P315+: C1239.2, R642.2; also elsewhere on the board
/DACs/DAC_P315-: C1240.2, R640.2; also elsewhere on the board
/DACs/TDM1_SDIN_DAC: U601.38 (DSDATA1); also elsewhere on the board
/DACs/VDRIVE: Q601.1, R601.2, U601.24 (VDRIVE)
/SCL0: U601.44 (SCLK/SCL); also elsewhere on the board
/SDA0: U601.43 (MISO/SDA/SA); also elsewhere on the board
unnamed: C627.2, R614.1
unnamed: C1217.1, C1218.1, R607.2
unnamed: C1217.2, C1219.1, R608.2
unnamed: C1220.1, C1221.1, R613.2
unnamed: C1220.2, C1222.1, R615.2
unnamed: C1223.1, C1224.1, R618.2
unnamed: C1223.2, C1225.1, R619.2
unnamed: C1226.1, C1227.1, R622.2
unnamed: C1226.2, C1228.1, R623.2
unnamed: C1229.1, C1231.1, R627.2
unnamed: C1229.2, C1232.1, R628.2
unnamed: C1230.1, C1233.1, R629.2
unnamed: C1230.2, C1234.1, R630.2
unnamed: C1235.1, C1237.1, R635.2
unnamed: C1235.2, C1238.1, R636.2
unnamed: C1236.1, C1239.1, R637.2
unnamed: C1236.2, C1240.1, R638.2
unnamed: C1241.1, C1243.1, R643.2
unnamed: C1242.1, C1244.1, R644.2
unnamed: C1245.1, C1246.1, R645.2
unnamed: C1247.1, C1248.1, R646.2
unnamed: C631.1, C634.1, U601.62 (CM), U602.3 (+)
unnamed: C601.1, U601.59 (DAC_BIAS1)
unnamed: C602.1, U601.60 (DAC_BIAS2)
unnamed: C603.1, U601.1 (DAC_BIAS3)
unnamed: C606.1, U601.2 (DAC_BIAS4)
unnamed: C627.1, C630.1, U601.15 (LF)
unnamed: R602.2, U601.17 (MCLKI/XTALI)
unnamed: C629.1, C633.1, U601.63 (TS_REF)

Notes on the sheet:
make 1%
check jumpers
DAC_Out_9x to 12x go to a header on the top sheet
ADAU 1962 EVAL Board

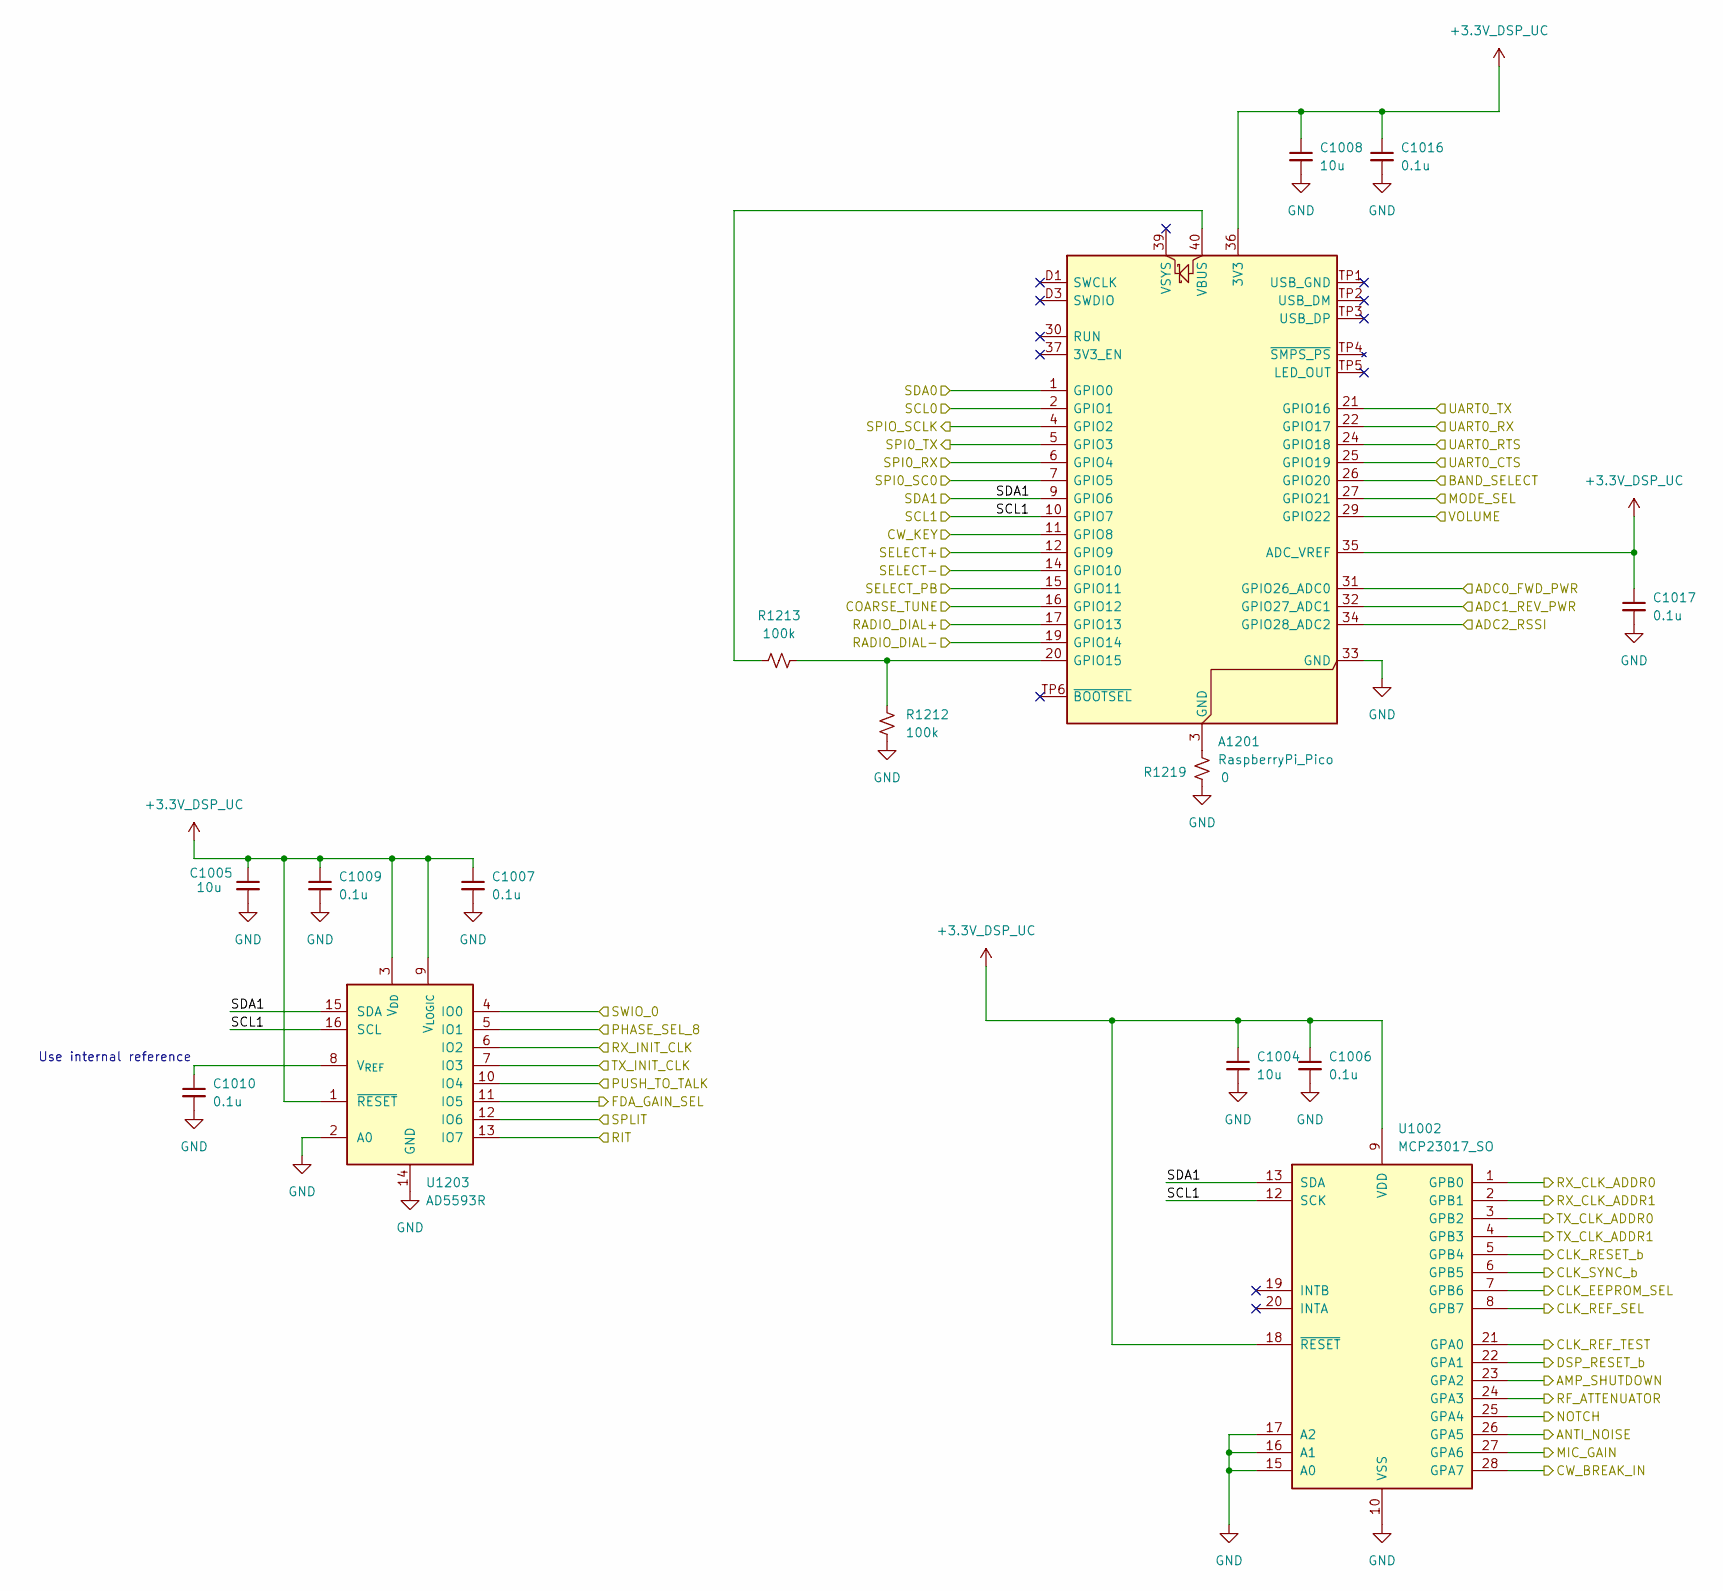
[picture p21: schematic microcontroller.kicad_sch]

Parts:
A1201: RaspberryPi_Pico; RaspberryPi_Pico_SMD
C1004, C1005, C1008: 10u; C_0402_1005Metric_Pad0.74x0.62mm_HandSolder
C1006, C1007, C1009, C1010, C1016, C1017: 0.1u; C_0402_1005Metric_Pad0.74x0.62mm_HandSolder
R1212, R1213: 100k; R_0402_1005Metric_Pad0.72x0.64mm_HandSolder
R1219: 0; R_0402_1005Metric_Pad0.72x0.64mm_HandSolder
U1002: MCP23017_SO; SOIC-28W_7.5x17.9mm_P1.27mm
U1203: AD5593R; TSSOP-16_4.4x5mm_P0.65mm

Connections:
+3.3V_DSP_UC: A1201.35 (ADC_VREF), A1201.36 (3V3), C1004.1, C1005.1, C1006.1, C1007.1, C1008.1, C1009.1, C1016.1, C1017.1, U1002.9 (VDD), U1002.18 (~RESET), U1203.1 (~RESET), U1203.3 (V_{DD}), U1203.9 (V_{LOGIC}); also elsewhere on the board
/ADC0_FWD_PWR: A1201.31 (GPIO26_ADC0); also elsewhere on the board
/ADC1_REV_PWR: A1201.32 (GPIO27_ADC1); also elsewhere on the board
/ADC2_RSSI: A1201.34 (GPIO28_ADC2); also elsewhere on the board
/AMP_SHUTDOWN: U1002.23 (GPA2); also elsewhere on the board
/ANTI_NOISE: U1002.26 (GPA5); also elsewhere on the board
/BAND_SELECT: A1201.26 (GPIO20); also elsewhere on the board
/CLK_EEPROM_SEL: U1002.7 (GPB6); also elsewhere on the board
/CLK_REF_SEL: U1002.8 (GPB7); also elsewhere on the board
/CLK_REF_TEST: U1002.21 (GPA0); also elsewhere on the board
/CLK_RESET_b: U1002.5 (GPB4); also elsewhere on the board
/CLK_SYNC_b: U1002.6 (GPB5); also elsewhere on the board
/COARSE_TUNE: A1201.16 (GPIO12); also elsewhere on the board
/CW_BREAK_IN: U1002.28 (GPA7); also elsewhere on the board
/CW_KEY: A1201.11 (GPIO8); also elsewhere on the board
/DSP_RESET_b: U1002.22 (GPA1); also elsewhere on the board
/FDA_GAIN_SEL: U1203.11 (IO5); also elsewhere on the board
/MIC_GAIN: U1002.27 (GPA6); also elsewhere on the board
/MODE_SEL: A1201.27 (GPIO21); also elsewhere on the board
/NOTCH: U1002.25 (GPA4); also elsewhere on the board
/PHASE_SEL_8: U1203.5 (IO1); also elsewhere on the board
/PUSH_TO_TALK: U1203.10 (IO4); also elsewhere on the board
/RADIO_DIAL+: A1201.17 (GPIO13); also elsewhere on the board
/RADIO_DIAL-: A1201.19 (GPIO14); also elsewhere on the board
/RF_ATTENUATOR: U1002.24 (GPA3); also elsewhere on the board
/RIT: U1203.13 (IO7); also elsewhere on the board
/RX_CLK_ADDR0: U1002.1 (GPB0); also elsewhere on the board
/RX_CLK_ADDR1: U1002.2 (GPB1); also elsewhere on the board
/RX_INIT_CLK: U1203.6 (IO2); also elsewhere on the board
/SCL0: A1201.2 (GPIO1); also elsewhere on the board
/SCL1: A1201.10 (GPIO7), U1002.12 (SCK), U1203.16 (SCL); also elsewhere on the board
/SDA0: A1201.1 (GPIO0); also elsewhere on the board
/SDA1: A1201.9 (GPIO6), U1002.13 (SDA), U1203.15 (SDA); also elsewhere on the board
/SELECT+: A1201.12 (GPIO9); also elsewhere on the board
/SELECT-: A1201.14 (GPIO10); also elsewhere on the board
/SELECT_PB: A1201.15 (GPIO11); also elsewhere on the board
/SPI0_RX: A1201.6 (GPIO4); also elsewhere on the board
/SPI0_SC0: A1201.7 (GPIO5); also elsewhere on the board
/SPI0_TX: A1201.5 (GPIO3); also elsewhere on the board
/SPIO_SCLK: A1201.4 (GPIO2); also elsewhere on the board
/SPLIT: U1203.12 (IO6); also elsewhere on the board
/SWIO_0: U1203.4 (IO0); also elsewhere on the board
/TX_CLK_ADDR0: U1002.3 (GPB2); also elsewhere on the board
/TX_CLK_ADDR1: U1002.4 (GPB3); also elsewhere on the board
/TX_INIT_CLK: U1203.7 (IO3); also elsewhere on the board
/UART0_CTS: A1201.25 (GPIO19); also elsewhere on the board
/UART0_RTS: A1201.24 (GPIO18); also elsewhere on the board
/UART0_RX: A1201.22 (GPIO17); also elsewhere on the board
/UART0_TX: A1201.21 (GPIO16); also elsewhere on the board
/VOLUME: A1201.29 (GPIO22); also elsewhere on the board
unnamed: A1201.3 (GND), A1201.8 (GND), A1201.13 (GND), A1201.18 (GND), A1201.23 (GND), A1201.28 (GND), A1201.38 (GND), A1201.D2 (GND), R1219.1
unnamed: A1201.20 (GPIO15), R1212.1, R1213.2
unnamed: A1201.40 (VBUS), R1213.1
unnamed: C1010.1, U1203.8 (V_{REF})

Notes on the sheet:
Use internal reference

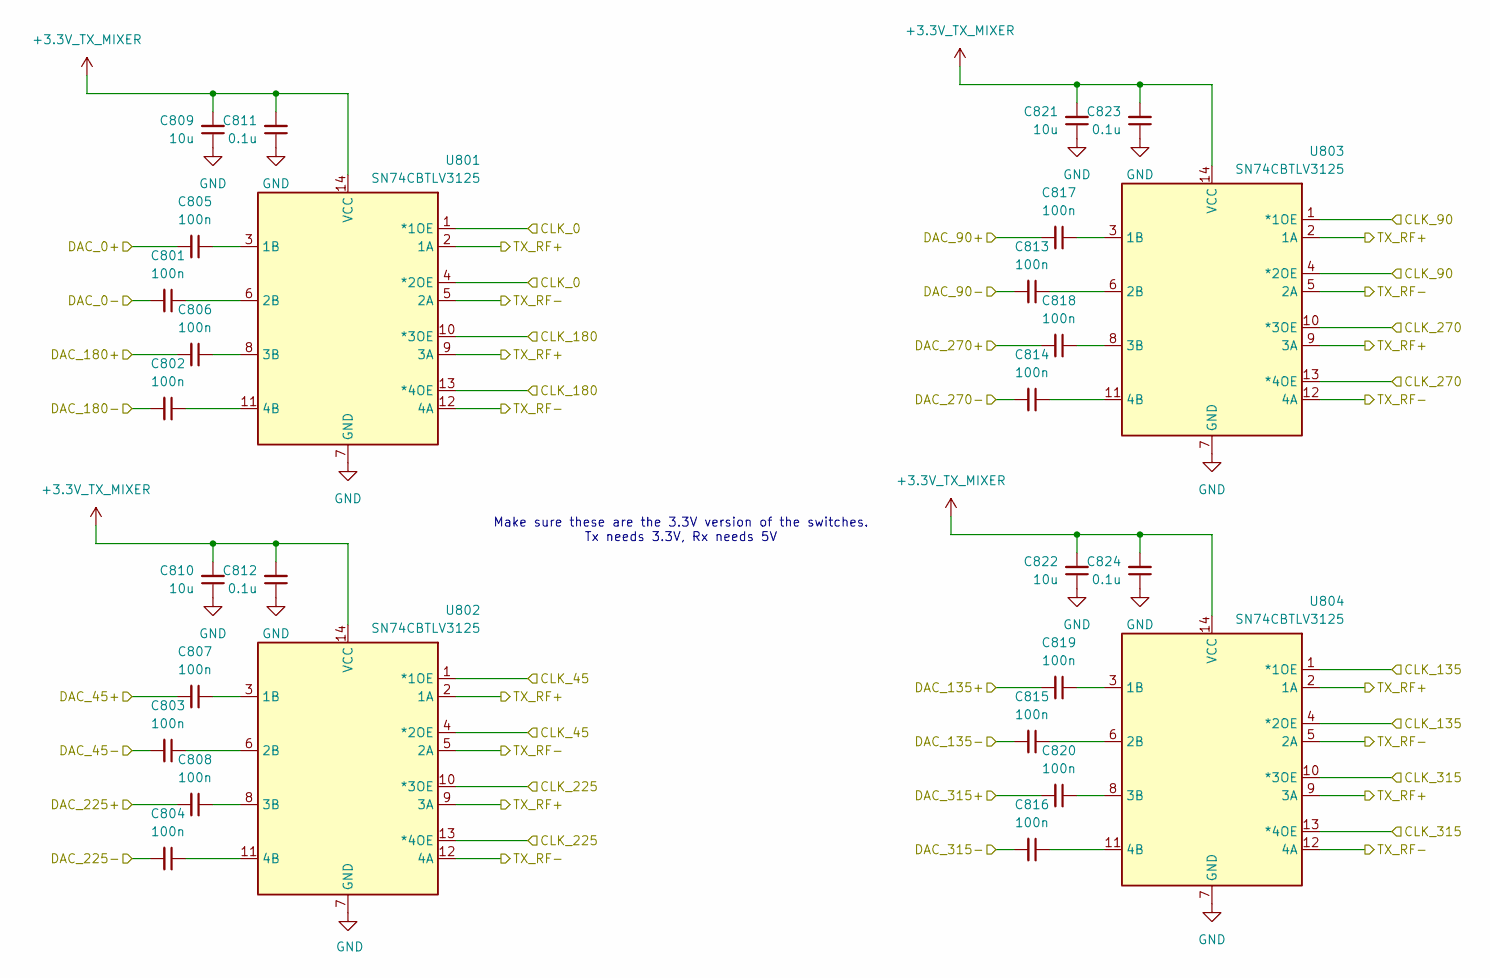
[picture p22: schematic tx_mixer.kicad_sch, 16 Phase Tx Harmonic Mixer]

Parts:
C801, C802, C803, C804, C805, C806, C807, C808, C813, C814, C815, C816, C817, C818, C819, C820: 100n; C_0402_1005Metric_Pad0.74x0.62mm_HandSolder
C809, C810, C821, C822: 10u; C_0402_1005Metric_Pad0.74x0.62mm_HandSolder; Digikey Part # 587-3258-1-ND
C811, C812, C823, C824: 0.1u; C_0402_1005Metric_Pad0.74x0.62mm_HandSolder; Digikey Part # 490-GCM31C5C1H104FA16LCT-ND
U801, U802, U803, U804: SN74CBTLV3125; TSSOP-14-1EP_4.4x5mm_P0.65mm

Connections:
+3.3V_TX_MIXER: C809.2, C810.2, C811.2, C812.2, C821.2, C822.2, C823.2, C824.2, U801.14 (VCC), U802.14 (VCC), U803.14 (VCC), U804.14 (VCC); also elsewhere on the board
/Clock_Tree/tx_phase_0: U801.1 (*1OE), U801.4 (*2OE); also elsewhere on the board
/Clock_Tree/tx_phase_45: U802.1 (*1OE), U802.4 (*2OE); also elsewhere on the board
/Clock_Tree/tx_phase_90: U803.1 (*1OE), U803.4 (*2OE); also elsewhere on the board
/Clock_Tree/tx_phase_135: U801.10 (*3OE), U801.13 (*4OE); also elsewhere on the board
/Clock_Tree/tx_phase_180: U804.1 (*1OE), U804.4 (*2OE); also elsewhere on the board
/Clock_Tree/tx_phase_225: U802.10 (*3OE), U802.13 (*4OE); also elsewhere on the board
/Clock_Tree/tx_phase_270: U803.10 (*3OE), U803.13 (*4OE); also elsewhere on the board
/Clock_Tree/tx_phase_315: U804.10 (*3OE), U804.13 (*4OE); also elsewhere on the board
/DACs/DAC_P0+: C801.2, C805.2; also elsewhere on the board
/DACs/DAC_P45+: C807.2; also elsewhere on the board
/DACs/DAC_P45-: C803.2; also elsewhere on the board
/DACs/DAC_P90+: C813.2, C817.2; also elsewhere on the board
/DACs/DAC_P135+: C819.2; also elsewhere on the board
/DACs/DAC_P135-: C815.2; also elsewhere on the board
/DACs/DAC_P180+: C802.2, C806.2; also elsewhere on the board
/DACs/DAC_P225+: C808.2; also elsewhere on the board
/DACs/DAC_P225-: C804.2; also elsewhere on the board
/DACs/DAC_P270+: C814.2, C818.2; also elsewhere on the board
/DACs/DAC_P315+: C820.2; also elsewhere on the board
/DACs/DAC_P315-: C816.2; also elsewhere on the board
/Tx_mixer/TX_RF+: U801.2 (1A), U801.9 (3A), U802.2 (1A), U802.9 (3A), U803.2 (1A), U803.9 (3A), U804.2 (1A), U804.9 (3A); also elsewhere on the board
/Tx_mixer/TX_RF-: U801.5 (2A), U801.12 (4A), U802.5 (2A), U802.12 (4A), U803.5 (2A), U803.12 (4A), U804.5 (2A), U804.12 (4A); also elsewhere on the board
unnamed: C805.1, U801.3 (1B)
unnamed: C801.1, U801.6 (2B)
unnamed: C806.1, U801.8 (3B)
unnamed: C802.1, U801.11 (4B)
unnamed: C807.1, U802.3 (1B)
unnamed: C803.1, U802.6 (2B)
unnamed: C808.1, U802.8 (3B)
unnamed: C804.1, U802.11 (4B)
unnamed: C817.1, U803.3 (1B)
unnamed: C813.1, U803.6 (2B)
unnamed: C818.1, U803.8 (3B)
unnamed: C814.1, U803.11 (4B)
unnamed: C819.1, U804.3 (1B)
unnamed: C815.1, U804.6 (2B)
unnamed: C820.1, U804.8 (3B)
unnamed: C816.1, U804.11 (4B)

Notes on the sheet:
Make sure these are the 3.3V version of the switches. Tx needs 3.3V, Rx needs 5V

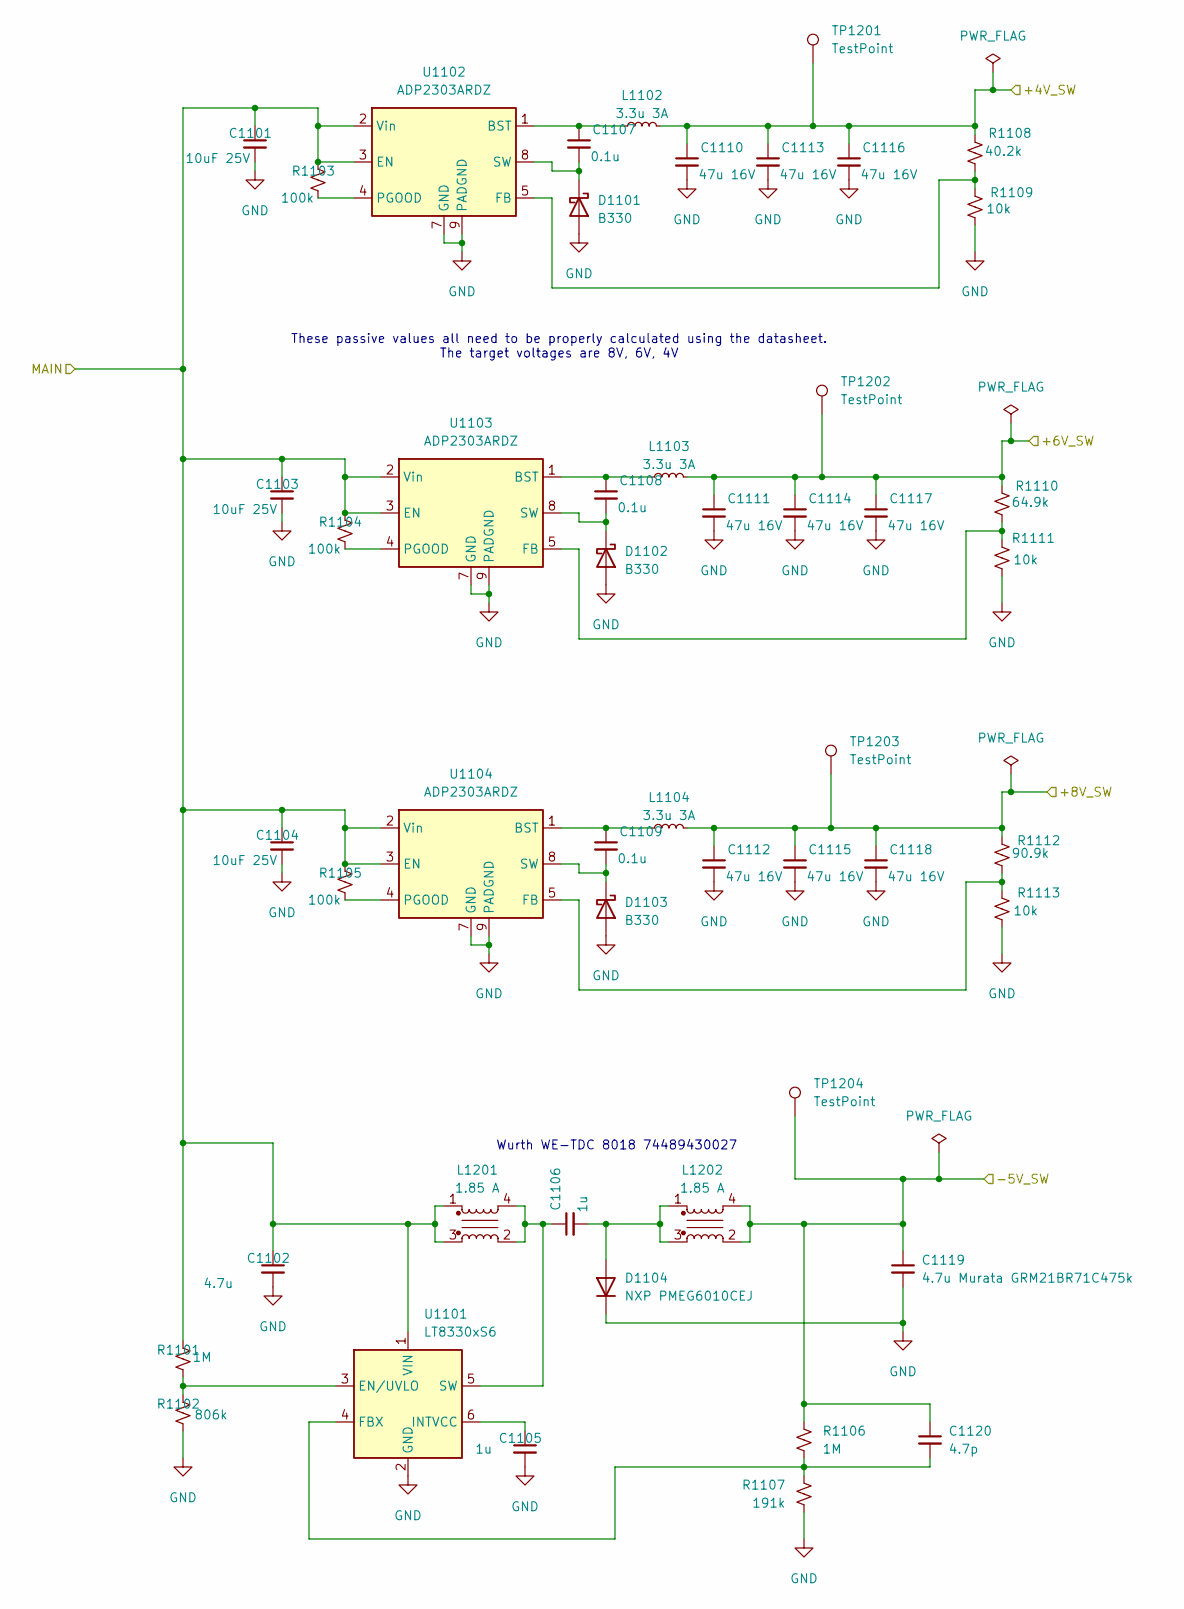
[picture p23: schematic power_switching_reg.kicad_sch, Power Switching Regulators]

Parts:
C1101, C1103, C1104: 10uF 25V; C_0402_1005Metric_Pad0.74x0.62mm_HandSolder
C1102: 4.7u; C_0402_1005Metric_Pad0.74x0.62mm_HandSolder
C1105, C1106: 1u; C_0402_1005Metric_Pad0.74x0.62mm_HandSolder
C1107, C1108, C1109: 0.1u; C_0402_1005Metric_Pad0.74x0.62mm_HandSolder
C1110, C1111, C1112, C1113, C1114, C1115, C1116, C1117, C1118: 47u 16V; C_0402_1005Metric_Pad0.74x0.62mm_HandSolder
C1119: 4.7u Murata GRM21BR71C475k; C_0402_1005Metric_Pad0.74x0.62mm_HandSolder
C1120: 4.7p; C_0402_1005Metric_Pad0.74x0.62mm_HandSolder
D1101, D1102, D1103: B330; D_SMC
D1104: NXP PMEG6010CEJ; SMA_Amphenol_901-143_Horizontal
L1102, L1103, L1104: 3.3u 3A; L_Abracon_ASPI-0630LR
L1201, L1202: 8018_74489430027; L_Wurth_WE-TDC-8018; Part Number 74489430027
R1101, R1106: 1M; R_0402_1005Metric_Pad0.72x0.64mm_HandSolder
R1102: 806k; R_0402_1005Metric_Pad0.72x0.64mm_HandSolder
R1103, R1104, R1105: 100k; R_0402_1005Metric_Pad0.72x0.64mm_HandSolder
R1107: 191k; R_0402_1005Metric_Pad0.72x0.64mm_HandSolder
R1108: 40.2k; R_0402_1005Metric_Pad0.72x0.64mm_HandSolder
R1109, R1111, R1113: 10k; R_0402_1005Metric_Pad0.72x0.64mm_HandSolder
R1110: 64.9k; R_0402_1005Metric_Pad0.72x0.64mm_HandSolder
R1112: 90.9k; R_0402_1005Metric_Pad0.72x0.64mm_HandSolder
TP1201, TP1202, TP1203, TP1204: TestPoint; PinHeader_1x01_P1.27mm_Vertical
U1101: LT8330xS6; TSOT-23-6
U1102, U1103, U1104: ADP2303ARDZ; SOIC-8-1EP_3.9x4.9mm_P1.27mm_EP2.29x3mm

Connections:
/6_-_16V: C1101.1, C1102.1, C1103.1, C1104.1, L1201.1, L1201.3, R1101.1, R1103.1, R1104.1, R1105.1, U1101.1 (VIN), U1102.2 (Vin), U1102.3 (EN), U1103.2 (Vin), U1103.3 (EN), U1104.2 (Vin), U1104.3 (EN); also elsewhere on the board
/+4V: C1110.1, C1113.1, C1116.1, L1102.2, R1108.1, TP1201.1 (1_1); also elsewhere on the board
/+6V: C1111.1, C1114.1, C1117.1, L1103.2, R1110.1, TP1202.1 (1_1); also elsewhere on the board
/+8V: C1112.1, C1115.1, C1118.1, L1104.2, R1112.1, TP1203.1 (1_1); also elsewhere on the board
/-5V: C1119.1, C1120.1, L1202.2, L1202.4, R1106.1, TP1204.1 (1_1); also elsewhere on the board
unnamed: C1107.2, D1101.1 (K), U1102.8 (SW)
unnamed: C1108.2, D1102.1 (K), U1103.8 (SW)
unnamed: C1109.2, D1103.1 (K), U1104.8 (SW)
unnamed: C1106.2, D1104.2 (A), L1202.1, L1202.3
unnamed: R1101.2, R1102.1, U1101.3 (EN/UVLO)
unnamed: C1120.2, R1106.2, R1107.1, U1101.4 (FBX)
unnamed: C1105.1, U1101.6 (INTVCC)
unnamed 418: C1106.1, L1201.2, L1201.4, U1101.5 (SW); also elsewhere on the board
unnamed: C1107.1, L1102.1, U1102.1 (BST)
unnamed: R1108.2, R1109.1, U1102.5 (FB)
unnamed: R1103.2, U1102.4 (PGOOD)
unnamed: C1108.1, L1103.1, U1103.1 (BST)
unnamed: R1110.2, R1111.1, U1103.5 (FB)
unnamed: R1104.2, U1103.4 (PGOOD)
unnamed: C1109.1, L1104.1, U1104.1 (BST)
unnamed: R1112.2, R1113.1, U1104.5 (FB)
unnamed: R1105.2, U1104.4 (PGOOD)

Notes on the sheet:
Wurth WE-TDC 8018 74489430027
These passive values all need to be properly calculated using the datasheet. The target voltages are 8V, 6V, 4V

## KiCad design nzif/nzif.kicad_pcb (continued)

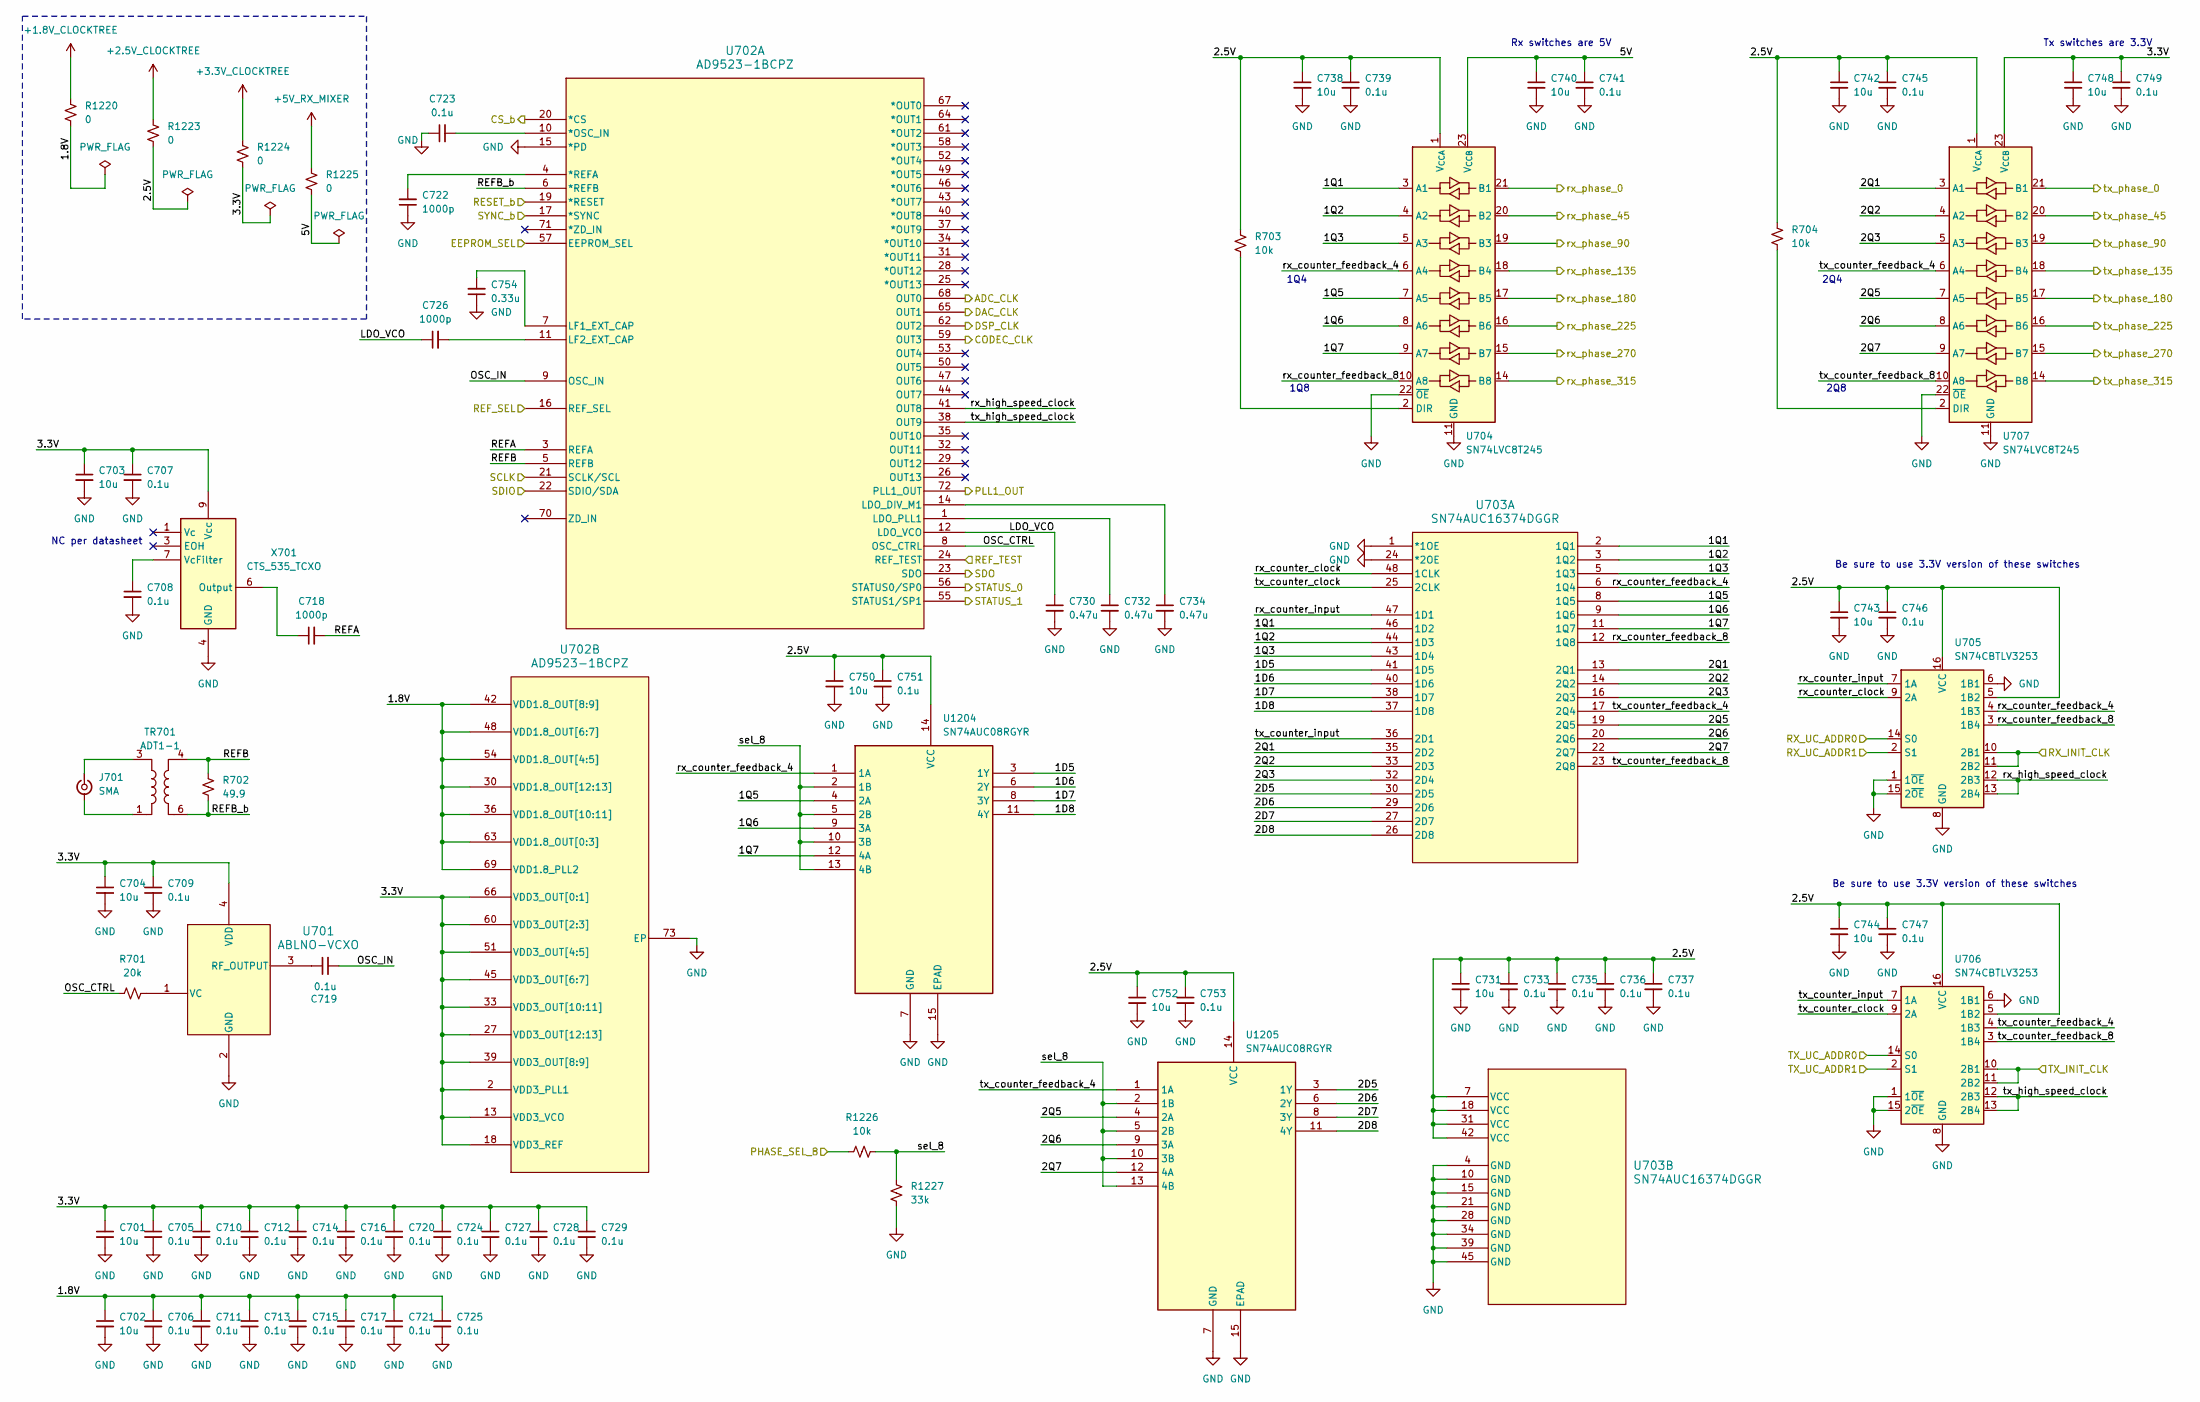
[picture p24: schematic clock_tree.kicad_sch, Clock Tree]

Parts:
C701, C702, C703, C704, C731, C738, C740, C742, C743, C744, C748, C750, C752: 10u; C_0402_1005Metric_Pad0.74x0.62mm_HandSolder
C705, C706, C707, C708, C709, C710, C711, C712, C713, C714, C715, C716, C717, C719, C720, C721, C723, C724, C725, C727, C728, C729, C733, C735, C736, C737, C739, C741, C745, C746, C747, C749, C751, C753: 0.1u; C_0402_1005Metric_Pad0.74x0.62mm_HandSolder
C718, C722, C726: 1000p; C_0402_1005Metric_Pad0.74x0.62mm_HandSolder
C730, C732, C734: 0.47u; C_0402_1005Metric_Pad0.74x0.62mm_HandSolder
C754: 0.33u; C_0402_1005Metric_Pad0.74x0.62mm_HandSolder
J701: SMA; SMA_Amphenol_901-143_Horizontal
R701: 20k; R_0402_1005Metric_Pad0.72x0.64mm_HandSolder
R702: 49.9; R_0402_1005Metric_Pad0.72x0.64mm_HandSolder
R703, R704, R1226: 10k; R_0402_1005Metric_Pad0.72x0.64mm_HandSolder
R1220, R1223, R1224, R1225: 0; R_0402_1005Metric_Pad0.72x0.64mm_HandSolder
R1227: 33k; R_0402_1005Metric_Pad0.72x0.64mm_HandSolder
TR701: ADT1-1; Mini-Circuits_CD542_H2.84mm
U701: ABLNO-VCXO; ABLNO_ABR
U702: AD9523-1BCPZ; CP-72-7_ADI
U703: SN74AUC16374DGGR; DGG48
U704, U707: SN74LVC8T245; TSSOP-24_6.1x7.8mm_P0.65mm
U705, U706: SN74CBTLV3253; TSSOP-16_4.4x5mm_P0.65mm
U1204, U1205: SN74AUC08RGYR; RGY14_2P05X2P05
X701: CTS_535_TCXO

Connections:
+1.8V_CLOCKTREE: R1220.1; also elsewhere on the board
+2.5V_CLOCKTREE: R1223.1; also elsewhere on the board
+3.3V_CLOCKTREE: R1224.1; also elsewhere on the board
/ADC_CLK: U702.68 (OUT0); also elsewhere on the board
/CLK_EEPROM_SEL: U702.57 (EEPROM_SEL); also elsewhere on the board
/CLK_REF_SEL: U702.16 (REF_SEL); also elsewhere on the board
/CLK_REF_TEST: U702.24 (REF_TEST); also elsewhere on the board
/CLK_RESET_b: U702.19 (*RESET); also elsewhere on the board
/CLK_SYNC_b: U702.17 (*SYNC); also elsewhere on the board
/CODEC_CLK: U702.59 (OUT3); also elsewhere on the board
/Clock_Tree/1.8V: C702.1, C706.1, C711.1, C713.1, C715.1, C717.1, C721.1, C725.1, R1220.2, U702.30 (VDD1.8_OUT[12:13]), U702.36 (VDD1.8_OUT[10:11]), U702.42 (VDD1.8_OUT[8:9]), U702.48 (VDD1.8_OUT[6:7]), U702.54 (VDD1.8_OUT[4:5]), U702.63 (VDD1.8_OUT[0:3]), U702.69 (VDD1.8_PLL2)
/Clock_Tree/1D5: U703.41 (1D5), U1204.3 (1Y)
/Clock_Tree/1D6: U703.40 (1D6), U1204.6 (2Y)
/Clock_Tree/1D7: U703.38 (1D7), U1204.8 (3Y)
/Clock_Tree/1D8: U703.37 (1D8), U1204.11 (4Y)
/Clock_Tree/1Q1: U703.2 (1Q1), U703.46 (1D2), U704.3 (A1)
/Clock_Tree/1Q2: U703.3 (1Q2), U703.44 (1D3), U704.4 (A2)
/Clock_Tree/1Q3: U703.5 (1Q3), U703.43 (1D4), U704.5 (A3)
/Clock_Tree/1Q5: U703.8 (1Q5), U704.7 (A5), U1204.4 (2A)
/Clock_Tree/1Q6: U703.9 (1Q6), U704.8 (A6), U1204.9 (3A)
/Clock_Tree/1Q7: U703.11 (1Q7), U704.9 (A7), U1204.12 (4A)
/Clock_Tree/2.5V: C731.1, C733.1, C735.1, C736.1, C737.1, C738.1, C739.1, C742.1, C743.1, C744.1, C745.1, C746.1, C747.1, C750.1, C751.1, C752.1, C753.1, R703.1, R704.1, R1223.2, U703.7 (VCC), U703.18 (VCC), U703.31 (VCC), U703.42 (VCC), U704.1 (V_{CCA}), U705.5 (1B2), U705.16 (VCC), U706.5 (1B2), U706.16 (VCC), U707.1 (V_{CCA}), U1204.14 (VCC), U1205.14 (VCC)
/Clock_Tree/2D5: U703.30 (2D5), U1205.3 (1Y)
/Clock_Tree/2D6: U703.29 (2D6), U1205.6 (2Y)
/Clock_Tree/2D7: U703.27 (2D7), U1205.8 (3Y)
/Clock_Tree/2D8: U703.26 (2D8), U1205.11 (4Y)
/Clock_Tree/2Q1: U703.13 (2Q1), U703.35 (2D2), U707.3 (A1)
/Clock_Tree/2Q2: U703.14 (2Q2), U703.33 (2D3), U707.4 (A2)
/Clock_Tree/2Q3: U703.16 (2Q3), U703.32 (2D4), U707.5 (A3)
/Clock_Tree/2Q5: U703.19 (2Q5), U707.7 (A5), U1205.4 (2A)
/Clock_Tree/2Q6: U703.20 (2Q6), U707.8 (A6), U1205.9 (3A)
/Clock_Tree/2Q7: U703.22 (2Q7), U707.9 (A7), U1205.12 (4A)
/Clock_Tree/3.3V: C701.1, C703.1, C704.1, C705.1, C707.1, C709.1, C710.1, C712.1, C714.1, C716.1, C720.1, C724.1, C727.1, C728.1, C729.1, C748.1, C749.1, R1224.2, U701.4 (VDD), U702.2 (VDD3_PLL1), U702.13 (VDD3_VCO), U702.18 (VDD3_REF), U702.27 (VDD3_OUT[12:13]), U702.33 (VDD3_OUT[10:11]), U702.39 (VDD3_OUT[8:9]), U702.45 (VDD3_OUT[6:7]), U702.51 (VDD3_OUT[4:5]), U702.60 (VDD3_OUT[2:3]), U702.66 (VDD3_OUT[0:1]), U707.23 (V_{CCB}), U707.24 (V_{CCB}), X701.9 (Vcc)
/Clock_Tree/5V: C740.1, C741.1, R1225.2, U704.23 (V_{CCB}), U704.24 (V_{CCB})
/Clock_Tree/LDO_VCO: C726.1, C730.1, U702.12 (LDO_VCO)
/Clock_Tree/OSC_CTRL: R701.1, U702.8 (OSC_CTRL)
/Clock_Tree/OSC_IN: C719.2, U702.9 (OSC_IN)
/Clock_Tree/PLL1_OUT: U702.72 (PLL1_OUT); also elsewhere on the board
/Clock_Tree/REFA: C718.2, U702.3 (REFA)
/Clock_Tree/REFB: R702.1, TR701.4, U702.5 (REFB)
/Clock_Tree/REFB_b: R702.2, TR701.6, U702.6 (*REFB)
/Clock_Tree/STATUS_0: U702.56 (STATUS0/SP0); also elsewhere on the board
/Clock_Tree/STATUS_1: U702.55 (STATUS1/SP1); also elsewhere on the board
/Clock_Tree/rx_counter_clock: U703.48 (1CLK), U705.9 (2A)
/Clock_Tree/rx_counter_feedback_4: U703.6 (1Q4), U704.6 (A4), U705.4 (1B3), U1204.1 (1A)
/Clock_Tree/rx_counter_feedback_8: U703.12 (1Q8), U704.10 (A8), U705.3 (1B4)
/Clock_Tree/rx_counter_input: U703.47 (1D1), U705.7 (1A)
/Clock_Tree/rx_high_speed_clock: U702.41 (OUT8), U705.12 (2B3), U705.13 (2B4)
/Clock_Tree/rx_phase_0: U704.21 (B1); also elsewhere on the board
/Clock_Tree/rx_phase_45: U704.20 (B2); also elsewhere on the board
/Clock_Tree/rx_phase_90: U704.19 (B3); also elsewhere on the board
/Clock_Tree/rx_phase_135: U704.18 (B4); also elsewhere on the board
/Clock_Tree/rx_phase_180: U704.17 (B5); also elsewhere on the board
/Clock_Tree/rx_phase_225: U704.16 (B6); also elsewhere on the board
/Clock_Tree/rx_phase_270: U704.15 (B7); also elsewhere on the board
/Clock_Tree/rx_phase_315: U704.14 (B8); also elsewhere on the board
/Clock_Tree/sel_8: R1226.2, R1227.1, U1204.2 (1B), U1204.5 (2B), U1204.10 (3B), U1204.13 (4B), U1205.2 (1B), U1205.5 (2B), U1205.10 (3B), U1205.13 (4B)
/Clock_Tree/tx_counter_clock: U703.25 (2CLK), U706.9 (2A)
/Clock_Tree/tx_counter_feedback_4: U703.17 (2Q4), U706.4 (1B3), U707.6 (A4), U1205.1 (1A)
/Clock_Tree/tx_counter_feedback_8: U703.23 (2Q8), U706.3 (1B4), U707.10 (A8)
/Clock_Tree/tx_counter_input: U703.36 (2D1), U706.7 (1A)
/Clock_Tree/tx_high_speed_clock: U702.38 (OUT9), U706.12 (2B3), U706.13 (2B4)
/Clock_Tree/tx_phase_0: U707.21 (B1); also elsewhere on the board
/Clock_Tree/tx_phase_45: U707.20 (B2); also elsewhere on the board
/Clock_Tree/tx_phase_90: U707.19 (B3); also elsewhere on the board
/Clock_Tree/tx_phase_135: U707.18 (B4); also elsewhere on the board
/Clock_Tree/tx_phase_180: U707.17 (B5); also elsewhere on the board
/Clock_Tree/tx_phase_225: U707.16 (B6); also elsewhere on the board
/Clock_Tree/tx_phase_270: U707.15 (B7); also elsewhere on the board
/Clock_Tree/tx_phase_315: U707.14 (B8); also elsewhere on the board
/DAC_CLK: U702.65 (OUT1); also elsewhere on the board
/DSP_CLK: U702.62 (OUT2); also elsewhere on the board
/PHASE_SEL_8: R1226.1; also elsewhere on the board
/RX_CLK_ADDR0: U705.14 (S0); also elsewhere on the board
/RX_CLK_ADDR1: U705.2 (S1); also elsewhere on the board
/RX_INIT_CLK: U705.10 (2B1), U705.11 (2B2); also elsewhere on the board
/SPI0_RX: U702.23 (SDO); also elsewhere on the board
/SPI0_SC0: U702.20 (*CS); also elsewhere on the board
/SPI0_TX: U702.22 (SDIO/SDA); also elsewhere on the board
/SPIO_SCLK: U702.21 (SCLK/SCL); also elsewhere on the board
/TX_CLK_ADDR0: U706.14 (S0); also elsewhere on the board
/TX_CLK_ADDR1: U706.2 (S1); also elsewhere on the board
/TX_INIT_CLK: U706.10 (2B1), U706.11 (2B2); also elsewhere on the board
unnamed: J701.2 (Ext), TR701.1
unnamed: J701.1 (In), TR701.3
unnamed: C719.1, U701.3 (RF_OUTPUT)
unnamed: R701.2, U701.1 (VC)
unnamed: C723.2, U702.10 (*OSC_IN)
unnamed: C722.2, U702.4 (*REFA)
unnamed: C734.1, U702.14 (LDO_DIV_M1)
unnamed: C732.1, U702.1 (LDO_PLL1)
unnamed: C754.2, U702.7 (LF1_EXT_CAP)
unnamed: C726.2, U702.11 (LF2_EXT_CAP)
unnamed: R703.2, U704.2 (DIR)
unnamed: R704.2, U707.2 (DIR)
unnamed: C718.1, X701.6 (Output)
unnamed: C708.1, X701.7 (VcFilter)

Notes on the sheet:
Rx switches are 5V
Be sure to use 3.3V version of these switches
1Q4
Tx switches are 3.3V
1Q8
2Q4
NC per datasheet
2Q8

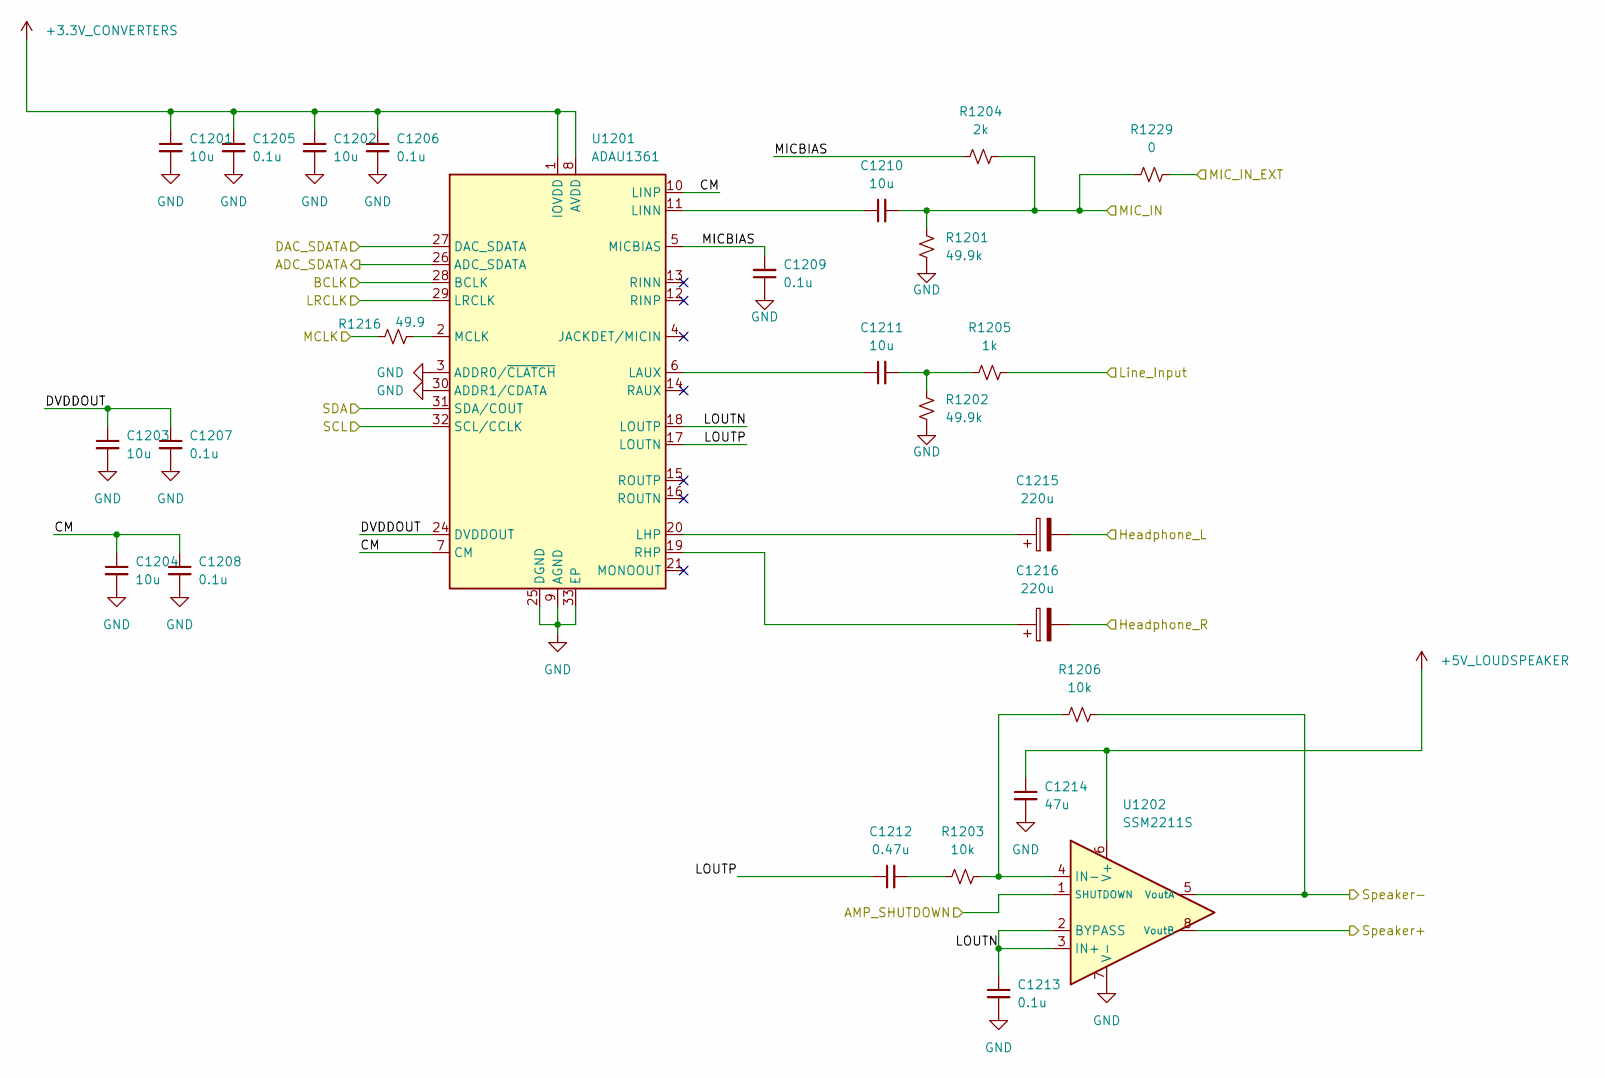
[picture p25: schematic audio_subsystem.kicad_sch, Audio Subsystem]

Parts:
C1201, C1202, C1203, C1204, C1210, C1211: 10u; C_0402_1005Metric_Pad0.74x0.62mm_HandSolder
C1205, C1206, C1207, C1208, C1209, C1213: 0.1u; C_0402_1005Metric_Pad0.74x0.62mm_HandSolder
C1212: 0.47u; C_0402_1005Metric_Pad0.74x0.62mm_HandSolder
C1214: 47u; C_0402_1005Metric_Pad0.74x0.62mm_HandSolder
C1215, C1216: 220u; CP_Elec_6.3x7.7; Digikey Part # UWT1C221MCL1GS
R1201, R1202: 49.9k; R_0402_1005Metric_Pad0.72x0.64mm_HandSolder
R1203, R1206: 10k; R_0402_1005Metric_Pad0.72x0.64mm_HandSolder
R1204: 2k; R_0402_1005Metric_Pad0.72x0.64mm_HandSolder
R1205: 1k; R_0402_1005Metric_Pad0.72x0.64mm_HandSolder
R1216: 49.9; R_0402_1005Metric_Pad0.72x0.64mm_HandSolder
R1229: 0; R_0402_1005Metric_Pad0.72x0.64mm_HandSolder
U1201: ADAU1361; LFCSP-32-1EP_5x5mm_P0.5mm_EP3.5x3.5mm_ThermalVias
U1202: SSM2211S; SOIC-8_3.9x4.9mm_P1.27mm

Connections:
+3.3V_CONVERTERS: C1201.1, C1202.1, C1205.1, C1206.1, U1201.1 (IOVDD), U1201.8 (AVDD), U1201.23 (AVDD); also elsewhere on the board
+5V_LOUDSPEAKER: C1214.1, U1202.6 (V+); also elsewhere on the board
/AMP_SHUTDOWN: U1202.1 (SHUTDOWN); also elsewhere on the board
/Audio_Subsystem/ADC_SDATA: U1201.26 (ADC_SDATA); also elsewhere on the board
/Audio_Subsystem/BCLK: U1201.28 (BCLK); also elsewhere on the board
/Audio_Subsystem/CM: C1204.1, C1208.1, U1201.7 (CM), U1201.10 (LINP)
/Audio_Subsystem/DAC_SDATA: U1201.27 (DAC_SDATA); also elsewhere on the board
/Audio_Subsystem/DVDDOUT: C1203.1, C1207.1, U1201.24 (DVDDOUT)
/Audio_Subsystem/Headphone_L: C1215.2; also elsewhere on the board
/Audio_Subsystem/Headphone_R: C1216.2; also elsewhere on the board
/Audio_Subsystem/LOUTN: C1213.1, U1201.18 (LOUTP), U1202.2 (BYPASS), U1202.3 (IN+)
/Audio_Subsystem/LOUTP: C1212.1, U1201.17 (LOUTN)
/Audio_Subsystem/LRCLK: U1201.29 (LRCLK); also elsewhere on the board
/Audio_Subsystem/Line_Input: R1205.2; also elsewhere on the board
/Audio_Subsystem/MICBIAS: C1209.2, R1204.1, U1201.5 (MICBIAS)
/Audio_Subsystem/MIC_IN: C1210.2, R1201.1, R1204.2, R1229.1; also elsewhere on the board
/Audio_Subsystem/MIC_IN_EXT: R1229.2; also elsewhere on the board
/Audio_Subsystem/Speaker+: U1202.8 (VoutB); also elsewhere on the board
/Audio_Subsystem/Speaker-: R1206.2, U1202.5 (VoutA); also elsewhere on the board
/CODEC_CLK: R1216.1; also elsewhere on the board
/SCL0: U1201.32 (SCL/CCLK); also elsewhere on the board
/SDA0: U1201.31 (SDA/COUT); also elsewhere on the board
unnamed: C1211.2, R1202.1, R1205.1
unnamed: C1212.2, R1203.1
unnamed: C1211.1, U1201.6 (LAUX)
unnamed: C1215.1, U1201.20 (LHP)
unnamed: C1210.1, U1201.11 (LINN)
unnamed: R1216.2, U1201.2 (MCLK)
unnamed: C1216.1, U1201.19 (RHP)
unnamed: R1203.2, R1206.1, U1202.4 (IN-)

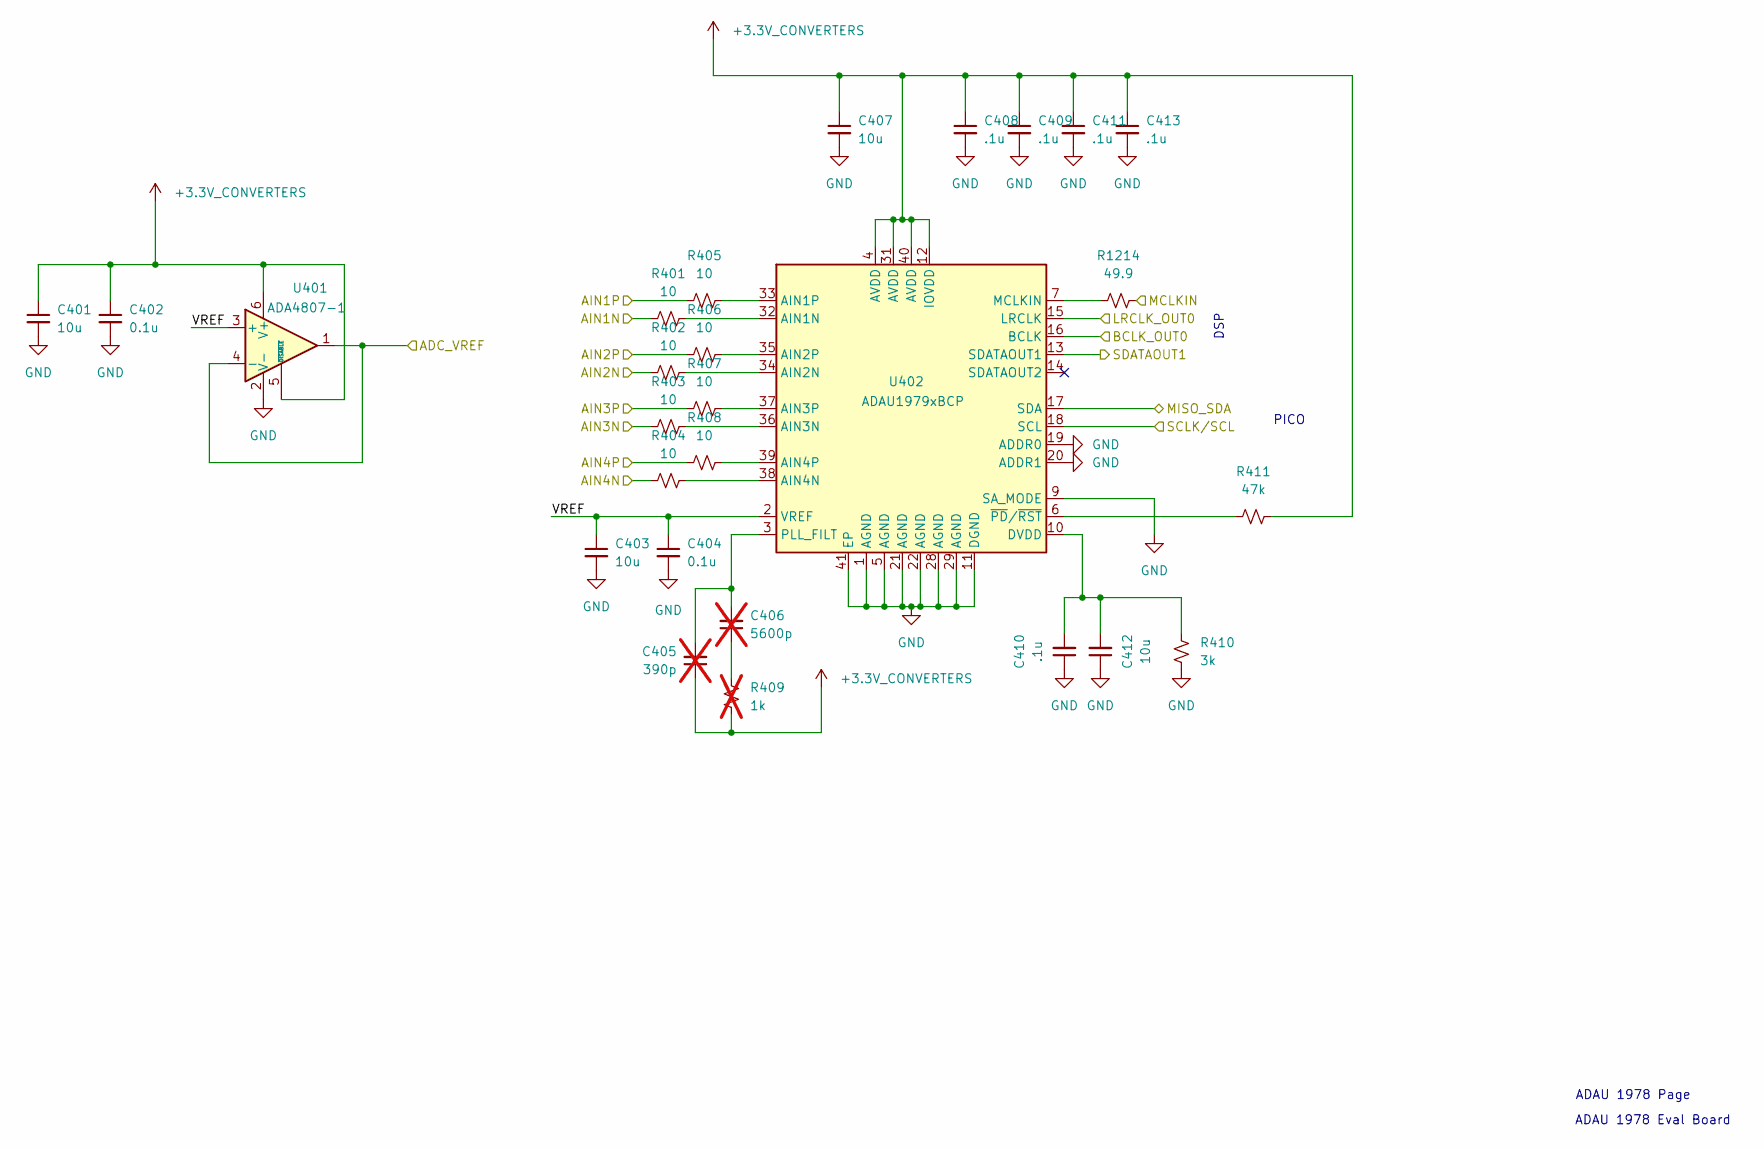
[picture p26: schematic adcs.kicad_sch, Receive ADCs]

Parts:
C401, C403: 10u; C_0402_1005Metric_Pad0.74x0.62mm_HandSolder; Digikey Part # 587-3258-1-ND
C402, C404: 0.1u; C_0402_1005Metric_Pad0.74x0.62mm_HandSolder; Digikey Part # 490-GCM31C5C1H104FA16LCT-ND
C405: 390p; C_0402_1005Metric_Pad0.74x0.62mm_HandSolder; not fitted
C406: 5600p; C_0402_1005Metric_Pad0.74x0.62mm_HandSolder; not fitted
C407, C412: 10u; C_0402_1005Metric_Pad0.74x0.62mm_HandSolder
C408, C409, C410, C411, C413: .1u; C_0402_1005Metric_Pad0.74x0.62mm_HandSolder
R401, R402, R403, R404, R405, R406, R407, R408: 10; R_0402_1005Metric_Pad0.72x0.64mm_HandSolder
R409: 1k; R_0402_1005Metric_Pad0.72x0.64mm_HandSolder; not fitted
R410: 3k; R_0402_1005Metric_Pad0.72x0.64mm_HandSolder
R411: 47k; R_0402_1005Metric_Pad0.72x0.64mm_HandSolder
R1214: 49.9; R_0402_1005Metric_Pad0.72x0.64mm_HandSolder
U401: ADA4807-1; SOT-23-6
U402: ADAU1979xBCP; LFCSP-40-1EP_6x6mm_P0.5mm_EP3.9x3.9mm

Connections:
+3.3V_CONVERTERS: C401.1, C402.1, C405.1, C407.1, C408.1, C409.1, C411.1, C413.1, R409.1, R411.2, U401.5 (~DISABLE), U401.6 (V+), U402.4 (AVDD), U402.12 (IOVDD), U402.31 (AVDD), U402.40 (AVDD); also elsewhere on the board
/ADC_CLK: R1214.2; also elsewhere on the board
/ADCs/ADC_VREF: U401.1, U401.4 (-); also elsewhere on the board
/ADCs/AIN1N: R401.1; also elsewhere on the board
/ADCs/AIN1P: R405.1; also elsewhere on the board
/ADCs/AIN2N: R402.1; also elsewhere on the board
/ADCs/AIN2P: R406.1; also elsewhere on the board
/ADCs/AIN3N: R403.1; also elsewhere on the board
/ADCs/AIN3P: R407.1; also elsewhere on the board
/ADCs/AIN4N: R404.1; also elsewhere on the board
/ADCs/AIN4P: R408.1; also elsewhere on the board
/ADCs/BCLK_OUT0: U402.16 (BCLK); also elsewhere on the board
/ADCs/LRCLK_OUT0: U402.15 (LRCLK); also elsewhere on the board
/ADCs/SDATAOUT1: U402.13 (SDATAOUT1); also elsewhere on the board
/ADCs/VREF: C403.1, C404.1, U401.3 (+), U402.2 (VREF)
/SCL0: U402.18 (SCL); also elsewhere on the board
/SDA0: U402.17 (SDA); also elsewhere on the board
unnamed: C406.1, R409.2
unnamed: R401.2, U402.32 (AIN1N)
unnamed: R405.2, U402.33 (AIN1P)
unnamed: R402.2, U402.34 (AIN2N)
unnamed: R406.2, U402.35 (AIN2P)
unnamed: R403.2, U402.36 (AIN3N)
unnamed: R407.2, U402.37 (AIN3P)
unnamed: R404.2, U402.38 (AIN4N)
unnamed: R408.2, U402.39 (AIN4P)
unnamed: C410.2, C412.2, R410.2, U402.10 (DVDD)
unnamed: R1214.1, U402.7 (MCLKIN)
unnamed: C405.2, C406.2, U402.3 (PLL_FILT)
unnamed: R411.1, U402.6 (~PD/~RST)

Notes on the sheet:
ADAU 1978 Page
ADAU 1978 Eval Board
PICO
DSP

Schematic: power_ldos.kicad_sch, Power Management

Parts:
C901, C902, C903, C911, C912, C919, C920, C921: 4.7u; C_0402_1005Metric_Pad0.74x0.62mm_HandSolder
C904, C905, C906, C910, C913, C914, C915, C922, C923, C924, C929: 0.47u; C_0402_1005Metric_Pad0.74x0.62mm_HandSolder
C907, C908, C909, C916, C917, C918, C925, C926, C927, C930, C931: 10u; C_0402_1005Metric_Pad0.74x0.62mm_HandSolder
C928: 10u; C_0402_1005Metric_Pad0.74x0.62mm_HandSolder; Digikey Part # 587-3258-1-ND
R901, R903, R905, R906, R907, R908: 49.9k; R_0402_1005Metric_Pad0.72x0.64mm_HandSolder
R902: 33.2k; R_0402_1005Metric_Pad0.72x0.64mm_HandSolder
R904: 34.8k; R_0402_1005Metric_Pad0.72x0.64mm_HandSolder
R909: 18k; R_0402_1005Metric_Pad0.72x0.64mm_HandSolder
R910: 16.5k; R_0402_1005Metric_Pad0.72x0.64mm_HandSolder
R911, R912: 20m; R_0402_1005Metric_Pad0.72x0.64mm_HandSolder
TP1205, TP1206, TP1207, TP1208, TP1209, TP1210, TP1211, TP1212, TP1213, TP1214: TestPoint; PinHeader_1x01_P1.27mm_Vertical
U901, U902, U903, U905, U906, U907, U908, U909, U910, U911: LT3045xMSE; MSOP-12-1EP_3x4.039mm_P0.65mm_EP1.651x2.845mm
U904: LT3094EDD-PBF; DD_05-08-1725_ADI

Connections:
+1.8V_CLOCKTREE: C927.1, TP1212.1 (1_1), U909.10 (OUTS), U909.11 (OUT), U909.12 (OUT); also elsewhere on the board
+2.5V_CLOCKTREE: C925.1, TP1213.1 (1_1), U907.10 (OUTS), U907.11 (OUT), U907.12 (OUT); also elsewhere on the board
+3.3V_CLOCKTREE: C926.1, TP1208.1 (1_1), U908.10 (OUTS), U908.11 (OUT), U908.12 (OUT); also elsewhere on the board
+3.3V_CONVERTERS: C907.1, TP1206.1 (1_1), U901.10 (OUTS), U901.11 (OUT), U901.12 (OUT); also elsewhere on the board
+3.3V_DSP_UC: R911.2, R912.2, TP1214.1 (1_1); also elsewhere on the board
+3.3V_TX_MIXER: C916.1, TP1209.1 (1_1), U905.10 (OUTS), U905.11 (OUT), U905.12 (OUT); also elsewhere on the board
+5V_LOUDSPEAKER: C917.1, TP1210.1 (1_1), U906.10 (OUTS), U906.11 (OUT), U906.12 (OUT); also elsewhere on the board
+6.5V_RX_OPAMPS: C909.1, TP1207.1 (1_1), U903.10 (OUTS), U903.11 (OUT), U903.12 (OUT); also elsewhere on the board
-3.5V_RX_OPAMPS: C918.1, TP1211.1 (1_1), U904.10 (OUTS), U904.11 (OUT), U904.12 (OUT); also elsewhere on the board
/+4V: C901.1, C919.1, C920.1, C921.1, C928.1, U901.1 (IN), U901.2 (IN), U901.3 (IN), U901.4 (EN/UV), U901.7 (PGFB), U907.1 (IN), U907.2 (IN), U907.3 (IN), U907.4 (EN/UV), U907.7 (PGFB), U908.1 (IN), U908.2 (IN), U908.3 (IN), U908.4 (EN/UV), U908.7 (PGFB), U909.1 (IN), U909.2 (IN), U909.3 (IN), U909.4 (EN/UV), U909.7 (PGFB), U910.1 (IN), U910.2 (IN), U910.3 (IN), U910.4 (EN/UV), U910.7 (PGFB), U911.1 (IN), U911.2 (IN), U911.3 (IN), U911.4 (EN/UV), U911.7 (PGFB); also elsewhere on the board
/+6V: C902.1, C911.1, C912.1, U902.1 (IN), U902.2 (IN), U902.3 (IN), U902.4 (EN/UV), U902.7 (PGFB), U905.1 (IN), U905.2 (IN), U905.3 (IN), U905.4 (EN/UV), U905.7 (PGFB), U906.1 (IN), U906.2 (IN), U906.3 (IN), U906.4 (EN/UV), U906.7 (PGFB); also elsewhere on the board
/+8V: C903.1, U903.1 (IN), U903.2 (IN), U903.3 (IN), U903.4 (EN/UV), U903.7 (PGFB); also elsewhere on the board
/-5V: C913.1, U904.1 (IN), U904.2 (IN), U904.3 (EN/UV), U904.5 (PGFB), U904.13 (IN); also elsewhere on the board
unnamed: C905.1, R902.1, U901.8 (SET)
unnamed: C904.1, R901.1, U902.8 (SET)
unnamed: C906.1, R903.1, U903.8 (SET)
unnamed: C910.1, R904.1, U904.8 (SET)
unnamed: C914.1, R905.1, U905.8 (SET)
unnamed: C915.1, R906.1, U906.8 (SET)
unnamed: C922.1, R907.1, U907.8 (SET)
unnamed: C923.1, R908.1, U908.8 (SET)
unnamed: C924.1, R909.1, U909.8 (SET)
unnamed: C930.1, R911.1, U910.10 (OUTS), U910.11 (OUT), U910.12 (OUT)
unnamed: C929.1, R910.1, U910.8 (SET), U911.8 (SET)
unnamed: C931.1, R912.1, U911.10 (OUTS), U911.11 (OUT), U911.12 (OUT)

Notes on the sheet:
3.3V Power for ADCs/DACs/Codec
3.3V Power for DSP and uC
Resistor sets 3.3V output Use high quality cap such as COG
3.3V Power for Tx Switches
2.5V Power for Clock Tree
6.5V Power for RX op amps
Resistor sets 2.5V output Use high quality cap such as COG
Resistor sets 1.8V output Use high quality cap such as COG
checked rset resistor
Resistor sets 5V output Use high quality cap such as COG
Resistor sets 6.5V output Use high quality cap such as COG
1.8V Power for Clock Tree
5V Power for Loudspeaker
3.3V Power for VFO
5V Power for RX Mixer Switches
-3.5V Power for RX op amps

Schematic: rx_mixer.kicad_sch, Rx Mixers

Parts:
C201, C202, C205, C206: 10u; C_0402_1005Metric_Pad0.74x0.62mm_HandSolder; Digikey Part # 587-3258-1-ND
C203, C204, C207, C208: 0.1u; C_0402_1005Metric_Pad0.74x0.62mm_HandSolder; Digikey Part # 490-GCM31C5C1H104FA16LCT-ND
HC_201, HC_202, HC_203, HC_204, HC_205, HC_206, HC_207, HC_208: 2n; C_1206_3216Metric_Pad1.33x1.80mm_HandSolder; Digikey Part # 490-GCM31C5C1H104FA16LCT-ND
U201, U202, U205, U208: ADA4625-2; SOIC-8-1EP_3.9x4.9mm_P1.27mm_EP2.29x3mm; Digikey Part # 505-ADA4625-2ARDZ-R7CT-ND
U203, U204, U206, U207: SN74CBT3125C; TSSOP-14-1EP_4.4x5mm_P0.65mm; Digikey Part # 296-SN74CBT3125CPWRTR-ND

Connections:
+6.5V_RX_OPAMPS: U201.8 (V+), U202.8 (V+), U205.8 (V+), U208.8 (V+); also elsewhere on the board
-3.5V_RX_OPAMPS: U201.4 (V-), U201.9 (EP), U202.4 (V-), U202.9 (EP), U205.4 (V-), U205.9 (EP), U208.4 (V-), U208.9 (EP); also elsewhere on the board
/Clock_Tree/rx_phase_0: U203.1 (*1OE), U206.4 (*2OE); also elsewhere on the board
/Clock_Tree/rx_phase_45: U204.1 (*1OE), U206.13 (*4OE); also elsewhere on the board
/Clock_Tree/rx_phase_90: U203.10 (*3OE), U207.4 (*2OE); also elsewhere on the board
/Clock_Tree/rx_phase_135: U204.10 (*3OE), U207.13 (*4OE); also elsewhere on the board
/Clock_Tree/rx_phase_180: U203.4 (*2OE), U206.1 (*1OE); also elsewhere on the board
/Clock_Tree/rx_phase_225: U204.4 (*2OE), U206.10 (*3OE); also elsewhere on the board
/Clock_Tree/rx_phase_270: U203.13 (*4OE), U207.1 (*1OE); also elsewhere on the board
/Clock_Tree/rx_phase_315: U204.13 (*4OE), U207.10 (*3OE); also elsewhere on the board
/RX_Driver_Amps/P0_IN+: U201.1, U201.2 (-); also elsewhere on the board
/RX_Driver_Amps/P0_IN-: U201.6 (-), U201.7; also elsewhere on the board
/RX_Driver_Amps/P45_IN+: U205.1, U205.2 (-); also elsewhere on the board
/RX_Driver_Amps/P45_IN-: U205.6 (-), U205.7; also elsewhere on the board
/RX_Driver_Amps/P90_IN+: U202.1, U202.2 (-); also elsewhere on the board
/RX_Driver_Amps/P90_IN-: U202.6 (-), U202.7; also elsewhere on the board
/RX_Driver_Amps/P135_IN+: U208.1, U208.2 (-); also elsewhere on the board
/RX_Driver_Amps/P135_IN-: U208.6 (-), U208.7; also elsewhere on the board
/Rx_mixer/Baseband_0: HC_201.1, U201.3 (+), U203.3 (1B), U203.6 (2B)
/Rx_mixer/Baseband_45: HC_203.1, U204.3 (1B), U204.6 (2B), U205.3 (+)
/Rx_mixer/Baseband_90: HC_202.1, U202.3 (+), U203.8 (3B), U203.11 (4B)
/Rx_mixer/Baseband_135: HC_204.1, U204.8 (3B), U204.11 (4B), U208.3 (+)
/Rx_mixer/Baseband_180: HC_205.1, U201.5 (+), U206.3 (1B), U206.6 (2B)
/Rx_mixer/Baseband_225: HC_206.1, U205.5 (+), U206.8 (3B), U206.11 (4B)
/Rx_mixer/Baseband_270: HC_207.1, U202.5 (+), U207.3 (1B), U207.6 (2B)
/Rx_mixer/Baseband_315: HC_208.1, U207.8 (3B), U207.11 (4B), U208.5 (+)
/Rx_mixer/RF+: U203.2 (1A), U203.9 (3A), U204.2 (1A), U204.9 (3A), U206.2 (1A), U206.9 (3A), U207.2 (1A), U207.9 (3A); also elsewhere on the board
/Rx_mixer/RF-: U203.5 (2A), U203.12 (4A), U204.5 (2A), U204.12 (4A), U206.5 (2A), U206.12 (4A), U207.5 (2A), U207.12 (4A); also elsewhere on the board

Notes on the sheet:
Rx Math (1:1 Impedance Ratio): Rsource =50Ω Rswitch = close to zero Rtotal =50Ω N=1 Effective R for bandwidth: N x R = 50 ohm BW = 1 / (2* pi * N * Reff * C) For 96 kHz BW: C= 1 / (2 * pi * 4 * 85 * 96000)  = 33nF

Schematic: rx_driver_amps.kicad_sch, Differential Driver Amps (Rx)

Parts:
C301, C302, C305, C306, C311, C312, C323, C324, C327, C330, C333, C336: 10u; C_0402_1005Metric_Pad0.74x0.62mm_HandSolder; Digikey Part # 587-3258-1-ND
C303, C304, C307, C308, C309, C310, C313, C314, C315, C316, C317, C318, C325, C326, C328, C329, C331, C332, C334, C335, C337, C338, C339, C342: 0.1u; C_0402_1005Metric_Pad0.74x0.62mm_HandSolder; Digikey Part # 490-GCM31C5C1H104FA16LCT-ND
C319, C320, C321, C322, C340, C341, C343, C344: 180p; C_0402_1005Metric_Pad0.74x0.62mm_HandSolder; Digikey Part # 490-GCM31C5C1H104FA16LCT-ND; not fitted
R301, R303, R315, R319: 3.4k; R_0402_1005Metric_Pad0.72x0.64mm_HandSolder; Digikey Part # 311-3.40KHRCT-ND
R302, R304, R312, R314, R316, R320, R326, R328: 9.53k; R_0402_1005Metric_Pad0.72x0.64mm_HandSolder; Digikey Part # 311-9.53KHRCT-ND
R305, R306, R311, R313, R321, R324, R325, R327: 10k; R_0402_1005Metric_Pad0.72x0.64mm_HandSolder; Digikey Part # 311-10.0KHRCT-ND
R307, R308, R309, R310, R317, R318, R322, R323: 1k; R_0402_1005Metric_Pad0.72x0.64mm_HandSolder; Digikey Part # 311-1.00KHRCT-ND
U301, U302, U307, U308: LT5400BCMS8E-8-TRPBF; MSOP-8_MS_LIT; Digikey Part # LT5400BCMS8E-1#PBF-ND
U303, U305, U311, U312: ADA4945-1; LFCSP16_ADA4945-1ACPZ-R2_ADI
U304, U306, U309, U310: ADG884xCP; LFCSP-WD-10-1EP_3x3mm_P0.5mm_EP1.64x2.38mm; Digikey Part # 505-ADG884BRMZ-ND

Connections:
+3.3V_DSP_UC: C301.1, C302.1, C303.1, C304.1, C323.1, C324.1, C325.1, C326.1, U304.1 (VDD), U306.1 (VDD), U309.1 (VDD), U310.1 (VDD); also elsewhere on the board
+6.5V_RX_OPAMPS: C305.1, C306.1, C307.1, C308.1, C309.1, C310.1, C327.1, C328.1, C329.1, C330.1, C331.1, C332.1, R301.1, R303.1, R305.2, R306.2, R315.1, R319.1, R321.2, R324.2, U303.5 (MODE), U303.6 (+VS), U303.7 (+VS), U305.5 (MODE), U305.6 (+VS), U305.7 (+VS), U311.5 (MODE), U311.6 (+VS), U311.7 (+VS), U312.5 (MODE), U312.6 (+VS), U312.7 (+VS); also elsewhere on the board
-3.5V_RX_OPAMPS: C311.1, C312.1, C314.1, C316.1, C317.1, C318.1, C333.1, C335.1, C336.1, C337.1, C339.1, C342.1, R311.1, R313.1, R325.1, R327.1, U303.14 (-VS), U303.15 (-VS), U303.17 (EPAD), U305.14 (-VS), U305.15 (-VS), U305.17 (EPAD), U311.14 (-VS), U311.15 (-VS), U311.17 (EPAD), U312.14 (-VS), U312.15 (-VS), U312.17 (EPAD); also elsewhere on the board
/ADCs/ADC_VREF: C313.1, C315.1, C334.1, C338.1, U303.9 (VOCM), U305.9 (VOCM), U311.9 (VOCM), U312.9 (VOCM); also elsewhere on the board
/ADCs/AIN1N: U303.10 (+OUT); also elsewhere on the board
/ADCs/AIN1P: U303.11 (-OUT); also elsewhere on the board
/ADCs/AIN2N: U305.10 (+OUT); also elsewhere on the board
/ADCs/AIN2P: U305.11 (-OUT); also elsewhere on the board
/ADCs/AIN3N: U312.10 (+OUT); also elsewhere on the board
/ADCs/AIN3P: U312.11 (-OUT); also elsewhere on the board
/ADCs/AIN4N: U311.10 (+OUT); also elsewhere on the board
/ADCs/AIN4P: U311.11 (-OUT); also elsewhere on the board
/FDA_GAIN_SEL: U304.4 (IN1), U304.8 (IN2), U306.4 (IN1), U306.8 (IN2), U309.4 (IN1), U309.8 (IN2), U310.4 (IN1), U310.8 (IN2); also elsewhere on the board
/RX_Driver_Amps/+VCLAMP: R301.2, R302.1, R303.2, R304.1, R315.2, R316.1, R319.2, R320.1, U303.8 (+VCLAMP), U305.8 (+VCLAMP), U311.8 (+VCLAMP), U312.8 (+VCLAMP)
/RX_Driver_Amps/-VCLAMP: R311.2, R312.1, R313.2, R314.1, R325.2, R326.1, R327.2, R328.1, U303.13 (-VCLAMP), U305.13 (-VCLAMP), U311.13 (-VCLAMP), U312.13 (-VCLAMP)
/RX_Driver_Amps/LT5400_p1: U301.1 (R1), U302.1 (R1), U304.10 (S2A), U306.10 (S2A), U307.1 (R1), U308.1 (R1), U309.10 (S2A), U310.10 (S2A)
/RX_Driver_Amps/LT5400_p4: U301.4 (R4), U302.4 (R4), U304.5 (S1B), U306.5 (S1B), U307.4 (R4), U308.4 (R4), U309.5 (S1B), U310.5 (S1B)
/RX_Driver_Amps/P0_FB+: C320.1, U303.4 (+FB), U304.9 (D2)
/RX_Driver_Amps/P0_FB-: C319.1, U303.1 (-FB), U304.3 (D1)
/RX_Driver_Amps/P0_IN+: C319.2, R307.1, U301.3 (R3), U301.5 (R4), U301.6 (R3), U303.2 (+IN); also elsewhere on the board
/RX_Driver_Amps/P0_IN-: C320.2, R308.1, R318.1, U301.2 (R2), U301.7 (R2), U301.8 (R1), U303.3 (-IN); also elsewhere on the board
/RX_Driver_Amps/P1_FB+: C322.1, U305.4 (+FB), U306.9 (D2)
/RX_Driver_Amps/P1_FB-: C321.1, U305.1 (-FB), U306.3 (D1)
/RX_Driver_Amps/P1_IN+: C321.2, R309.1, U302.5 (R4), U302.6 (R3), U305.2 (+IN)
/RX_Driver_Amps/P1_IN-: C322.2, R310.1, U302.7 (R2), U302.8 (R1), U305.3 (-IN)
/RX_Driver_Amps/P2_FB+: C344.1, U310.9 (D2), U312.4 (+FB)
/RX_Driver_Amps/P2_FB-: C343.1, U310.3 (D1), U312.1 (-FB)
/RX_Driver_Amps/P2_IN+: C343.2, R322.1, U308.5 (R4), U308.6 (R3), U312.2 (+IN)
/RX_Driver_Amps/P2_IN-: C344.2, R323.1, U308.7 (R2), U308.8 (R1), U312.3 (-IN)
/RX_Driver_Amps/P3_FB+: C341.1, U309.9 (D2), U311.4 (+FB)
/RX_Driver_Amps/P3_FB-: C340.1, U309.3 (D1), U311.1 (-FB)
/RX_Driver_Amps/P3_IN+: C340.2, R317.1, U307.5 (R4), U307.6 (R3), U311.2 (+IN)
/RX_Driver_Amps/P3_IN-: C341.2, U307.7 (R2), U307.8 (R1), U311.3 (-IN)
/RX_Driver_Amps/P45_IN+: U302.3 (R3); also elsewhere on the board
/RX_Driver_Amps/P45_IN-: U302.2 (R2); also elsewhere on the board
/RX_Driver_Amps/P90_IN+: U308.3 (R3); also elsewhere on the board
/RX_Driver_Amps/P90_IN-: U308.2 (R2); also elsewhere on the board
/RX_Driver_Amps/P135_IN+: U307.3 (R3); also elsewhere on the board
/RX_Driver_Amps/P135_IN-: U307.2 (R2); also elsewhere on the board
unnamed: R305.1, U303.12 (~DISABLE)
unnamed: R307.2, U304.2 (S1A)
unnamed: R308.2, U304.7 (S2B)
unnamed: R306.1, U305.12 (~DISABLE)
unnamed: R309.2, U306.2 (S1A)
unnamed: R310.2, U306.7 (S2B)
unnamed: R317.2, U309.2 (S1A)
unnamed: R318.2, U309.7 (S2B)
unnamed: R322.2, U310.2 (S1A)
unnamed: R323.2, U310.7 (S2B)
unnamed: R321.1, U311.12 (~DISABLE)
unnamed: R324.1, U312.12 (~DISABLE)

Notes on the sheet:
Set to -1.7V
+VCLAMP set to 4.79V
Set to 4.79V
-VCLAMP set to -1.7V
Feedback resistors LP filter with Rin

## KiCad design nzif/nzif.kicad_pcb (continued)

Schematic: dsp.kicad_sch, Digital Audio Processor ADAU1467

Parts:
C501, C502, C518, C519: 10u; C_0402_1005Metric_Pad0.74x0.62mm_HandSolder
C503, C504, C505, C506, C507, C508, C509, C510, C511, C522, C523: 10n; C_0402_1005Metric_Pad0.74x0.62mm_HandSolder
C512, C514, C515, C516, C517, C520, C521, C524, C526, C527, C528, C529: 0.1u; C_0402_1005Metric_Pad0.74x0.62mm_HandSolder
C513, C525: .1u; C_0402_1005Metric_Pad0.74x0.62mm_HandSolder
C530: 150p; C_0402_1005Metric_Pad0.74x0.62mm_HandSolder
C531: 5.6n; C_0402_1005Metric_Pad0.74x0.62mm_HandSolder
D501: LED; LED_1206_3216Metric_ReverseMount_Hole1.8x2.4mm
Q501: STD2805T4; DPAKTO-252_TYPEA_STM
R501, R502, R503: 10k; R_0402_1005Metric_Pad0.72x0.64mm_HandSolder
R504: 100k; R_0402_1005Metric_Pad0.72x0.64mm_HandSolder
R505, R506: 1k; R_0402_1005Metric_Pad0.72x0.64mm_HandSolder
R507: 4.32k; R_0402_1005Metric_Pad0.72x0.64mm_HandSolder
R508, R509, R510, R511, R512, R513, R514, R515, R516, R517, R518, R519, R520, R521, R522, R523: 33; R_0402_1005Metric_Pad0.72x0.64mm_HandSolder
R1215: 49.9; R_0402_1005Metric_Pad0.72x0.64mm_HandSolder
SW501: SW_SPST; SW_DIP_SPSTx01_Slide_6.7x4.1mm_W6.73mm_P2.54mm_LowProfile_J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
SW502: SW_Push; SW_PUSH_6mm
TP501: VDrive; PinHeader_1x01_P1.27mm_Vertical
TP502: IOVDD; PinHeader_1x01_P1.27mm_Vertical
TP503: DVDD; PinHeader_1x01_P1.27mm_Vertical
U501: ADAU1467WBCPZ300; CP_88_10_ADI
U502: 25AA1024-I/MF; DIP-8_W7.62mm_Socket
U503: ADM811TARTZ-REEL7; RA_4_ADI

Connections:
+3.3V_DSP_UC: C501.2, C503.2, C505.2, C507.2, C509.2, C511.2, C513.1, C514.2, C516.2, C518.2, C519.2, C520.2, C522.2, C523.2, C524.2, C525.2, C526.2, C527.2, C528.2, C529.2, C530.2, C531.1, Q501.3 (Emitter), R502.1, R503.1, R506.2, SW501.2 (B), TP502.1 (1_1), U501.2 (IOVDD), U501.9 (AVDD), U501.19 (PVDD), U501.22 (IOVDD), U501.37 (IOVDD), U501.46 (IOVDD), U501.68 (IOVDD), U502.7 (*HOLD), U502.8 (VCC), U503.4 (VCC); also elsewhere on the board
/ADCs/BCLK_OUT0: R514.1; also elsewhere on the board
/ADCs/LRCLK_OUT0: R513.1; also elsewhere on the board
/ADCs/SDATAOUT1: R508.2; also elsewhere on the board
/Audio_Subsystem/ADC_SDATA: R509.2; also elsewhere on the board
/Audio_Subsystem/BCLK: R520.1; also elsewhere on the board
/Audio_Subsystem/DAC_SDATA: R518.1; also elsewhere on the board
/Audio_Subsystem/LRCLK: R519.1; also elsewhere on the board
/DACs/DAC_BCLK: R517.1; also elsewhere on the board
/DACs/DAC_LRCLK: R516.1; also elsewhere on the board
/DACs/TDM1_SDIN_DAC: R515.1; also elsewhere on the board
/DSP/CW_TONE: U501.10 (AUXADC0); also elsewhere on the board
/DSP/DSP_AUX4: U501.14 (AUXADC4); also elsewhere on the board
/DSP/DSP_AUX5: U501.15 (AUXADC5); also elsewhere on the board
/DSP/DSP_AUX6: U501.16 (AUXADC6); also elsewhere on the board
/DSP/DSP_AUX7: U501.17 (AUXADC7); also elsewhere on the board
/DSP/DVDD: C502.2, C504.2, C506.2, C508.2, C510.2, C512.2, C515.2, C517.2, C521.2, Q501.2 (Collector), TP503.1 (1_1), U501.24 (DVDD), U501.43 (DVDD), U501.65 (DVDD), U501.87 (DVDD)
/DSP/MISO_M: U501.35 (SDA_M/MISO_M/MP3), U502.2 (SO)
/DSP/MOSI_M: U501.33 (MOSI_M/MP1), U502.5 (SI)
/DSP/PLL_FILT: C530.1, R507.2, U501.20 (PLLFILT)
/DSP/SCLK_M: U501.34 (SCL_M/SCLK_M/MP2), U502.6 (SCK)
/DSP/SELFBOOT: D501.1 (K), R501.1, U501.42 (SELFBOOT)
/DSP/SS_M: R502.2, U501.32 (SS_M/MP0), U502.1 (*CS)
/DSP/VAD_ATT: U501.11 (AUXADC1); also elsewhere on the board
/DSP/VAD_LPF: U501.13 (AUXADC3); also elsewhere on the board
/DSP/VAD_REL: U501.12 (AUXADC2); also elsewhere on the board
/DSP/VDrive: Q501.1 (Base), R506.1, TP501.1 (1_1), U501.3 (VDRIVE)
/DSP/~RESET: R504.1, U501.28 (~RESET), U503.2 (RESET*)
/DSP_CLK: R1215.1; also elsewhere on the board
/DSP_MP06: U501.53 (MP6); also elsewhere on the board
/DSP_MP07: U501.54 (MP7); also elsewhere on the board
/DSP_MP10: U501.74 (LRCLK_IN0/MP10); also elsewhere on the board
/DSP_MP11: U501.77 (LRCLK_IN1/MP11); also elsewhere on the board
/DSP_MP12: U501.82 (LRCLK_IN2/MP12); also elsewhere on the board
/DSP_MP14: U501.6 (MP14); also elsewhere on the board
/DSP_MP15: U501.7 (MP15); also elsewhere on the board
/DSP_MP16: U501.72 (SDATAIO0/MP16); also elsewhere on the board
/DSP_MP17: U501.71 (SDATAIO1/MP17); also elsewhere on the board
/DSP_MP18: U501.70 (SDATAIO2/MP18); also elsewhere on the board
/DSP_MP19: U501.69 (SDATAIO3/MP19); also elsewhere on the board
/DSP_MP20: U501.64 (SDATAIO4/MP20); also elsewhere on the board
/DSP_MP21: U501.63 (SDATAIO5/MP21); also elsewhere on the board
/DSP_MP22: U501.62 (SDATAIO6/MP22); also elsewhere on the board
/DSP_MP23: U501.61 (SDATAIO7/MP23); also elsewhere on the board
/DSP_MP24: U501.30 (SCL2_M/MP24); also elsewhere on the board
/DSP_MP25: U501.31 (SDA2_M/MP25); also elsewhere on the board
/SCL0: U501.38 (MISO/SDA); also elsewhere on the board
/SDA0: U501.39 (SCLK/SCL); also elsewhere on the board
/TDM3_BCLK_OUT_HEAD: R523.1; also elsewhere on the board
/TDM3_LRCLK_IN_HEAD: R511.2; also elsewhere on the board
/TDM3_LRCLK_OUT_HEAD: R522.1; also elsewhere on the board
/TDM3_SDATA_IN_HEAD: R510.2; also elsewhere on the board
/TDM3_SDATA_OUT_HEAD: R521.1; also elsewhere on the board
/TDM3_SDOUT_IN_HEAD: R512.2; also elsewhere on the board
/USB_~RESET: R505.2
unnamed: C531.2, R507.1
unnamed: D501.2 (A), SW501.1 (A)
unnamed: R512.1, U501.84 (BCLK_IN3)
unnamed: R514.2, U501.48 (BCLK_OUT0)
unnamed: R517.2, U501.51 (BCLK_OUT1)
unnamed: R520.2, U501.56 (BCLK_OUT2)
unnamed: R522.2, U501.59 (BCLK_OUT3)
unnamed: R511.1, U501.85 (LRCLK_IN3/MP13)
unnamed: R513.2, U501.47 (LRCLK_OUT0/MP4)
unnamed: R516.2, U501.50 (LRCLK_OUT1/MP5)
unnamed: R519.2, U501.55 (LRCLK_OUT2/MP8)
unnamed: R523.2, U501.58 (LRCLK_OUT3/MP9)
unnamed: R508.1, U501.75 (SDATA_IN0)
unnamed: R509.1, U501.83 (SDATA_IN2)
unnamed: R510.1, U501.86 (SDATA_IN3)
unnamed: R515.2, U501.52 (SDATA_OUT1)
unnamed: R518.2, U501.57 (SDATA_OUT2)
unnamed: R521.2, U501.60 (SDATA_OUT3)
unnamed: R1215.2, U501.25 (XTALIN/MCLK)
unnamed: R503.2, U502.3 (*WP)
unnamed: R505.1, SW502.1, U503.3 (MR*)

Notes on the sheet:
PLL Loop Filter
TDM Port 1 DAC
Aux pins to header on top sheet
DVDD Regulator Circuit
TDM port 3 goes to header on top sheet
TDM Port 2 Audio Subsystem
Reset Circuit
ADAU 1467 Eval Board
ADAU1467
TDM Port 3 Header
All MP/GIPO go to header on top sheet
Selfboot Circuit
TDM Port 0 ADC
Eval board used FSM6JSMA for the switch. SMD. maybe switch to that. Also do we need USB_RESET (diode)> Did not include SDP Reset

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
Board: 2 copper layers, 621 parts (0 on the bottom side), 438 nets, no tracks yet.

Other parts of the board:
AE1201, AE1202: Antenna; SMA_Amphenol_901-143_Horizontal
C101: 47u; C_0402_1005Metric_Pad0.74x0.62mm_HandSolder
C103: 0.1u; C_0402_1005Metric_Pad0.74x0.62mm_HandSolder
D1201, D1202, D1203, D1204, D1205, D1206: LED; LED_1206_3216Metric_ReverseMount_Hole1.8x2.4mm
J1204, J1205, J1206: AUX; PinHeader_1x08_P1.27mm_Vertical
J1207: GPIOS; PinHeader_2x12_P1.27mm_Vertical
J1208: SKR; PinHeader_1x02_P1.27mm_Vertical
J1209: TRRS; PinHeader_1x04_P1.27mm_Vertical
J1210, J1211: TS; PinHeader_1x02_P1.27mm_Vertical
J1212: TDM3_IN; PinHeader_1x05_P1.27mm_Vertical
J1213: TDM3_OUT; PinHeader_1x05_P1.27mm_Vertical
J1214: DAC MONITOR; PinHeader_2x04_P1.27mm_Vertical
J1215: I2C; PinHeader_2x05_P1.27mm_Vertical
J1216: STATUS; PinHeader_2x02_P1.27mm_Vertical
J1217: PWR_SW; PinHeader_2x05_P1.27mm_Vertical
J1218: TEST_POINTS; PinHeader_1x14_P1.27mm_Vertical
J1219: Front Panel; PinHeader_2x20_P1.27mm_Vertical
J1220: UART; PinHeader_2x05_P1.27mm_Vertical
J1221: PLL1_OUT; PinHeader_1x01_P1.27mm_Vertical
L1101: 2.7u Wurth WE-TDC 8018 74489430027; TerminalBlock_MaiXu_MX126-5.0-02P_1x02_P5.00mm
R105, R106: 33; R_0402_1005Metric_Pad0.72x0.64mm_HandSolder
R107, R1207, R1208, R1209, R1210, R1211, R1228: 1k; R_0402_1005Metric_Pad0.72x0.64mm_HandSolder
R1217, R1218, R1221, R1222: 4.7k; R_0402_1005Metric_Pad0.72x0.64mm_HandSolder

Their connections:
+3.3V_DSP_UC: J1205.1, J1205.2, J1205.3, J1205.4, J1205.5, J1205.6, J1205.7, J1205.8, J1212.1, J1213.1, J1215.1, R107.1, R1217.1, R1218.1, R1221.1, R1222.1; also elsewhere on the board
/6_-_16V: L1101.1; also elsewhere on the board
/+4V: J1217.5; also elsewhere on the board
/+6V: J1217.3; also elsewhere on the board
/+8V: J1217.1; also elsewhere on the board
/-5V: J1217.7; also elsewhere on the board
/ADC0_FWD_PWR: J1218.12; also elsewhere on the board
/ADC1_REV_PWR: J1218.13; also elsewhere on the board
/ADC2_RSSI: J1218.14; also elsewhere on the board
/AMP_SHUTDOWN: J1219.39; also elsewhere on the board
/ANTI_NOISE: J1219.35; also elsewhere on the board
/Audio_Subsystem/Headphone_L: J1209.1; also elsewhere on the board
/Audio_Subsystem/Headphone_R: J1209.2; also elsewhere on the board
/Audio_Subsystem/Line_Input: J1211.1; also elsewhere on the board
/Audio_Subsystem/MIC_IN: J1209.3; also elsewhere on the board
/Audio_Subsystem/MIC_IN_EXT: J1210.1; also elsewhere on the board
/Audio_Subsystem/Speaker+: J1208.1; also elsewhere on the board
/Audio_Subsystem/Speaker-: J1208.2; also elsewhere on the board
/BAND_SELECT: J1219.13; also elsewhere on the board
/CLK_REF_SEL: J1218.2; also elsewhere on the board
/CLK_REF_TEST: J1218.3; also elsewhere on the board
/CLK_RESET_b: J1218.5; also elsewhere on the board
/CLK_SYNC_b: J1218.4; also elsewhere on the board
/COARSE_TUNE: J1219.17; also elsewhere on the board
/CW_BREAK_IN: J1219.27; also elsewhere on the board
/CW_KEY: J1219.25; also elsewhere on the board
/Clock_Tree/PLL1_OUT: J1221.1 (Pin_1_1); also elsewhere on the board
/Clock_Tree/STATUS_0: J1216.1; also elsewhere on the board
/Clock_Tree/STATUS_1: J1216.2; also elsewhere on the board
/DACs/DAC_MONITOR0: J1214.4; also elsewhere on the board
/DACs/DAC_MONITOR1: J1214.3; also elsewhere on the board
/DACs/DAC_MONITOR2: J1214.2; also elsewhere on the board
/DACs/DAC_MONITOR3: J1214.1; also elsewhere on the board
/DSP/CW_TONE: J1204.4; also elsewhere on the board
/DSP/DSP_AUX4: J1204.5; also elsewhere on the board
/DSP/DSP_AUX5: J1204.6; also elsewhere on the board
/DSP/DSP_AUX6: J1204.7; also elsewhere on the board
/DSP/DSP_AUX7: J1204.8; also elsewhere on the board
/DSP/VAD_ATT: J1204.1; also elsewhere on the board
/DSP/VAD_LPF: J1204.2; also elsewhere on the board
/DSP/VAD_REL: J1204.3; also elsewhere on the board
/DSP_MP06: J1207.1; also elsewhere on the board
/DSP_MP07: J1207.3; also elsewhere on the board
/DSP_MP10: J1207.5; also elsewhere on the board
/DSP_MP11: J1207.7; also elsewhere on the board
/DSP_MP12: J1207.9; also elsewhere on the board
/DSP_MP14: J1207.11; also elsewhere on the board
/DSP_MP15: J1207.13; also elsewhere on the board
/DSP_MP16: J1207.15; also elsewhere on the board
/DSP_MP17: J1207.17; also elsewhere on the board
/DSP_MP18: J1207.19; also elsewhere on the board
/DSP_MP19: J1207.21; also elsewhere on the board
/DSP_MP20: J1207.23; also elsewhere on the board
/DSP_MP21: D1202.2 (A); also elsewhere on the board
/DSP_MP22: D1201.2 (A); also elsewhere on the board
/DSP_MP23: D1205.2 (A); also elsewhere on the board
/DSP_MP24: D1204.2 (A); also elsewhere on the board
/DSP_MP25: D1203.2 (A); also elsewhere on the board
/DSP_RESET_b: J1218.6; also elsewhere on the board
/FDA_GAIN_SEL: J1219.37; also elsewhere on the board
/MIC_GAIN: J1219.31; also elsewhere on the board
/MODE_SEL: J1219.15; also elsewhere on the board
/NOTCH: J1219.29; also elsewhere on the board
/PHASE_SEL_8: J1218.11; also elsewhere on the board
/PUSH_TO_TALK: J1219.23; also elsewhere on the board
/RADIO_DIAL+: J1219.7; also elsewhere on the board
/RADIO_DIAL-: J1219.9; also elsewhere on the board
/RF_ATTENUATOR: J1219.33; also elsewhere on the board
/RIT: J1219.19; also elsewhere on the board
/RX_CLK_ADDR0: J1218.7; also elsewhere on the board
/RX_CLK_ADDR1: J1218.8; also elsewhere on the board
/SCL0: J1215.3, R105.2, R1217.2; also elsewhere on the board
/SCL1: J1215.7, R1222.2; also elsewhere on the board
/SDA0: J1215.5, R106.2, R1218.2; also elsewhere on the board
/SDA1: J1215.9, R1221.2; also elsewhere on the board
/SELECT+: J1219.1; also elsewhere on the board
/SELECT-: J1219.3; also elsewhere on the board
/SELECT_PB: J1219.5; also elsewhere on the board
/SPLIT: J1219.21; also elsewhere on the board
/SWIO_0: D1206.2 (A), J1218.1; also elsewhere on the board
/TDM3_BCLK_OUT_HEAD: J1212.2; also elsewhere on the board
/TDM3_LRCLK_IN_HEAD: J1213.2; also elsewhere on the board
/TDM3_LRCLK_OUT_HEAD: J1212.3; also elsewhere on the board
/TDM3_SDATA_IN_HEAD: J1213.3; also elsewhere on the board
/TDM3_SDATA_OUT_HEAD: J1212.4; also elsewhere on the board
/TDM3_SDOUT_IN_HEAD: J1213.4; also elsewhere on the board
/TX_CLK_ADDR0: J1218.9; also elsewhere on the board
/TX_CLK_ADDR1: J1218.10; also elsewhere on the board
/UART0_CTS: J1220.1; also elsewhere on the board
/UART0_RTS: J1220.3; also elsewhere on the board
/UART0_RX: J1220.5; also elsewhere on the board
/UART0_TX: J1220.7; also elsewhere on the board
/VOLUME: J1219.11; also elsewhere on the board
unnamed 283: AE1201.1 (A_1); also elsewhere on the board
unnamed 284: AE1202.1 (A_1); also elsewhere on the board
unnamed 310: R107.2; also elsewhere on the board
unnamed: D1201.1 (K), R1207.1
unnamed: D1202.1 (K), R1208.1
unnamed: D1203.1 (K), R1209.1
unnamed: D1204.1 (K), R1210.1
unnamed: D1205.1 (K), R1211.1
unnamed: D1206.1 (K), R1228.1
unnamed 418: L1101.2; also elsewhere on the board

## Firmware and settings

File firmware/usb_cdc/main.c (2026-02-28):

#include <ctype.h>
#include <stdio.h>
#include <stdlib.h>
#include <string.h>

#include "pico/stdlib.h"

#define CMD_BUFFER_SIZE 128

static uint64_t g_vfo_a_hz = 14070000;
static uint64_t g_vfo_b_hz = 7074000;
static bool g_active_vfo_b = false;
static bool g_tx_vfo_b = false;
static bool g_split = false;
static int g_mode = 2; // 1=LSB, 2=USB, 3=CW, 4=FM, 5=AM, 6=FSK
static bool g_ptt = false;
static int g_keyer_wpm = 20;
static int g_rf_gain = 128;
static int g_af_gain = 128;
static int g_smeter = 0; // 0-30
static int g_agc = 2; // 0=off,1=slow,2=mid,3=fast

static uint64_t current_rx_freq_hz(void) {
    return g_active_vfo_b ? g_vfo_b_hz : g_vfo_a_hz;
}

static uint64_t current_tx_freq_hz(void) {
    bool tx_vfo_b = g_split ? g_tx_vfo_b : g_active_vfo_b;
    return tx_vfo_b ? g_vfo_b_hz : g_vfo_a_hz;
}

static void cat_write(const char *response) {
    if (response) {
        printf("%s", response);
        fflush(stdout);
    }
}

static void cat_write_fa(void) {
    char reply[32];
    snprintf(reply, sizeof(reply), "FA%011llu;", (unsigned long long)g_vfo_a_hz);
    cat_write(reply);
}

static void cat_write_fb(void) {
    char reply[32];
    snprintf(reply, sizeof(reply), "FB%011llu;", (unsigned long long)g_vfo_b_hz);
    cat_write(reply);
}

static void cat_write_md(void) {
    char reply[16];
    snprintf(reply, sizeof(reply), "MD%d;", g_mode);
    cat_write(reply);
}

static void cat_write_tx(void) {
    char reply[16];
    snprintf(reply, sizeof(reply), "TX%d;", g_ptt ? 1 : 0);
    cat_write(reply);
}

static void cat_write_if(void) {
    // Kenwood-style IF response (hamlib expects 37 data chars after trimming ';').
    // IF[11]=freq [4]=step [5]=rit [5]=xit [1]=rit_on [1]=xit_on [1]=tx
    // [1]=mode [1]=vfo [1]=scan [1]=split [1]=tone [2]=reserved (+1 pad for hamlib)
    char reply[64];
    snprintf(reply, sizeof(reply), "IF%011llu%04d%05d%05d%d%d%d%d%d%d%d000;",
             (unsigned long long)current_rx_freq_hz(),
             0, 0, 0,
             0, 0,
             g_ptt ? 1 : 0,
             g_mode,
             g_active_vfo_b ? 1 : 0,
             0,
             g_split ? 1 : 0,
             0);
    cat_write(reply);
}

static void cat_write_ag(void) {
    char reply[16];
    snprintf(reply, sizeof(reply), "AG%03d;", g_af_gain);
    cat_write(reply);
}

static void cat_write_rg(void) {
    char reply[16];
    snprintf(reply, sizeof(reply), "RG%03d;", g_rf_gain);
    cat_write(reply);
}

static void cat_write_sm(void) {
    char reply[16];
    snprintf(reply, sizeof(reply), "SM%03d;", g_smeter);
    cat_write(reply);
}

static void cat_write_gt(void) {
    char reply[16];
    snprintf(reply, sizeof(reply), "GT%d;", g_agc);
    cat_write(reply);
}

static void handle_command(const char *cmd) {
    if (!cmd || strlen(cmd) < 2) {
        return;
    }

    char c0 = (char)toupper((unsigned char)cmd[0]);
    char c1 = (char)toupper((unsigned char)cmd[1]);
    const char *args = cmd + 2;

    if (c0 == 'F' && c1 == 'A') {
        if (*args) {
            uint64_t val = strtoull(args, NULL, 10);
            if (val > 0) {
                g_vfo_a_hz = val;
            }
            return;
        }
        cat_write_fa();
        return;
    }

    if (c0 == 'F' && c1 == 'B') {
        if (*args) {
            uint64_t val = strtoull(args, NULL, 10);
            if (val > 0) {
                g_vfo_b_hz = val;
            }
            return;
        }
        cat_write_fb();
        return;
    }

    if (c0 == 'M' && c1 == 'D') {
        if (*args) {
            int val = atoi(args);
            if (val > 0) {
                g_mode = val;
            }
            return;
        }
        cat_write_md();
        return;
    }

    if (c0 == 'T' && c1 == 'X') {
        if (*args) {
            g_ptt = (atoi(args) != 0);
            return;
        }
        cat_write_tx();
        return;
    }

    if (c0 == 'R' && c1 == 'X') {
        g_ptt = false;
        return;
    }

    if (c0 == 'I' && c1 == 'D') {
        cat_write("ID019;"); // Kenwood TS-2000 ID for broad compatibility
        return;
    }

    if (c0 == 'A' && c1 == 'I') {
        cat_write("AI0;");
        return;
    }

    if (c0 == 'A' && c1 == 'G') {
        if (*args) {
            int val = atoi(args);
            if (val >= 0 && val <= 255) {
                g_af_gain = val;
            }
            return;
        }
        cat_write_ag();
        return;
    }

    if (c0 == 'R' && c1 == 'G') {
        if (*args) {
            int val = atoi(args);
            if (val >= 0 && val <= 255) {
                g_rf_gain = val;
            }
            return;
        }
        cat_write_rg();
        return;
    }

    if (c0 == 'S' && c1 == 'M') {
        cat_write_sm();
        return;
    }

    if (c0 == 'G' && c1 == 'T') {
        if (*args) {
            int val = atoi(args);
            if (val >= 0 && val <= 3) {
                g_agc = val;
            }
            return;
        }
        cat_write_gt();
        return;
    }

    if (c0 == 'K' && c1 == 'S') {
        if (*args) {
            int val = atoi(args);
            if (val >= 5 && val <= 60) {
                g_keyer_wpm = val;
            }
            return;
        }
        char reply[16];
        snprintf(reply, sizeof(reply), "KS%03d;", g_keyer_wpm);
        cat_write(reply);
        return;
    }

    if (c0 == 'K' && c1 == 'Y') {
        // Accept CW text (ignored for now). Return KY0; to acknowledge.
        cat_write("KY0;");
        return;
    }

    if (c0 == 'F' && c1 == 'R') {
        if (*args) {
            g_active_vfo_b = (atoi(args) != 0);
            return;
        }
        cat_write(g_active_vfo_b ? "FR1;" : "FR0;");
        return;
    }

    if (c0 == 'F' && c1 == 'T') {
        if (*args) {
            g_tx_vfo_b = (atoi(args) != 0);
            g_split = (g_tx_vfo_b != g_active_vfo_b);
            return;
        }
        g_split = (g_tx_vfo_b != g_active_vfo_b);
        cat_write(g_tx_vfo_b ? "FT1;" : "FT0;");
        return;
    }

    if (c0 == 'I' && c1 == 'F') {
        cat_write_if();
        return;
    }

    if (c0 == 'S' && c1 == 'A') {
        // Satellite mode query: return off.
        cat_write("SA0;");
        return;
    }

    // Unknown command: ignore silently (Kenwood style).
}

int main(void) {
    stdio_init_all();

    // Give USB a moment to enumerate.
    sleep_ms(2000);

    char cmd_buffer[CMD_BUFFER_SIZE] = {0};
    size_t cmd_len = 0;

    while (true) {
        int ch = getchar_timeout_us(0);
        if (ch == PICO_ERROR_TIMEOUT) {
            tight_loop_contents();
            continue;
        }

        if (ch == '\r' || ch == '\n' || ch == ';') {
            if (cmd_len > 0) {
                cmd_buffer[cmd_len] = '\0';
                handle_command(cmd_buffer);
                cmd_len = 0;
            }
            continue;
        }

        if (cmd_len + 1 < sizeof(cmd_buffer)) {
            cmd_buffer[cmd_len++] = (char)ch;
        } else {
            cmd_len = 0; // overflow: reset
        }
    }
}

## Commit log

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2026-01-02 basic arrangement of blocks
    [adau1467.kicad_sch, adau1962a.kicad_sch, clock_tree.kicad_sch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]
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2026-01-02 updated rx mixer page
    [rx_mixers.kicad_sch]
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2026-01-02 fixed power ldo page
    [clock_tree.kicad_sch, power_ldos.kicad_sch]
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2026-01-03 updated to 16 channel SE
    [adcs.kicad_sch, clock_tree.kicad_sch, coarse_vfo.kicad_sch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]
2026-01-03 changed to 12 phase
    [adcs.kicad_sch, clock_tree.kicad_sch, coarse_vfo.kicad_sch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]
2026-01-03 fixed mixer page
    [clock_tree.kicad_sch, mixers.kicad_sch, rx_tx_mixers.kicad_sch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]
2026-01-03 fixed ldos for Clocks and DAP
    [clock_tree.kicad_sch, crosspoint.kicad_sch, power_ldos.kicad_sch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]
2026-01-03 back to 16 phases
    [adcs.kicad_sch, audio_clock_fanout.kicad_sch, audio_subsystem.kicad_sch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]
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2026-01-04 added holding cap and dc blocking cap
    [mixers.kicad_sch]
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2026-01-04 fixed file names
    [adcs.kicad_sch, audio_clock_fanout.kicad_sch, audio_subsystem.kicad_sch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]
2026-01-04 Add first ADC - References #1
    [adcs.kicad_sch]
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2026-01-04 Further changes to ADC Reference 1
    [adcs.kicad_sch]
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2026-01-04 Further changes to ADC Reference (refs #1)
    [adcs.kicad_sch]
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2026-01-05 Add KLC Compliant DAC (ref #2) - update ADC readme
    [ST_80_2_ADI.step, dacs.kicad_sch]
2026-01-05 Completed update to Rx Mixer. Made it differential with 8 total phases
    [rx_mixer.kicad_sch]
2026-01-05 updates to DAC and DSP symbols (#2 and #3)
    [dacs.kicad_sch]
2026-01-05 Add KLC symbol for ad8676
    [RM_8_ADI.step, rx_driver_amps.kicad_sch, rx_mixer.kicad_sch]
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2026-01-05 add klc compliant 1761
    [CP-32-4_ADI.step, audio_subsystem.kicad_sch]
2026-01-05 add klc compliant mixer
    [DBV0005A.stp, audio_clock_fanout.kicad_sch, rx_mixer.kicad_sch]
2026-01-07 Made adau1467 symbol klc compliant (ref #3)
    [dsp.kicad_sch]
2026-01-07 added 3d model to adau1467 (ref #3)
    [CP_88_8_ADI.step]
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2026-01-10 dsp tdm channels 0-2 added
    [DFN-S8_6x5MC_MCH.step, DPAK_TO-252__TYPEA_STM.step, RA_4_ADI.step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]
2026-01-10 ad9258 kicad compliant (ref#7 closes #8)
    [CP-72-6_ADI.step, ST_80_2_ADI.step]
2026-01-10 ADA4945 KLC Compliant (Ref #7 Closes #9)
    [LFCSP16_ADA4945-1ACPZ-R2_ADI.step]
2026-01-10 Add LT3094 footprint and 3D model - references #7, closes #10
    [DD_05-08-1725_ADI.step]
2026-01-10 make lt5400 klc compliant (ref #7 closes #11)
    [MSOP-8_MS_LIT.step]
2026-01-10 Make LTC1983 KLC compliant (ref #7 closes #14)
    [SOT-23_S6_LIT.step]
2026-01-10 Make SN74CBT3125 KLC compliant (Ref #7 closed #15)
    [PW0014A.stp]
2026-01-10 Rx FDA First Rev Complete
    [adcs.kicad_sch, rx_driver_amps.kicad_sch]
2026-01-10 added buffer to ADC VREF
    [adcs.kicad_sch]
2026-01-10 removed pullups from ADC page and added reminder note to top level
    [adcs.kicad_sch, nzif.kicad_sch]
2026-01-10 removed audio fanout buffer
    [nzif.kicad_sch]
2026-01-10 fixed the transformer selection
    [nzif.kicad_sch]
2026-01-10 fixed Rx Mixer
    [rx_mixer.kicad_sch]
2026-01-10 Make ADAU 1962 KLC compliant (ref #7 closes #20)
    [ST_80_2_ADI.step]
2026-01-11 added caps to fda
    [rx_driver_amps.kicad_sch]
2026-01-11 updates to dsp (ref #3)
    [adcs.kicad_sch, dsp.kicad_sch, rx_mixer.kicad_sch]
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2026-01-11 Further connections to DSP (Ref #3 #25)
    [dsp.kicad_sch, nzif.kicad_sch, rx_driver_amps.kicad_sch]
2026-01-11 fix dsp to be on 100mil grid (Ref #3 #25)
    [dsp.kicad_sch]
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2026-01-11 correct issue with unit a and b of 1467
    [dsp.kicad_sch]
2026-01-13 Continue wiring DAC (Ref #29)
    [SOT223-FZT690B-DN_DIO.step, adcs.kicad_sch, dacs.kicad_sch]
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2026-01-17 removed blocking caps and set holding cap value to 3.3nF
    [rx_mixer.kicad_sch]
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2026-01-17 removed coarse VFO from plan
    [nzif.kicad_sch, rx_mixer.kicad_sch]
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2026-01-17 Add ADA4899-1 (Ref #30 Closes #30)
    [RD_8_1_ADI.step]
2026-01-17 ADA4620 (Ref #1 Closes #31)
    [R-8_ADI.step]
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2026-01-17 added Rx op amp buffers
    [rx_mixer.kicad_sch]
2026-01-17 added 9x gain and set clamps
    [rx_driver_amps.kicad_sch]
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2026-01-17 removed tx mixer page. will fix it
    [tx_mixer.kicad_sch]
2026-01-17 fixed ada4620 symbol
    [rx_mixer.kicad_sch]
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2026-01-18 made minor corrections to dsp schematic
    [dsp.kicad_sch]
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2026-01-24 changed Rx mixer from 8 phase to classic tayloe
    [adcs.kicad_sch, audio_subsystem.kicad_sch, dsp.kicad_sch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]
2026-01-24 reduced number of fdas to match classic tayloe
    [rx_driver_amps.kicad_sch]
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2026-01-24 added tayloe mixer for 160m and 80m Tx
    [tx_mixer.kicad_sch]
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2026-02-01 Add more kicad parts (close #43 close #44)
    [D0016A.stp, DCK0005A.stp, DGG0048A.stp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]
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2026-02-08 updated the clock tree 8 phase Tx and Rx
    [adcs.kicad_sch, audio_subsystem.kicad_sch, clock_tree.kicad_sch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]
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2026-02-14 add ad9523-1 (New Symbol for AD9523-1 Fixes #54)
    [CP-72-7_ADI.step]
2026-02-15 improve readme and driver amp symbol (close #55)
    [rx_driver_amps.kicad_sch, rx_mixer.kicad_sch]
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2026-02-28 reordered sheets - annotate sheets - set all to no sim
    [adcs.kicad_sch, audio_subsystem.kicad_sch, clock_tree.kicad_sch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]
2026-03-01 Add RX mixer documentation, simulation notes, and model updates
    [nzif.kicad_sch, power_ldos.kicad_sch, rx_mixer.kicad_sch]
2026-03-01 Merged ring counter clock tree sheet from branch 57
    [clock_tree.kicad_sch]
2026-03-01 add cts 535 plus fix to clock tree symbols
    [clock_tree.kicad_sch]
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2026-03-01 changed buffer amp to ad4610-4 for better input bias current spec
    [rx_mixer.kicad_sch]
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2026-03-07 add supplies for switches on driver amp sheet
    [adcs.kicad_sch, audio_subsystem.kicad_sch, clock_tree.kicad_sch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]
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2026-03-08 Fix op amps to be correct units
    [clock_tree.kicad_sch, dsp.kicad_sch, microcontroller.kicad_sch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]
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2026-03-22 fixed power on clocktree
    [clock_tree.kicad_sch]
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2026-03-22 updated dac to 8 differential channels, updated output R to 47
    [dacs.kicad_sch]
2026-03-22 fixed the tx mixer to align to dac outputs
    [tx_mixer.kicad_sch]
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2026-03-24 wire top sheet from rf front end through rx driver amps
    [adcs.kicad_sch, audio_subsystem.kicad_sch, clock_tree.kicad_sch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]
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2026-04-12 corrected some errors from erc report
    [power_ldos.kicad_sch, power_switching_reg.kicad_sch]
2026-04-18 minor schematic fixes
    [clock_tree.kicad_sch, power_ldos.kicad_sch, rx_mixer.kicad_sch]
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2026-04-19 Fix ERC errors: symbol pin types and schematic corrections
    [adcs.kicad_sch, audio_subsystem.kicad_sch, clock_tree.kicad_sch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]
2026-04-20 fixed minor erc related issues
    [audio_subsystem.kicad_sch, dacs.kicad_sch, power_ldos.kicad_sch]
2026-04-20 fixing warnings
    [dsp.kicad_sch, microcontroller.kicad_sch]
2026-04-20 fixed remaining ERC errors
    [clock_tree.kicad_sch, dacs.kicad_sch, microcontroller.kicad_sch]
2026-04-21 change a1201 AGND to alternate function - fix U90 GND
    [microcontroller.kicad_sch, power_ldos.kicad_sch]
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2026-05-09 updated switching power feedback resistor values to better range
    [power_switching_reg.kicad_sch]
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2026-05-09 fixed dgnd of ada4945
    [dsp.kicad_sch, rx_driver_amps.kicad_sch]
2026-05-09 fix epad name ada4945
    [rx_driver_amps.kicad_sch]
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2026-05-10 fixed error with selfboot circuit
    [adcs.kicad_sch, dacs.kicad_sch, dsp.kicad_sch]
2026-05-10 fixing erc errors
    [adcs.kicad_sch, dacs.kicad_sch, dsp.kicad_sch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]
2026-05-10 fixed dvdd connection error
    [adcs.kicad_sch, audio_subsystem.kicad_sch, clock_tree.kicad_sch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]
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2026-06-14 fixed dac output filtering
    [dacs.kicad_sch]
2026-06-14 assigned missing footprints
    [adcs.kicad_sch, clock_tree.kicad_sch, dacs.kicad_sch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]
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2026-06-14 added footprints for L that goes with LT8330
    [nzif.kicad_pcb, power_switching_reg.kicad_sch]
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
